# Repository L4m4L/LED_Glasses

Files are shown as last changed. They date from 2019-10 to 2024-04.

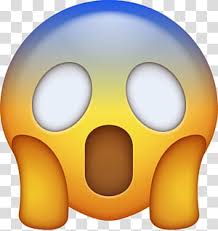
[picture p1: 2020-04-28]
scripts/wow.jpg

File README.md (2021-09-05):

# LED_Glasses
A hobby project aimed at making sound reactive LED glasses that you should take clubbing.

## Hardware

The hardware consists entirely of three PCBs without an enclosure with low profile hinges and a battery system that has yet to be worked out. The PCBs are designed in KiCAD and are as follows:

- The controller arm (`hardware/arm_mcu`) which houses the microcontroller (`STM32G071KBU6`), a microphone (`SPH0641LM4H-1`) and a 3v3 linear regulator.
- The power arm (`hardware/arm_power`) which houses input power protection, an on switch, 5v5 switching regulator and a power good indicator.
- The front display (`hardware/front_display`) which houses the LED matrix (`SK6812MINI`).

## Firmware

`firmware/arduino` contains an early revision of the firmware, with heavy modifications likely in future versions.

Hardware abstraction will be provided by either the STM HAL (pretty bloated and not very intuitive), STM LL (not very intuitive and a bit difficult to parse the many thousand line header files for insight), libopencm3 (haven't tried it but I've heard it's pretty good) or CMSIS (gives us the most control but literally no help haha) (i.e. we haven't decided yet but probably not Arduino).

## TODO

- Read https://github.com/EdwardHartmann/SK6812RGBW for inspiration
- Decide on copyright license
- Investigate smaller LED packages
-

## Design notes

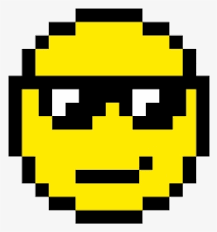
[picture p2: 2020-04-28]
scripts/glasses.png

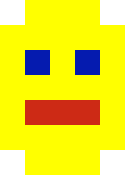
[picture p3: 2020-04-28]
scripts/custom.png

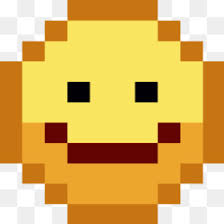
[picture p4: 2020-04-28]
scripts/smile.jpg

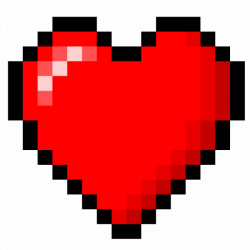
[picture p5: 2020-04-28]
scripts/heart.png

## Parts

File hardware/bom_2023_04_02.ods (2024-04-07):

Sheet: Summary
QTY | 5
 |  |  |  |  |  |  |  |  |  |  |  |  |  | 119.6005 | 71.202208
Type | Value | Package | Description | Board | Item QTY | Total QTY | Have | Remaining | Link | Retailer | Retailer Part Number | Manufacturer Part Number | Item Cost | Total Cost | Per One
buffer | 74LVCH2T45DC,125 | 8-VSSOP | Voltage Level Shifter, Bidirectional, Tri-State, 2 Channel | Controller B Rev 1 | 1 | 5 | 0 | 5 | https://www.digikey.com.au/en/products/detail/nexperia-usa-inc/74LVCH2T45DC-125/2530613 | digikey | 1727-4596-1-ND | 74LVCH2T45DC,125 | 0.9 | 4.5 | 0.9
capacitor | 100n | 0402 (1005) |  | Controller B Rev 1 | 13 | 65 | 100 | 0 | https://www.digikey.com.au/en/products/detail/murata-electronics/GRM155R62A104KE14D/5027543 | digikey | 490-10458-1-ND | GRM155R62A104KE14D | 0.0178 | 0 | 0.2314
capacitor | 100n | 0402 (1005) | 100V | Power Rev 2 | 5 | 25
capacitor | 10n | 0603 (1608) | 5%, 50V, C0G/NP0 | Power Rev 2 | 1 | 5 | 5 | 0 | https://www.digikey.com.au/en/products/detail/murata-electronics/GRM1885C1H103JA01D/4421555 | digikey | 490-9666-1-ND | GRM1885C1H103JA01D | 0.3 | 0 | 0.3
capacitor | 10p | 0402 (1005) | 1%, C0G/NP0 | Controller B Rev 1 | 2 | 10 | 10 | 0 | https://www.digikey.com.au/en/products/detail/yageo/CC0402FRNPO9BN100/5195049 | digikey | 311-1640-1-ND | CC0402FRNPO9BN100 | 0.104 | 0 | 0.208
capacitor | 1u | 0402 (1005) |  | Controller B Rev 1 | 4 | 20 | 50 | 0 | https://www.digikey.com.au/en/products/detail/murata-electronics/GRM155R61E105KA12J/4905140 | digikey | 490-GRM155R61E105KA12JCT-ND | GRM155R61E105KA12J | 0.0294 | 0 | 0.1176
capacitor | 1u | 0402 (1005) |  | Power Rev 2 | 1 | 5
capacitor | 1u | 0603 (1608) |  | Display B Rev 1 | 132 | 660 | 660 | 0 | https://www.digikey.com.au/en/products/detail/samsung-electro-mechanics/CL10B105KP8NFNC/3887603 | digikey | 1276-1945-1-ND | CL10B105KP8NFNC | 0.01334 | 0 | 1.76088
capacitor | 22u | 0805 (2012) |  | Power Rev 2 | 6 | 30 | 28 | 2 | https://www.digikey.com.au/en/products/detail/samsung-electro-mechanics/CL21A226MAYNNNE/10479857 | digikey | 1276-CL21A226MAYNNNECT-ND | CL21A226MAYNNNE | 0.274 | 0.548 | 1.644
capacitor | 2u2 | 1210 (3225) | 100V | Power Rev 2 | 3 | 15 | 15 | 0 | https://www.digikey.com.au/en/products/detail/samsung-electro-mechanics/CL32B225KCJSNNE/3889020 | digikey | 1276-3362-1-ND | CL32B225KCJSNNE | 0.469 | 0 | 1.407
capacitor | 3n9 | 0603 (1608) | 50V, 5%, C0G/NP0 | Power Rev 2 | 1 | 5 | 10 | 0 | https://www.digikey.com.au/en/products/detail/murata-electronics/GCM1885C1H392JA16D/4903747 | digikey | 490-11958-1-ND | GCM1885C1H392JA16D | 0.154 | 0 | 0.154
capacitor | 4u7 | 0402 (1005) |  | Power Rev 2 | 1 | 5 | 10 | 0 | https://www.digikey.com.au/en/products/detail/murata-electronics/GRM155C61E475ME15D/16821133 | digikey | 490-GRM155C61E475ME15DCT-ND | GRM155C61E475ME15D | 0.267 | 0 | 0.267
capacitor | 680p | 0603 (1608) | 50V, %5, C0G/NP0 | Power Rev 2 | 1 | 5 | 10 | 0 | https://www.digikey.com.au/en/products/detail/yageo/CC0603JRNPO9BN681/2833590 | digikey | 311-1425-1-ND | CC0603JRNPO9BN681 | 0.115 | 0 | 0.115
connector | CF35082D0RE-NH |  | 1x8, Female, 0.5 mm, FFC/FPC, SMD, Right Angle, ZIF | Controller B Rev 1 | 1 | 5 | 25 | 0 | https://www.digikey.com.au/en/products/detail/cvilux-usa/CF35082D0RE-NH/15793084 | digikey | 2987-CF35082D0RE-NHCT-ND | CF35082D0RE-NH | 0.3308 | 0 | 0.3308
connector | CF35082D0RE-NH |  | 1x8, Female, 0.5 mm, FFC/FPC, SMD, Right Angle, ZIF | Display B Rev 1 | 2 | 10 | 25 | 0 | https://www.digikey.com.au/en/products/detail/cvilux-usa/CF35082D0RE-NH/15793084 | digikey | 2987-CF35082D0RE-NHCT-ND | CF35082D0RE-NH | 0.3308 | 0 | 0.6616
connector | CF35082D0RE-NH |  | 1x8, Female, 0.5 mm, FFC/FPC, SMD, Right Angle, ZIF | Power Rev 2 | 1 | 5 | 25 | 0 | https://www.digikey.com.au/en/products/detail/cvilux-usa/CF35082D0RE-NH/15793084 | digikey | 2987-CF35082D0RE-NHCT-ND | CF35082D0RE-NH | 0.3308 | 0 | 0.3308
connector | S2B-PH-SM4-TB(LF)(SN) |  | 1x2, Male, 2mm, Header, SMD, Right Angle, Keyed, Shrouded | Power Rev 2 | 1 | 5 | 20 | 0 | https://au.element14.com/jst-japan-solderless-terminals/s2b-ph-sm4-tb-lf-sn/connector-header-smt-r-a-2mm-2way/dp/9492615 | element14 | 9492615 | S2B-PH-SM4-TB(LF)(SN) | 0.745 | 0 | 0.745
connector | 620102131822 |  | 1x2, Male, 2mm, Header, SMD, Right Angle, Keyed, Shrouded | Power Rev 2 | 0 | 0 | 2 | 0 | https://www.digikey.com.au/en/products/detail/würth-elektronik/620102131822/2508480 | digikey | 732-2711-1-ND | 620102131822 | 1.83 | 0
connector | 4048 |  | 2x5, Male, 1.27mm, Header, SMD, Vertical, Keyed, Shrouded | Controller B Rev 1 | 1 | 5 | 4 | 1 | https://www.digikey.com.au/en/products/detail/adafruit-industries-llc/4048/9843412 | digikey | 1528-2827-ND | 4048 | 3.16 | 3.16 | 3.16
connector | 10118192-0002LF |  | USB Micro B, SMD, Right Angle | Controller B Rev 1 | 1 | 5 | 5 | 0 | https://www.digikey.com.au/en/products/detail/amphenol-cs-fci/10118192-0002LF/6817756 | digikey | 609-5379-1-ND | 10118192-0002LF | 0.67 | 0 | 0.67
crystal | ECS-120-10-36B2-CWY-TR |  | 12MHz, 10 pF, 130 ohm, 15 ppm | Controller B Rev 1 | 1 | 5 | 5 | 0 | https://www.digikey.com.au/en/products/detail/ecs-inc/ECS-120-10-36B2-CWY-TR/14548848 | digikey | 50-ECS-120-10-36B2-CWY-TRCT-ND | ECS-120-10-36B2-CWY-TR | 0.65 | 0 | 0.65
diode | D5V0L1B2WS-7 | SOD-323 | TVS Diode, 14V | Power Rev 2 | 1 | 5 | 0 | 5 | https://www.digikey.com.au/en/products/detail/diodes-incorporated/D5V0L1B2WS-7/2918767 | digikey | D5V0L1B2WS-7DICT-ND | D5V0L1B2WS-7 | 0.47 | 2.35 | 0.47
diode | SBRT05U20LPS-7B | 0402 (1005) | Diode, 390 mV @ 500 mA | Controller B Rev 1 | 3 | 15 | 15 | 0 | https://www.digikey.com.au/en/products/detail/diodes-incorporated/SBRT05U20LPS-7B/7666996 | digikey | SBRT05U20LPS-7BDICT-ND | SBRT05U20LPS-7B | 0.483 | 0 | 1.449
fuse | SBF32302ASTP | 1206 (3216) | 3A, 32V, 24mOhms | Power Rev 2 | 1 | 5 | 10 | 0 | https://www.digikey.com.au/en/products/detail/kamaya-inc/SBF32302ASTP/15181289 | digikey | 2315-SBF32302ASTPCT-ND | SBF32302ASTP | 0.332 | 0 | 0.332
inductor | 15u |  |  | Power Rev 2 | 1 | 5 | 5 | 0 | https://www.digikey.com.au/en/products/detail/kemet/MPXV1D1054L150/11314646 | digikey | 399-MPXV1D1054L150CT-ND | MPXV1D1054L150 | 2.62 | 0 | 2.62
led | APA102-2020 |  |  | Display B Rev 1 | 150 | 750 | 200 | 550 | https://www.aliexpress.com/item/10000013471219.html | aliexpress |  |  | 0.18935 | 104.1425 | 28.4025
memory | W25Q16JVZPIQ | 8-WSON (6x5 mm) | Flash, NOR, 16Mbit, Quad SPI, 133 MHz | Controller B Rev 1 | 1 | 5 | 0 | 5 | https://www.digikey.com.au/en/products/detail/winbond-electronics/W25Q16JVZPIQ/6193770 | digikey | W25Q16JVZPIQ-ND | W25Q16JVZPIQ | 0.98 | 4.9 | 0.98
microcontroller | RP2040 | QFN-56 (7x7mm) | ARM Cortex-M0+, 133 MHz | Controller B Rev 1 | 1 | 5 | 20 | 0 | https://www.digikey.com.au/en/products/detail/raspberry-pi/SC0914-7/14306009 | digikey | 2648-SC0914(7)CT-ND | SC0914(7) | 1.25 | 0 | 1.25
microphone | SPK0641HT4H-1 |  | MEMS Microphone, PDM, 20 – 20000 Hz | Controller B Rev 1 | 1 | 5 | 6 | 0 | https://www.digikey.com.au/en/products/detail/knowles/SPK0641HT4H-1/8573345 | digikey | 423-1425-1-ND | SPK0641HT4H-1 | 2.43 | 0 | 2.43
mosfet | AONR21357 | 8-PowerVDFN |  | Power Rev 2 | 1 | 5 | 5 | 0 | https://www.digikey.com.au/en/products/detail/alpha-omega-semiconductor-inc/AONR21357/9664230 | digikey | 785-AONR21357CT-ND | AONR21357 | 1.09 | 0 | 1.09
mosfet | SSM6N7002KFU,LF | 6-TSSOP | N MOSFET, 2 Channel, Vgs = 2.1V, SOT-363 | Controller B Rev 1 | 1 | 5 | 5 | 0 | https://www.digikey.com.au/en/products/detail/toshiba-semiconductor-and-storage/SSM6N7002KFU-LF/5810234 | digikey | SSM6N7002KFULFCT-ND | SSM6N7002KFU,LF | 0.39 | 0 | 0.39
mov | MLVA06V26C100-R | 0603 (1608) |  | Power Rev 2 | 1 | 5 | 10 | 0 | https://www.digikey.com.au/en/products/detail/eaton-electronics-division/MLVA06V26C100-R/5964319 | digikey | 283-4667-1-ND | MLVA06V26C100-R | 0.454 | 0 | 0.454
resistor | 10k | 0402 (1005) | 1%, | Controller B Rev 1 | 3 | 15 | 100 | 0 | https://www.digikey.com.au/en/products/detail/bourns-inc/CR0402-FX-1002GLF/3593192 | digikey | CR0402-FX-1002GLFCT-ND | CR0402-FX-1002GLF | 0.0087 | 0 | 0.0261
resistor | 10k | 0402 (1005) | 1%, | Power Rev 2 | 4 | 20
resistor | 15k | 0402 (1005) | 1%, | Controller B Rev 1 | 1 | 5 | 10 | 0 | https://www.digikey.com.au/en/products/detail/yageo/RC0402FR-0715KL/726541 | digikey | 311-15.0KLRCT-ND | RC0402FR-0715KL | 0.023 | 0 | 0.023
resistor | 160k | 0402 (1005) | 1%, | Power Rev 2 | 1 | 5 | 10 | 0 | https://www.digikey.com.au/en/products/detail/stackpole-electronics-inc/RMCF0402FT160K/1714462 | digikey | RMCF0402FT160KCT-ND | RMCF0402FT160K | 0.022 | 0 | 0.022
resistor | 18k | 0402 (1005) | 1%, | Power Rev 2 | 1 | 5 | 10 | 0 | https://www.digikey.com.au/en/products/detail/yageo/RC0402FR-0718KL/726548 | digikey | 311-18.0KLRCT-ND | RC0402FR-0718KL | 0.023 | 0 | 0.023
resistor | 1k | 0402 (1005) | 1%, | Controller B Rev 1 | 2 | 10 | 10 | 0 | https://www.digikey.com.au/en/products/detail/yageo/AC0402FR-131KL/14008372 | digikey | 13-AC0402FR-131KLCT-ND | AC0402FR-131KL | 0.03 | 0 | 0.06
resistor | 27R | 0402 (1005) | 1%, | Controller B Rev 1 | 2 | 10 | 10 | 0 | https://www.digikey.com.au/en/products/detail/yageo/RC0402FR-0727RL/5280946 | digikey | YAG3086CT-ND | RC0402FR-0727RL | 0.023 | 0 | 0.046
resistor | 300k | 0402 (1005) | 0.5%, | Power Rev 2 | 1 | 5 | 10 | 0 | https://www.digikey.com.au/en/products/detail/koa-speer-electronics-inc/RK73H1ETTP3003D/9853472 | digikey | 2019-RK73H1ETTP3003DCT-ND | RK73H1ETTP3003D | 0.371 | 0 | 0.371
resistor | 390k | 0402 (1005) | 1%, | Power Rev 2 | 1 | 5 | 10 | 0 | https://www.digikey.com.au/en/products/detail/yageo/RC0402FR-07390KL/5281003 | digikey | YAG3143CT-ND | RC0402FR-07390KL | 0.023 | 0 | 0.023
resistor | 3R3 | 0402 (1005) | 1%, | Power Rev 2 | 1 | 5 | 10 | 0 | https://www.digikey.com.au/en/products/detail/yageo/RC0402FR-073R3L/1037049 | digikey | 311-3.30LRCT-ND | RC0402FR-073R3L | 0.033 | 0 | 0.033
resistor | 47k5 | 0402 (1005) | 1%, | Power Rev 2 | 1 | 5 | 10 | 0 | https://www.digikey.com.au/en/products/detail/yageo/RC0402FR-0747K5L/726617 | digikey | 311-47.5KLRCT-ND | RC0402FR-0747K5L | 0.023 | 0 | 0.023
resistor | 52k3 | 0402 (1005) | 1%, | Power Rev 2 | 1 | 5 | 10 | 0 | https://www.digikey.com.au/en/products/detail/yageo/RC0402FR-0752K3L/5281039 | digikey | YAG3179CT-ND | RC0402FR-0752K3L | 0.023 | 0 | 0.023
resistor | 62k | 0402 (1005) | 1%, | Power Rev 2 | 1 | 5 | 10 | 0 | https://www.digikey.com.au/en/products/detail/yageo/RC0402FR-0762KL/726645 | digikey | 311-62.0KLRCT-ND | RC0402FR-0762KL | 0.023 | 0 | 0.023
resistor | 75k | 0402 (1005) | 1%, | Controller B Rev 1 | 1 | 5 | 10 | 0 | https://www.digikey.com.au/en/products/detail/bourns-inc/CR0402-FX-7502GLF/3783488 | digikey | CR0402-FX-7502GLFCT-ND | CR0402-FX-7502GLF | 0.019 | 0 | 0.019
resistor | 88k7 | 0402 (1005) | 1%, | Power Rev 2 | 1 | 5 | 10 | 0 | https://www.digikey.com.au/en/products/detail/yageo/RC0402FR-0788K7L/726667 | digikey | 311-88.7KLRCT-ND | RC0402FR-0788K7L | 0.023 | 0 | 0.023
resistor | 8k66 | 0402 (1005) | 1%, | Power Rev 2 | 1 | 5 | 10 | 0 | https://www.digikey.com.au/en/products/detail/yageo/RC0402FR-078K66L/5281115 | digikey | YAG3255CT-ND | RC0402FR-078K66L | 0.023 | 0 | 0.023
resistor array | 10k | 0804 Convex | 4x Resistor Array, Isolated | Controller B Rev 1 | 1 | 5 | 5 | 0 | https://www.digikey.com.au/en/products/detail/panasonic-electronic-components/EXB-28V103JX/256299 | digikey | Y7103CT-ND | EXB-28V103JX | 0.16 | 0 | 0.16
switch | User Buttons |  | Tactile, SMD, Right Angle, SPSP-NO | Controller B Rev 1 | 2 | 10 | 10 | 0 | https://www.digikey.com.au/en/products/detail/panasonic-electronic-components/EVQ-P7A01P/4429447 | digikey | P16763CT-ND | EVQ-P7A01P | 0.464 | 0 | 0.928
voltage regulator | 3V3 Linear Regulator | TSOT-23-5 | 300 mA | Controller B Rev 1 | 1 | 5 | 5 | 0 | https://www.digikey.com.au/en/products/detail/onsemi/NCP115ASN330T2G/9764776 | digikey | NCP115ASN330T2GOSCT-ND | NCP115ASN330T2G | 0.53 | 0 | 0.53
voltage regulator | SIC473 | Vishay PowerPAK MLP55-27 |  | Power Rev 2 | 1 | 5 | 5 | 0 | https://www.digikey.com.au/en/products/detail/vishay-siliconix/SIC473ED-T1-GE3/9556547 | digikey | SIC473ED-T1-GE3CT-ND | SIC473ED-T1-GE3 | 5.44 | 0 | 5.44
cable | MP-FFCA05080502A |  | 1x8, Male, 0.5 mm, FFC/FPC, 50mm, Same Sided Contacts |  | 2 | 10 | 50 | 0 | https://au.element14.com/multicomp-pro/mp-ffca05080502a/ffc-cord-8p-same-side-50mm-wht/dp/3385165 | element14 | 3385165 | MP-FFCA05080502A | 1.39 | 0 | 2.78
cable | 151660075 |  | 1x8, Male, 0.5 mm, FFC/FPC, 50mm, Same Sided Contacts |  | 0 | 0 | 2 | 0 | https://www.digikey.com.au/en/products/detail/molex/0151660075/3280957 | digikey | WM11299-ND | 151660075 | 3.76 | 0 | 0
cable | 151660073 |  | 1x8, Male, 0.5 mm, FFC/FPC, 30mm, Same Sided Contacts |  | 0 | 0 | 2 | 0 | https://www.digikey.com.au/en/products/detail/molex/0151660075/3280957 | digikey | 0151660073-ND | 151660073 | 3.76 | 0 | 0
screws |  |  | M1.4x3.5mm |  | 8 | 40 | 100 | 0 | https://www.aliexpress.com/item/10000181324125.html | aliexpress |  |  | 0.0207 | 0 | 0.1656
hinges |  |  |  |  | 2 | 10 | 60 | 0 | https://www.aliexpress.com/item/1005003373487703.html | aliexpress |  |  | 0.222 | 0 | 0.444

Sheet: Controller B Rev 1
Type | Value | Package | Description | Link | Retailer Part Number | Manufacturer Part Number | Item QTY | Reference Designator
capacitor | 1u | 0402 (1005) |  | https://www.digikey.com.au/en/products/detail/murata-electronics/GRM155R61E105KA12J/4905140 | 490-GRM155R61E105KA12JCT-ND | GRM155R61E105KA12J | 4 | C101, C102, C105, C106
capacitor | 100n | 0402 (1005) |  | https://www.digikey.com.au/en/products/detail/murata-electronics/GRM155R62A104KE14D/5027543 | 490-10458-1-ND | GRM155R62A104KE14D | 13 | C103, C104, C107, C108, C109, C110, C111, C112, C113, C114, C115, C116, C117
capacitor | 10p | 0402 (1005) | 1%, C0G/NP0 | https://www.digikey.com.au/en/products/detail/yageo/CC0402FRNPO9BN100/5195049 | 311-1640-1-ND | CC0402FRNPO9BN100 | 2 | C118, C119
diode | SBRT05U20LPS-7B | 0402 (1005) | Diode, 390 mV @ 500 mA | https://www.digikey.com.au/en/products/detail/diodes-incorporated/SBRT05U20LPS-7B/7666996 | SBRT05U20LPS-7BDICT-ND | SBRT05U20LPS-7B | 3 | D101, D102, D103
connector | CF35082D0RE-NH |  | 1x8, Female, 0.5 mm, FFC/FPC, SMD, Right Angle, ZIF | https://www.digikey.com.au/en/products/detail/cvilux-usa/CF35082D0RE-NH/15793084 | 2987-CF35082D0RE-NHCT-ND | CF35082D0RE-NH | 1 | J101
connector | 4048 |  | 2x5, Male, 1.27mm, Header, SMD, Vertical, Keyed, Shrouded | https://www.digikey.com.au/en/products/detail/adafruit-industries-llc/4048/9843412 | 1528-2827-ND | 4048 | 1 | J102
connector | 10118192-0002LF |  | USB Micro B, SMD, Right Angle | https://www.digikey.com.au/en/products/detail/amphenol-cs-fci/10118192-0002LF/6817756 | 609-5379-1-ND | 10118192-0002LF | 1 | J103
microphone | SPK0641HT4H-1 | SMD | MEMS Microphone, PDM, 20 – 20000 Hz | https://www.digikey.com.au/en/products/detail/knowles/SPK0641HT4H-1/8573345 | 423-1425-1-ND | SPK0641HT4H-1 | 1 | MK101
mosfet | SSM6N7002KFU,LF | 6-TSSOP | N MOSFET, 2 Channel, Vgs = 2.1V, SOT-363 | https://www.digikey.com.au/en/products/detail/toshiba-semiconductor-and-storage/SSM6N7002KFU-LF/5810234 | SSM6N7002KFULFCT-ND | SSM6N7002KFU,LF | 1 | Q101
resistor | 75k | 0402 (1005) | 1%, | https://www.digikey.com.au/en/products/detail/bourns-inc/CR0402-FX-7502GLF/3783488 | CR0402-FX-7502GLFCT-ND | CR0402-FX-7502GLF | 1 | R101
resistor | 10k | 0402 (1005) | 1%, | https://www.digikey.com.au/en/products/detail/bourns-inc/CR0402-FX-1002GLF/3593192 | CR0402-FX-1002GLFCT-ND | CR0402-FX-1002GLF | 3 | R102, R106, R107
resistor | 27R | 0402 (1005) | 1%, | https://www.digikey.com.au/en/products/detail/yageo/RC0402FR-0727RL/5280946 | YAG3086CT-ND | RC0402FR-0727RL | 2 | R104, R105
resistor | 1k | 0402 (1005) | 1%, | https://www.digikey.com.au/en/products/detail/yageo/AC0402FR-131KL/14008372 | 13-AC0402FR-131KLCT-ND | AC0402FR-131KL | 2 | R108, R109
resistor | 15k | 0402 (1005) | 1%, | https://www.digikey.com.au/en/products/detail/yageo/RC0402FR-0715KL/726541 | 311-15.0KLRCT-ND | RC0402FR-0715KL | 1 | R110
resistor array | 10k | 0804 Convex | 4x Resistor Array, Isolated | https://www.digikey.com.au/en/products/detail/panasonic-electronic-components/EXB-28V103JX/256299 | Y7103CT-ND | EXB-28V103JX | 1 | RN101
switch | EVQ-P7A01P | SMD, Right Angle | Tactile, SPSP-NO | https://www.digikey.com.au/en/products/detail/panasonic-electronic-components/EVQ-P7A01P/4429447 | P16763CT-ND | EVQ-P7A01P | 2 | SW101, SW102
voltage regulator | NCP115ASN330T2G | TSOT-23-5 | Linear Regulator, 3.3 V, 300 mA | https://www.digikey.com.au/en/products/detail/onsemi/NCP115ASN330T2G/9764776 | NCP115ASN330T2GOSCT-ND | NCP115ASN330T2G | 1 | U101
buffer | 74LVCH2T45DC,125 | 8-VSSOP | Voltage Level Shifter, Bidirectional, Tri-State, 2 Channel | https://www.digikey.com.au/en/products/detail/nexperia-usa-inc/74LVCH2T45DC-125/2530613 | 1727-4596-1-ND | 74LVCH2T45DC,125 | 1 | U102
buffer | 74LVC2T45HK3-7 | 8-XFDFN | Voltage Level Shifter, Bidirectional, Tri-State, 2 Channel | https://www.digikey.com.au/en/products/detail/diodes-incorporated/74LVC2T45HK3-7/13684787 | 31-74LVC2T45HK3-7CT-ND | 74LVC2T45HK3-7 | 0 | ~
microcontroller | RP2040 | QFN-56 (7x7mm) | ARM Cortex-M0+, 133 MHz | https://www.digikey.com.au/en/products/detail/raspberry-pi/SC0914-7/14306009 | 2648-SC0914(7)CT-ND | SC0914(7) | 1 | U103
memory | W25Q16JVZPIQ | 8-WSON (6x5 mm) | Flash, NOR, 16Mbit, Quad SPI, 133 MHz | https://www.digikey.com.au/en/products/detail/winbond-electronics/W25Q16JVZPIQ/6193770 | W25Q16JVZPIQ-ND | W25Q16JVZPIQ | 1 | U104
memory | W25Q16JVUXIQ | 8-USON | Flash, NOR, 16Mbit, Quad SPI, 133 MHz | https://www.digikey.com.au/en/products/detail/winbond-electronics/W25Q16JVUXIQ-TR/15182017 | 256-W25Q16JVUXIQTRCT-ND | W25Q16JVUXIQ TR | 0 | ~
crystal | ECS-120-10-36B2-CWY-TR |  | 12MHz, 10 pF, 130 ohm, 15 ppm | https://www.digikey.com.au/en/products/detail/ecs-inc/ECS-120-10-36B2-CWY-TR/14548848 | 50-ECS-120-10-36B2-CWY-TRCT-ND | ECS-120-10-36B2-CWY-TR | 1 | Y101

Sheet: Display B Rev 1
Type | Value | Package | Description | Link | Retailer Part Number | Manufacturer Part Number | Item QTY | Reference Designator
capacitor | 1u | 0603 (1608) |  | https://www.digikey.com.au/en/products/detail/samsung-electro-mechanics/CL10B105KP8NFNC/3887603 | 1276-1945-1-ND | CL10B105KP8NFNC | 132 | C101, C102, C103, C104, C105, C106, C107, C108, C109, C110, C111, C112, C113, C114, C115, C116, C117, C118, C119, C120, C121, C122, C123, C124, C125, C126, C127, C128, C129, C130, C131, C132, C133, C134, C135, C136, C137, C138, C139, C140, C141, C142, C143, C144, C145, C146, C147, C148, C149, C150, C151, C152, C153, C154, C155, C156, C157, C158, C159, C160, C161, C162, C163, C164, C165, C166, C167, C168, C169, C170, C171, C172, C173, C174, C175, C176, C177, C178, C179, C180, C181, C182, C183, C184, C185, C186, C187, C188, C189, C190, C191, C192, C193, C194, C195, C196, C197, C198, C199, C200, C201, C202, C203, C204, C205, C206, C207, C208, C209, C210, C211, C212, C213, C214, C215, C216, C217, C218, C219, C220, C221, C222, C223, C224, C225, C226, C227, C228, C229, C230, C231, C232
connector | CF35082D0RE-NH |  | 1x8, Female, 0.5 mm, FFC/FPC, SMD, Right Angle, ZIF | https://www.digikey.com.au/en/products/detail/cvilux-usa/CF35082D0RE-NH/15793084 | 2987-CF35082D0RE-NHCT-ND | CF35082D0RE-NH | 150 | D101, D102, D103, D104, D107, D108, D109, D110, D111, D112, D113, D114, D115, D116, D117, D118, D119, D120, D121, D122, D123, D124, D125, D126, D127, D128, D129, D130, D131, D132, D133, D134, D135, D136, D137, D138, D139, D140, D142, D143, D144, D145, D146, D147, D148, D149, D151, D152, D153, D154, D155, D156, D157, D158, D160, D161, D162, D163, D164, D165, D166, D167, D169, D170, D172, D173, D174, D175, D176, D178, D179, D180, D182, D183, D185, D187, D188, D189, D191, D192, D193, D194, D195, D196, D197, D199, D200, D202, D203, D204, D205, D206, D207, D208, D209, D210, D211, D212, D213, D214, D215, D216, D217, D218, D219, D220, D221, D222, D223, D224, D225, D226, D228, D229, D230, D231, D232, D233, D234, D235, D237, D238, D239, D240, D241, D242, D243, D244, D246, D247, D248, D249, D250, D251, D252, D253, D255, D256, D257, D258, D259, D260, D261, D262, D264, D265, D266, D267, D270, D271
led | APA102-2020 |  |  | https://www.aliexpress.com/item/10000013471219.html |  |  | 2 | J101, J102

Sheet: Power Rev 2
Type | Value | Package | Description | Link | Retailer Part Number | Manufacturer Part Number | Item QTY | Reference Designator
capacitor | 2u2 | 1210 (3225) | 100V | https://www.digikey.com.au/en/products/detail/samsung-electro-mechanics/CL32B225KCJSNNE/3889020 | 1276-3362-1-ND | CL32B225KCJSNNE | 3 | C101, C102, C103
capacitor | 100n | 0402 (1005) | 100V | https://www.digikey.com.au/en/products/detail/murata-electronics/GRM155R62A104KE14D/5027543 | 490-10458-1-ND | GRM155R62A104KE14D | 5 | C104, C105, C106, C118, C119
capacitor | 22u | 0805 (2012) |  | https://www.digikey.com.au/en/products/detail/samsung-electro-mechanics/CL21A226MAYNNNE/10479857 | 1276-CL21A226MAYNNNECT-ND | CL21A226MAYNNNE | 6 | C107, C108, C109, C110, C111, C112
capacitor | 10n | 0603 (1608) | 5%, 50V, C0G/NP0 | https://www.digikey.com.au/en/products/detail/murata-electronics/GRM1885C1H103JA01D/4421555 | 490-9666-1-ND | GRM1885C1H103JA01D | 1 | C113
capacitor | 4u7 | 0402 (1005) |  | https://www.digikey.com.au/en/products/detail/murata-electronics/GRM155C61E475ME15D/16821133 | 490-GRM155C61E475ME15DCT-ND | GRM155C61E475ME15D | 1 | C114
capacitor | 1u | 0402 (1005) |  | https://www.digikey.com.au/en/products/detail/murata-electronics/GRM155R61E105KA12J/4905140 | 490-GRM155R61E105KA12JCT-ND | GRM155R61E105KA12J | 1 | C115
capacitor | 3n9 | 0603 (1608) | 50V, 5%, C0G/NP0 | https://www.digikey.com.au/en/products/detail/murata-electronics/GCM1885C1H392JA16D/4903747 | 490-11958-1-ND | GCM1885C1H392JA16D | 1 | C116
capacitor | 680p | 0603 (1608) | 50V, %5, C0G/NP0 | https://www.digikey.com.au/en/products/detail/yageo/CC0603JRNPO9BN681/2833590 | 311-1425-1-ND | CC0603JRNPO9BN681 | 1 | C117
diode | D5V0L1B2WS-7 | SOD-323 | TVS Diode, 14V | https://www.digikey.com.au/en/products/detail/diodes-incorporated/D5V0L1B2WS-7/2918767 | D5V0L1B2WS-7DICT-ND | D5V0L1B2WS-7 | 1 | D101
diode | ESDA17P20-1F2 | SOD-882 | TVS Diode, 15V | https://www.digikey.com.au/en/products/detail/stmicroelectronics/ESDA17P20-1F2/13592620 | 497-ESDA17P20-1F2CT-ND | ESDA17P20-1F2 | 0 | ~
fuse | SBF32302ASTP | 1206 (3216) | 3A, 32V, 24mOhms | https://www.digikey.com.au/en/products/detail/kamaya-inc/SBF32302ASTP/15181289 | 2315-SBF32302ASTPCT-ND | SBF32302ASTP | 1 | F101
connector | CF35082D0RE-NH |  | 1x8, Female, 0.5 mm, FFC/FPC, SMD, Right Angle, ZIF | https://www.digikey.com.au/en/products/detail/cvilux-usa/CF35082D0RE-NH/15793084 | 2987-CF35082D0RE-NHCT-ND | CF35082D0RE-NH | 1 | J101
connector | S2B-PH-SM4-TB(LF)(SN) |  | 1x2, Male, 2mm, Header, SMD, Right Angle, Keyed, Shrouded | https://au.element14.com/jst-japan-solderless-terminals/s2b-ph-sm4-tb-lf-sn/connector-header-smt-r-a-2mm-2way/dp/9492615 | 9492615 | S2B-PH-SM4-TB(LF)(SN) | 1 | J102
inductor | 15u |  |  | https://www.digikey.com.au/en/products/detail/kemet/MPXV1D1054L150/11314646 | 399-MPXV1D1054L150CT-ND | MPXV1D1054L150 | 1 | L101
mosfet | AONR21357 | 8-PowerVDFN |  | https://www.digikey.com.au/en/products/detail/alpha-omega-semiconductor-inc/AONR21357/9664230 | 785-AONR21357CT-ND | AONR21357 | 1 | Q101
resistor | 10k | 0402 (1005) | 1%, | https://www.digikey.com.au/en/products/detail/bourns-inc/CR0402-FX-1002GLF/3593192 | CR0402-FX-1002GLFCT-ND | CR0402-FX-1002GLF | 4 | R101, R107, R109, R114
resistor | 8k66 | 0402 (1005) | 1%, | https://www.digikey.com.au/en/products/detail/yageo/RC0402FR-078K66L/5281115 | YAG3255CT-ND | RC0402FR-078K66L | 1 | R102
resistor | 47k5 | 0402 (1005) | 1%, | https://www.digikey.com.au/en/products/detail/yageo/RC0402FR-0747K5L/726617 | 311-47.5KLRCT-ND | RC0402FR-0747K5L | 1 | R103
resistor | 52k3 | 0402 (1005) | 1%, | https://www.digikey.com.au/en/products/detail/yageo/RC0402FR-0752K3L/5281039 | YAG3179CT-ND | RC0402FR-0752K3L | 1 | R104
resistor | 62k | 0402 (1005) | 1%, | https://www.digikey.com.au/en/products/detail/yageo/RC0402FR-0762KL/726645 | 311-62.0KLRCT-ND | RC0402FR-0762KL | 1 | R105
resistor | 3R3 | 0402 (1005) | 1%, | https://www.digikey.com.au/en/products/detail/yageo/RC0402FR-073R3L/1037049 | 311-3.30LRCT-ND | RC0402FR-073R3L | 1 | R106
resistor | 18k | 0402 (1005) | 1%, | https://www.digikey.com.au/en/products/detail/yageo/RC0402FR-0718KL/726548 | 311-18.0KLRCT-ND | RC0402FR-0718KL | 1 | R108
resistor | 160k | 0402 (1005) | 1%, | https://www.digikey.com.au/en/products/detail/stackpole-electronics-inc/RMCF0402FT160K/1714462 | RMCF0402FT160KCT-ND | RMCF0402FT160K | 1 | R110
resistor | 390k | 0402 (1005) | 1%, | https://www.digikey.com.au/en/products/detail/yageo/RC0402FR-07390KL/5281003 | YAG3143CT-ND | RC0402FR-07390KL | 1 | R111
resistor | 88k7 | 0402 (1005) | 1%, | https://www.digikey.com.au/en/products/detail/yageo/RC0402FR-0788K7L/726667 | 311-88.7KLRCT-ND | RC0402FR-0788K7L | 1 | R112
resistor | 300k | 0402 (1005) | 0.5%, | https://www.digikey.com.au/en/products/detail/koa-speer-electronics-inc/RK73H1ETTP3003D/9853472 | 2019-RK73H1ETTP3003DCT-ND | RK73H1ETTP3003D | 1 | R113
mov | MLVA06V26C100-R | 0603 (1608) |  | https://www.digikey.com.au/en/products/detail/eaton-electronics-division/MLVA06V26C100-R/5964319 | 283-4667-1-ND | MLVA06V26C100-R | 1 | RV101
voltage regulator | SIC473 | Vishay PowerPAK MLP55-27 |  | https://www.digikey.com.au/en/products/detail/vishay-siliconix/SIC473ED-T1-GE3/9556547 | SIC473ED-T1-GE3CT-ND | SIC473ED-T1-GE3 | 1 | U101
connector | 620102131822 |  | 1x2, Male, 2mm, Header, SMD, Right Angle, Keyed, Shrouded | https://www.digikey.com.au/en/products/detail/würth-elektronik/620102131822/2508480 | 732-2711-1-ND | 620102131822 | 0

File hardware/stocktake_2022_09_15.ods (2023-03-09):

type | desc pri | desc sec | qty | retailer | part number | package | package imp | package metric | link
bjt | npn |  | 5 | digikey | mmbt3904tpmsct-nd | sot23
button | tactile spst | spst-no vertical | 4 | digikey | ckn10779ct-nd | 3x2mm
button | tactile spst | spst-no vertical | 1 | digikey | pts647sm50smtr2lfsct-nd | 4.5x4.5x5mm
capacitor | 100n | 50v x7r 20% | 128 | digikey | 1276-2450-1-nd |  | 805 | 2012
capacitor | 100n | 25v x7r 20% | 7 | mouser | 80-c0805c104m3r |  | 805 | 2012
capacitor | 10n | 50v x7r | 9 | digikey | 1276-1015-1-nd |  | 805 | 2012
capacitor | 10p | 50v c0g/np0 | 8 | digikey | 1276-1109-1-nd |  | 805 | 2012
capacitor | 10u | 50v x5r 20% | 6 | digikey | 1276-6736-1-nd |  | 1206 | 3216
capacitor | 2n2 | 50v x7r | 9 | digikey | 399-1151-1-nd |  | 805 | 2012
capacitor | 22u | 25v x5r 20% | 28 | mouser | 81-grm21br61e226me4k |  | 805 | 2012
capacitor | 4u7 | 25v x5r 10% | 12 | digikey | 1276-1244-1-nd |  | 805 | 2012
connector | micro sd | hinged smt | 1 | digikey | 2073-mem2067-02-180-00-act-nd
connector | usb micro b | smt | 1 | digikey | 609-4618-1-nd
crystal | 12mhz | 25ppm 10pf 150r | 1 | digikey | xc2722ct-nd | 4-smd |  | 2.5x2
diode schottky | 0a5 | vf 0.385v | 7 | digikey | mbr0520lt1gosct-nd | sod-123
diode schottky | 4a | vf 0.660v | 1 | digikey | nrvtsa4100t3gosct-nd | do-214ac
diode tvs | 24v |  | 1 | digikey | nup2105lt1gosct-nd | sot-23-3
diode tvs | 5v25 | usb protection | 1 | digikey | 497-5235-1-nd | sot23-6
diode tvs | 5v | 3a vclamp 7.2v | 7 | mouser | 621-desd5v0u1ba-7 | sod-323-2
fuse | 2a | 0.068r fast blow | 7 | mouser | 530-c1f2 |  | 1206
header | 2-pin | terminal block screw 3.5mm pitch | 1 | digikey | 277-1721-nd
header | 2-pin male | jst-ph 2-pin smt shrouded keyed | 2 | mouser | 485-1769
header | 4-pin | terminal block screw 3.5mm pitch | 1 | digikey | 277-1860-nd
header | double row 0.1” pitch male | 2x10 vertical through hole | 1 | digikey
header | single row 0.1” pitch female | 8pos vertical through hole | 2 | digikey | s7006-nd
header | single row 0.1” pitch male | 1x20 vertical through hole | 1 | digikey
ic | thermocouple to digital converter |  | 1 | digikey | max31855kasa+tct-nd | 8-soic
ic | thermocouple to digital converter | max31855 | 1 | digikey | max31855kasa+tct-nd | 8-soic
ic | uart to usb converter | ft232rl | 1
inductor | 15u | 3.6a 0.05r 20% | 1 | digikey | srn8040ta-150mct-nd | 8x8mm
inductor | 1u | 3.6a 0.0252r 30% | 7 | mouser | 963-nrs5020t1r0nmgj |  |  | 4.9x4.9
led | apa102 | spi 2020 | 200 | aliexpress |  | 2x2mm |  |  | https://www.aliexpress.com/i/10000013471219.html
led | blue |  | 3 | digikey | 732-4982-1-nd |  | 805 | 2012
led | green | 40mcd | 7 | mouser | 710-150080vs75000 |  | 805 | 2012
led | green |  | 3 | digikey | 732-4986-1-nd |  | 805 | 2012
led | red |  | 4 | digikey | 732-4984-1-nd |  | 805 | 2012
led | sk6812mini | 200mw pwm | ~260 | aliexpress |  | 3.5x3.7x0.95mm
microcontroller | stm32g071kbu6 |  | 2 | digikey | 479-18357-nd
microphone | bottom port, digital, pdm |  | 2 | digikey | 423-1395-1-nd
mosfet | 1 p-channel | vds 12v id 3a vth 0.9v | 6 | mouser | 781-si2315bds-ge3 | to-236-3
mosfet | 2 n-channel | vds 60v id 0.3a vth 2.1v | 2 | digikey | ssm6n7002kfulfct-nd | 6-tssop
piezo buzzer |  |  | 1 | digikey | 490-4698-1-nd | through hole
resistor | 270 | 100mw 0.5% | 7 | mouser | 754-rr1220p-271d |  | 805 | 2012
resistor | 1000k | 125mw 0.5% | 7 | mouser | 667-era-6aed105v |  | 805 | 2012
resistor | 100k | 1/8w 1% | 29 | digikey | rmcf0805ft100kct-nd |  | 805 | 2012
resistor | 15k | 1/8w 1% | 6 | digikey | a129763ct-nd |  | 805 | 2012
resistor | 1k5 | 1/8w 1% | 7 | digikey | a106057ct-nd |  | 805 | 2012
resistor | 270r | 1/8w 1% | 16 | digikey | 311-270crct-nd |  | 805 | 2012
resistor | 5k6 | 1/8w 1% | 7 | digikey | a126380ct-nd |  | 805 | 2012
switch | slide dpdt | 300ma 6v | 7 | digikey | 401-2002-1-nd
voltage regulator | 3v3 | linear 0.3a vin 3v5-5v5 | 3 | digikey | 576-4764-1-nd | sot-23-5
voltage regulator | 5v switching | boost-buck 2.25a vin 2.5-12v 2.4mhz | 2 | mouser | 595-tps63061dscr | wson-10

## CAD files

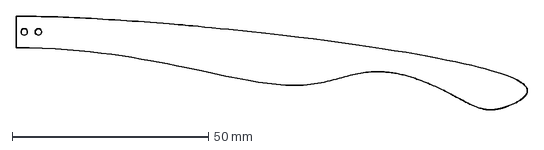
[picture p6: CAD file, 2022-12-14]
hardware/template_arm_b_r1/template_arm_b_r1_2.dxf
130.2 x 23.8 mm

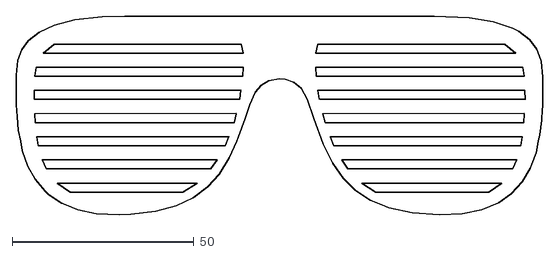
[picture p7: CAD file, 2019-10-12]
hardware/template_display_a_r1/display_template_a_r1.dxf
144.7 x 54.6

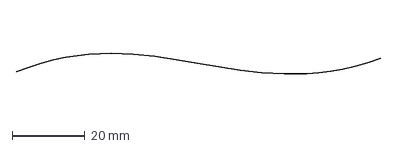
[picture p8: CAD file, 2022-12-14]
hardware/template_display_b_r1/test2.dxf
100.3 x 25.3 mm

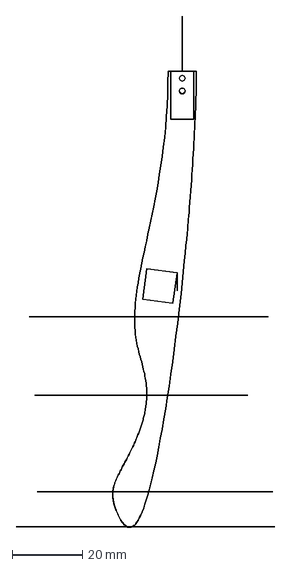
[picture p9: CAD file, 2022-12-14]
hardware/template_arm_b_r1/template_arm_b_r1.dxf
73.7 x 145.8 mm

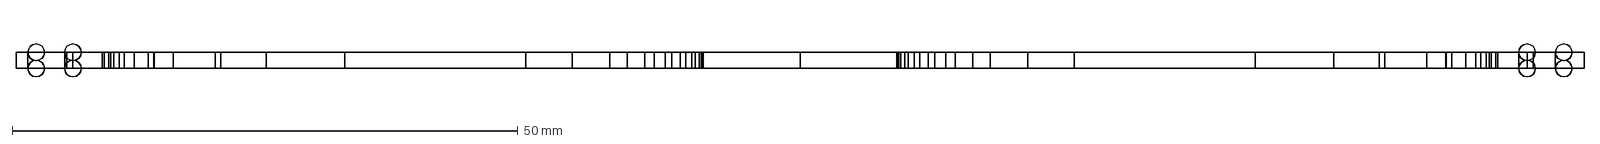
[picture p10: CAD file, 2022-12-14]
hardware/template_display_b_r1/template_display_b_r1_test_2.dxf
155.0 x 3.33 mm

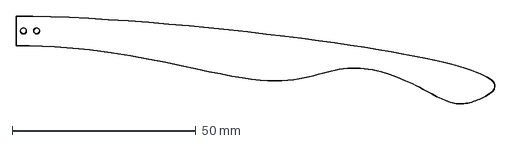
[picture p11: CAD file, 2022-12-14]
hardware/template_arm_b_r1/template_arm_b_r1_3.dxf
130.2 x 23.9 mm

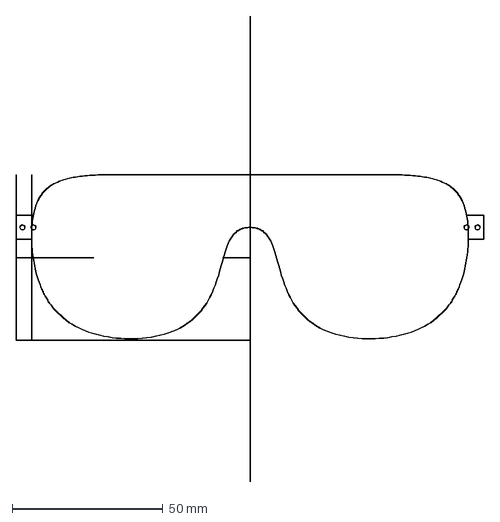
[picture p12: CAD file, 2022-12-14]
hardware/template_display_b_r1/template_display_b_r1_test_4.dxf
155.0 x 154.3 mm

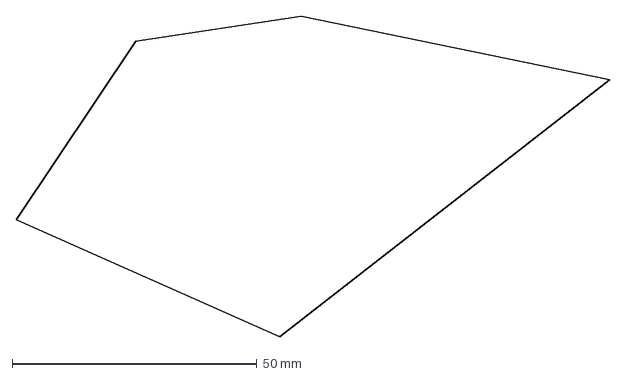
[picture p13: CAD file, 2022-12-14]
hardware/template_display_b_r1/test5.dxf
121.2 x 65.4 mm

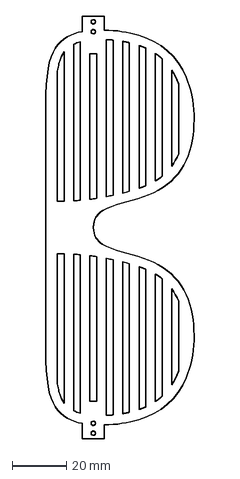
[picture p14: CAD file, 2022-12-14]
hardware/template_display_b_r1/template_display_b_r1_test_3.dxf
54.5 x 155.0 mm

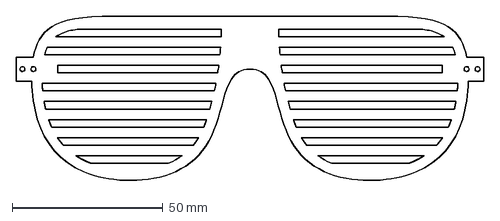
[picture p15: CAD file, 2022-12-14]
hardware/template_display_b_r1/template_display_b_r1_test_1.dxf
155.0 x 54.5 mm

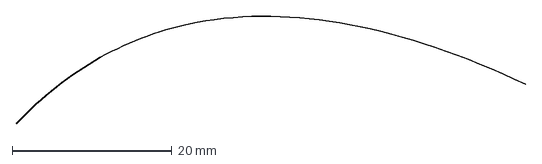
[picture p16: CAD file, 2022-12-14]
hardware/template_display_b_r1/test1.dxf
63.9 x 13.5 mm

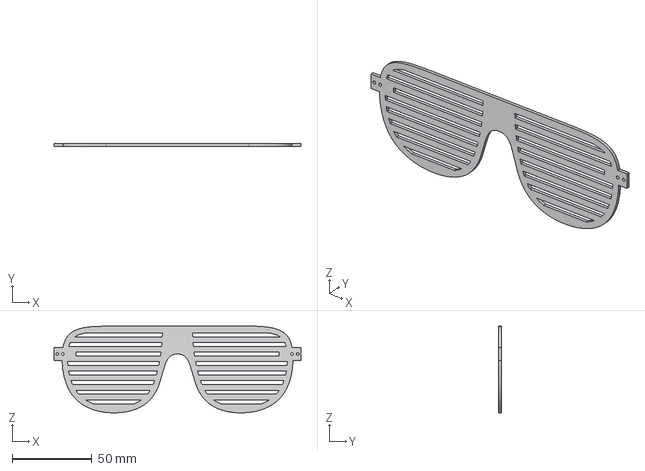
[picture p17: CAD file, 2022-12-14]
hardware/template_display_b_r1/template_display_b_r1.step
155.0 x 1.60 x 54.5 mm

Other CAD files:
hardware/template_display_b_r1/test3.dxf
hardware/template_display_b_r1/test4.dxf
hardware/template_display_b_r1/template_display_b_r1.dxf

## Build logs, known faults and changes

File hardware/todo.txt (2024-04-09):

Reading around it seems like the RP2040 could power up and start querying the external quad-spi
flash before it's had a chance to power up as well. This seems to be a problem when there is
lots of capacitance on the 3v3 net, there is roughly 4uF at the current revision (controller_b_r1).
If I notice any problems I'll look into making a circuit that'll hold the RP2040 in reset while
supply voltage is below a threshold.

put power supply switch back on power board
swap crystal for crystal oscilator !!!!
get push buttons with more travel
look into more robust cabling options
light level sensor
use thermal reliefs!!
always use a dot for pin 1!!
the usb port doesnt need the overhang
usb port could be through hole, then file down pins on far side
usb usb c!!!
relax current and thermal efficiency requirements for power board, leds are much worse!! (smaller inductor would be nice)
make front board narrower
more test points !!!
less caps on led board, maybe 1 for every 5
90 deg magnet plug for power cable?
Move all class 2 dielectric capacitors physically away from the microphone and use class 1 for
bypass on it's power/gnd line.

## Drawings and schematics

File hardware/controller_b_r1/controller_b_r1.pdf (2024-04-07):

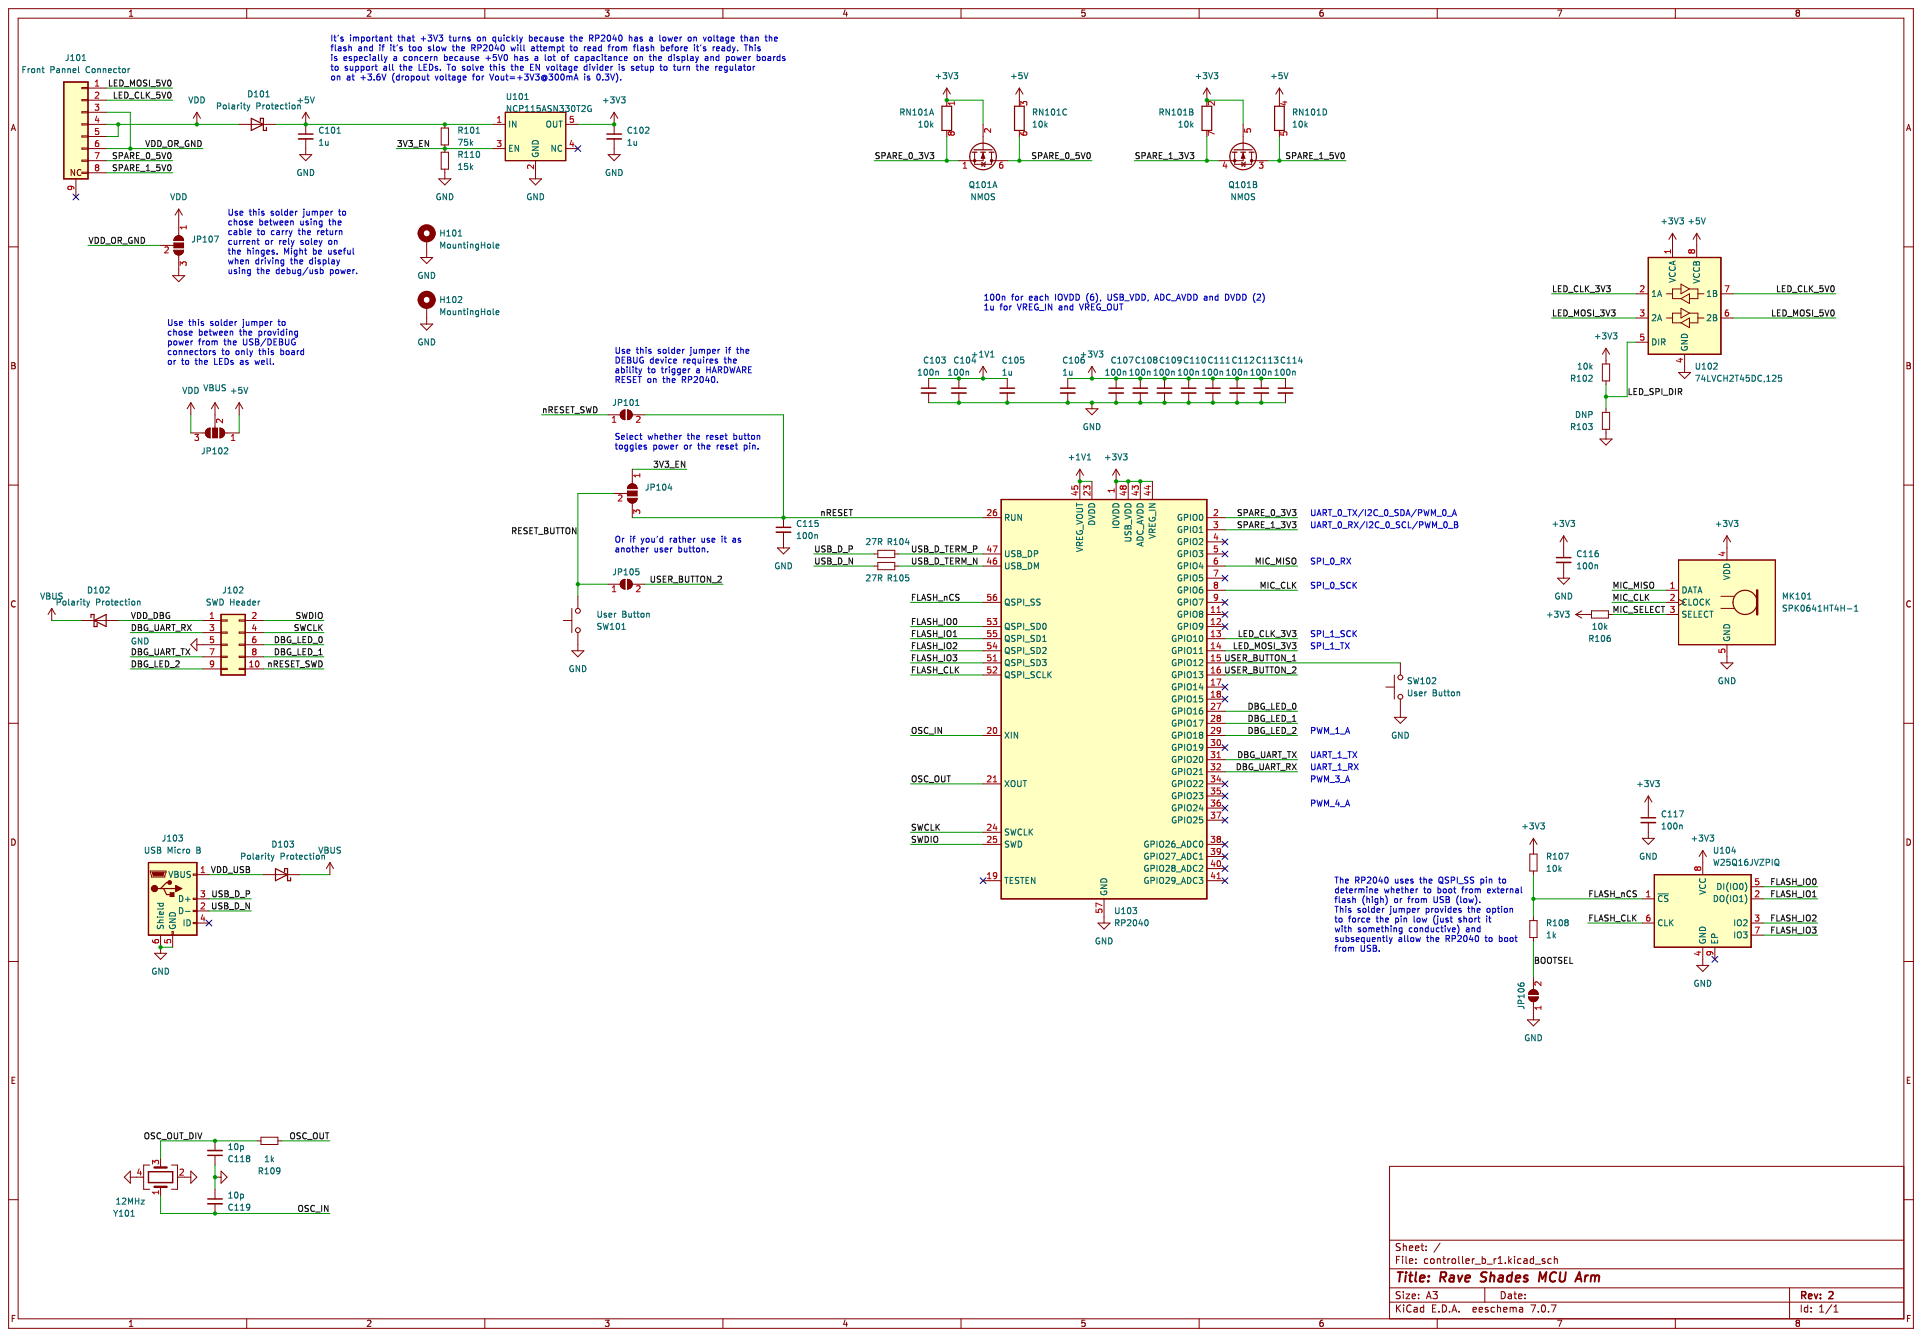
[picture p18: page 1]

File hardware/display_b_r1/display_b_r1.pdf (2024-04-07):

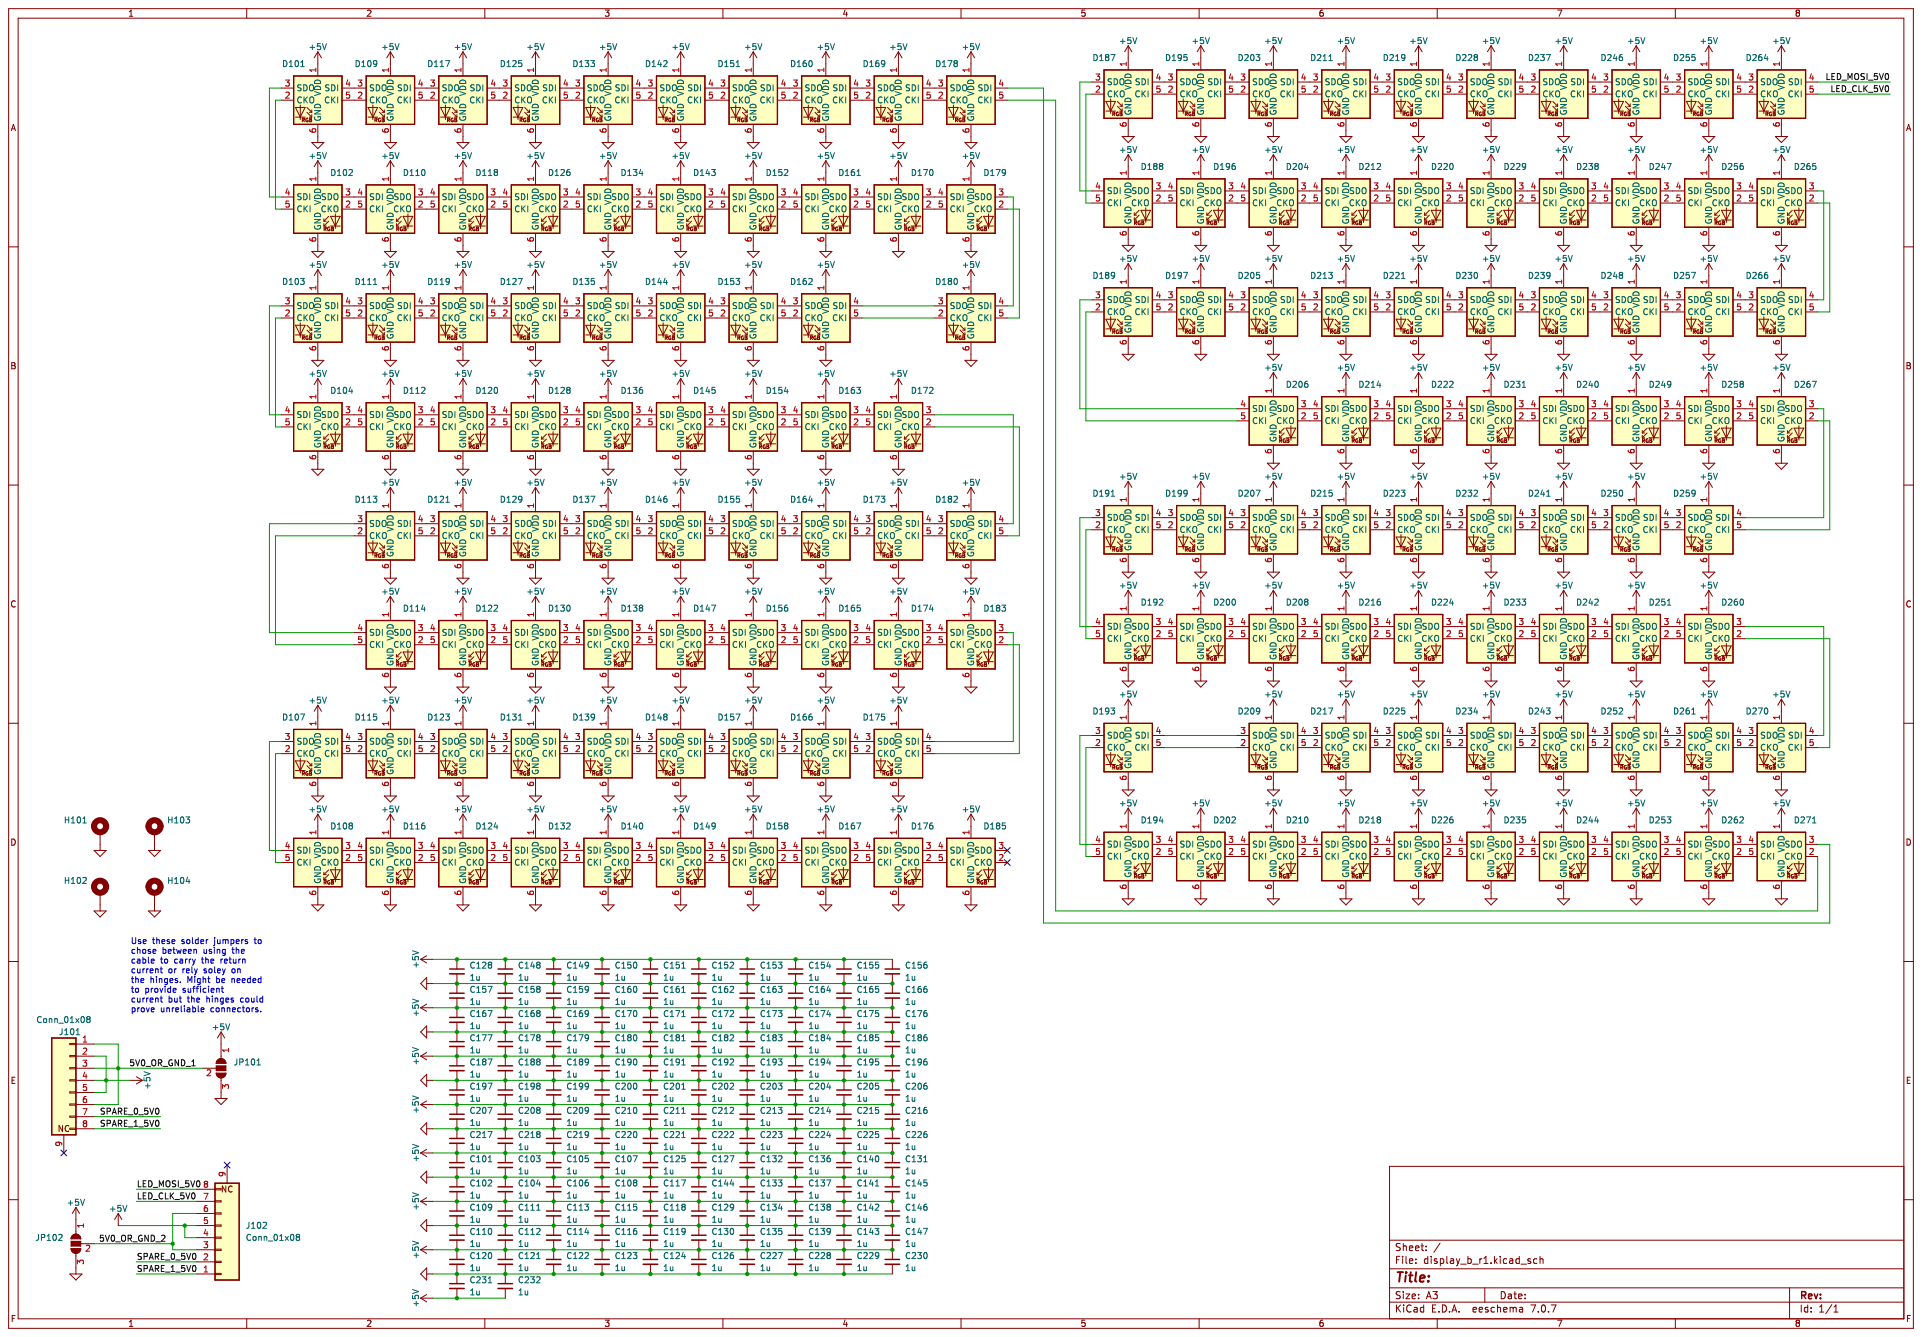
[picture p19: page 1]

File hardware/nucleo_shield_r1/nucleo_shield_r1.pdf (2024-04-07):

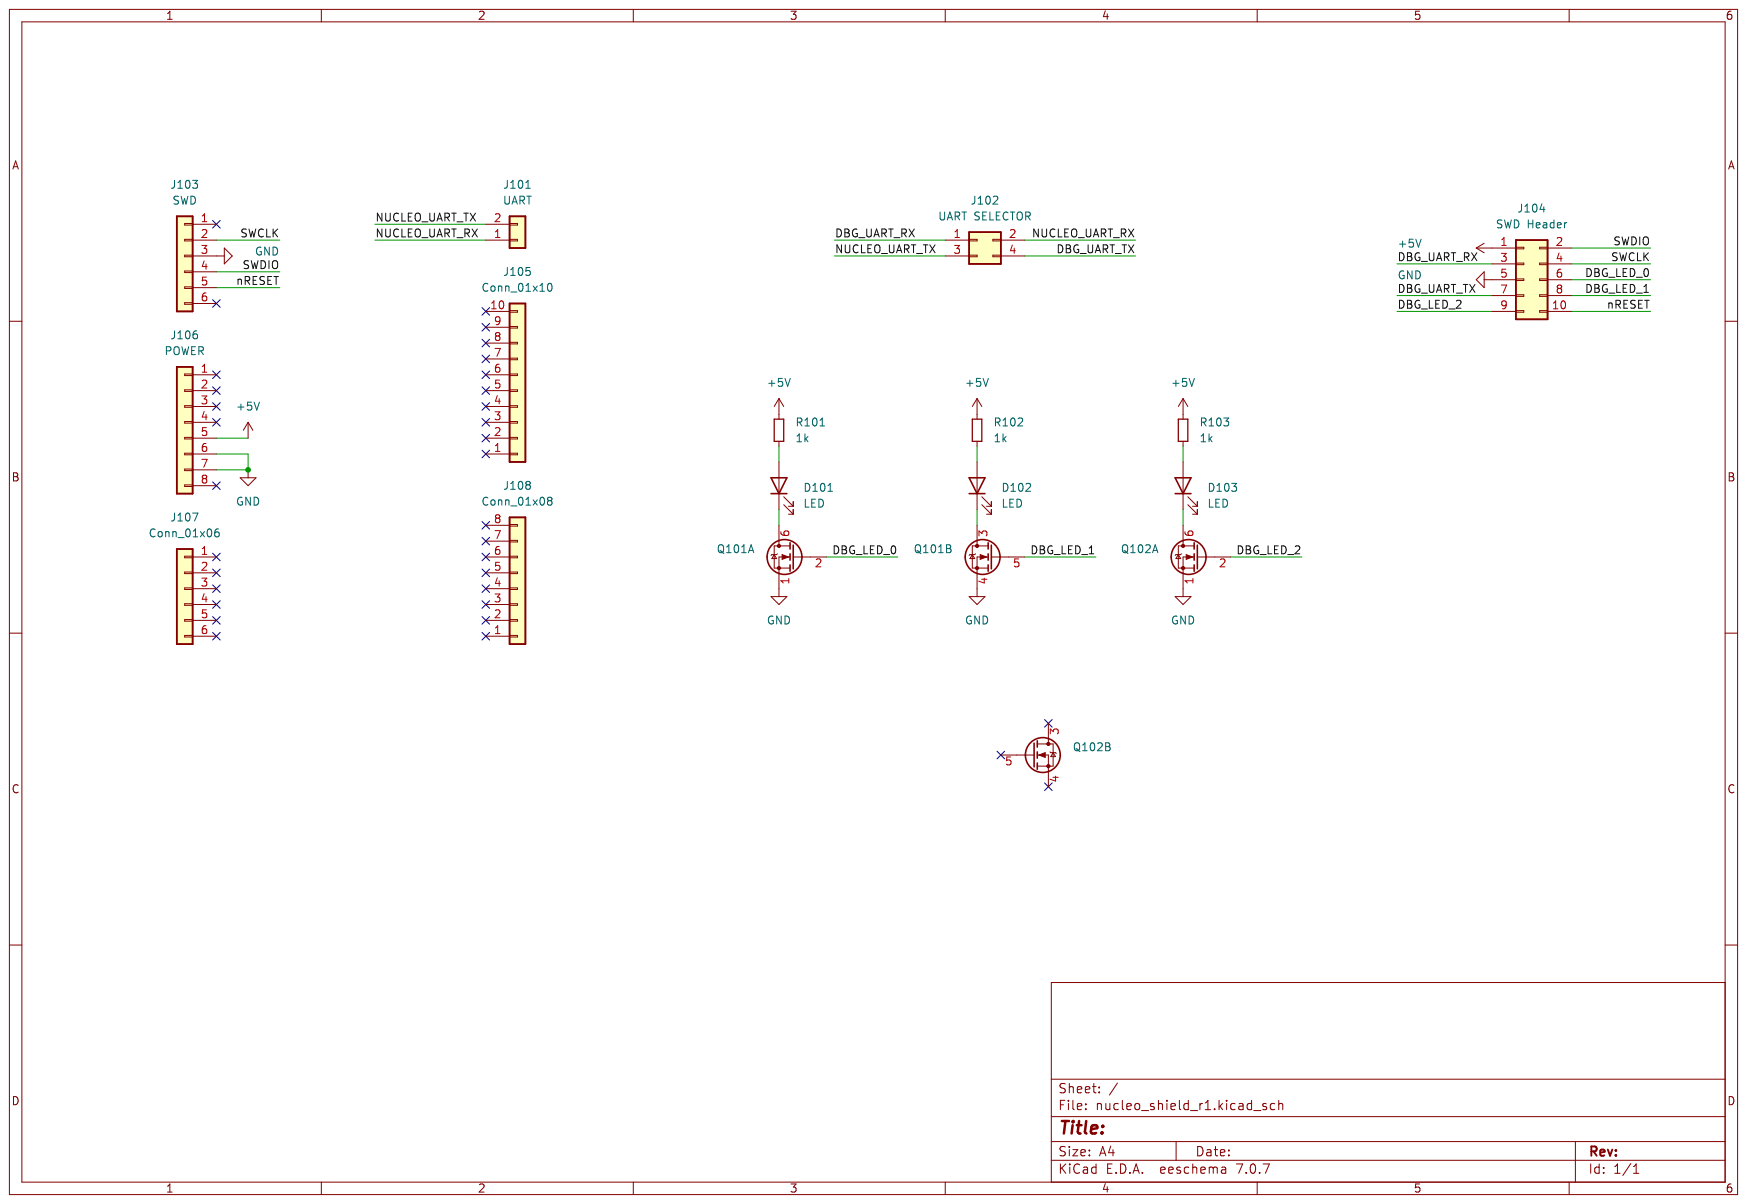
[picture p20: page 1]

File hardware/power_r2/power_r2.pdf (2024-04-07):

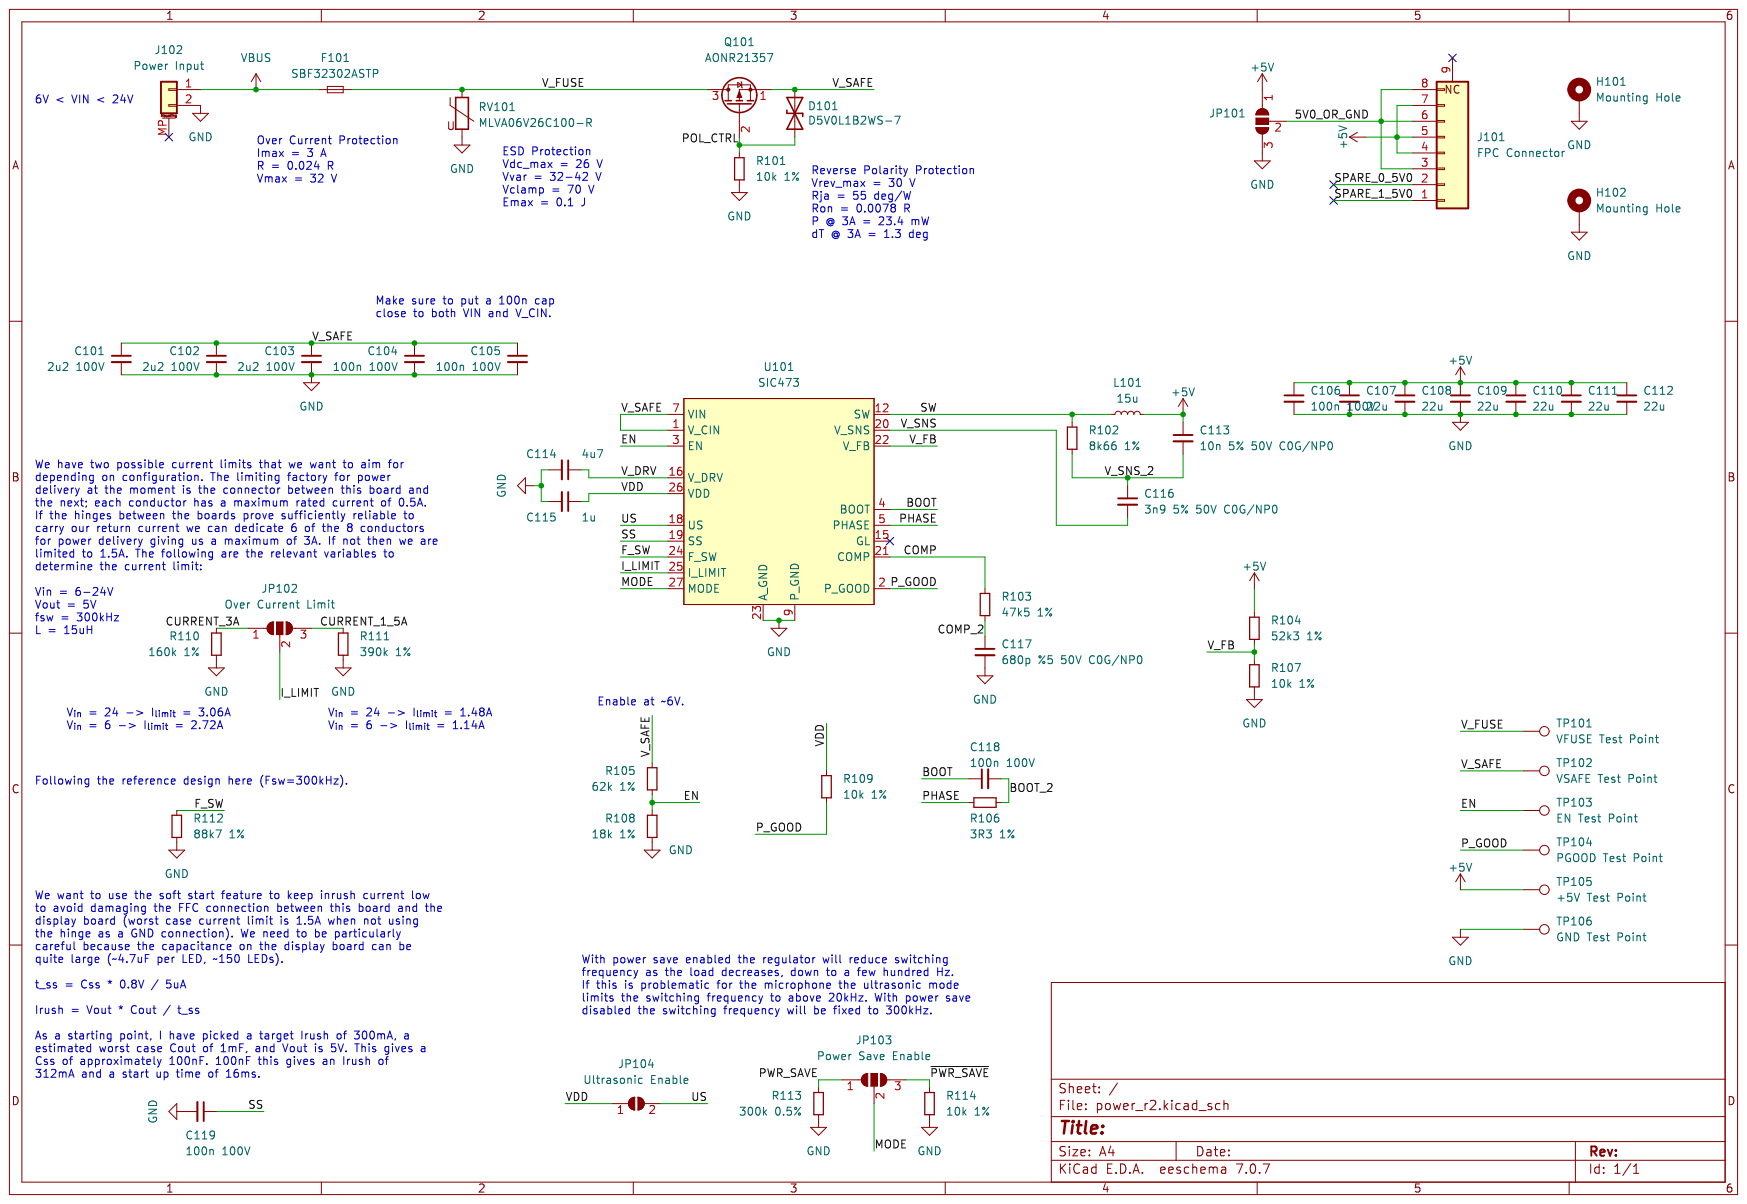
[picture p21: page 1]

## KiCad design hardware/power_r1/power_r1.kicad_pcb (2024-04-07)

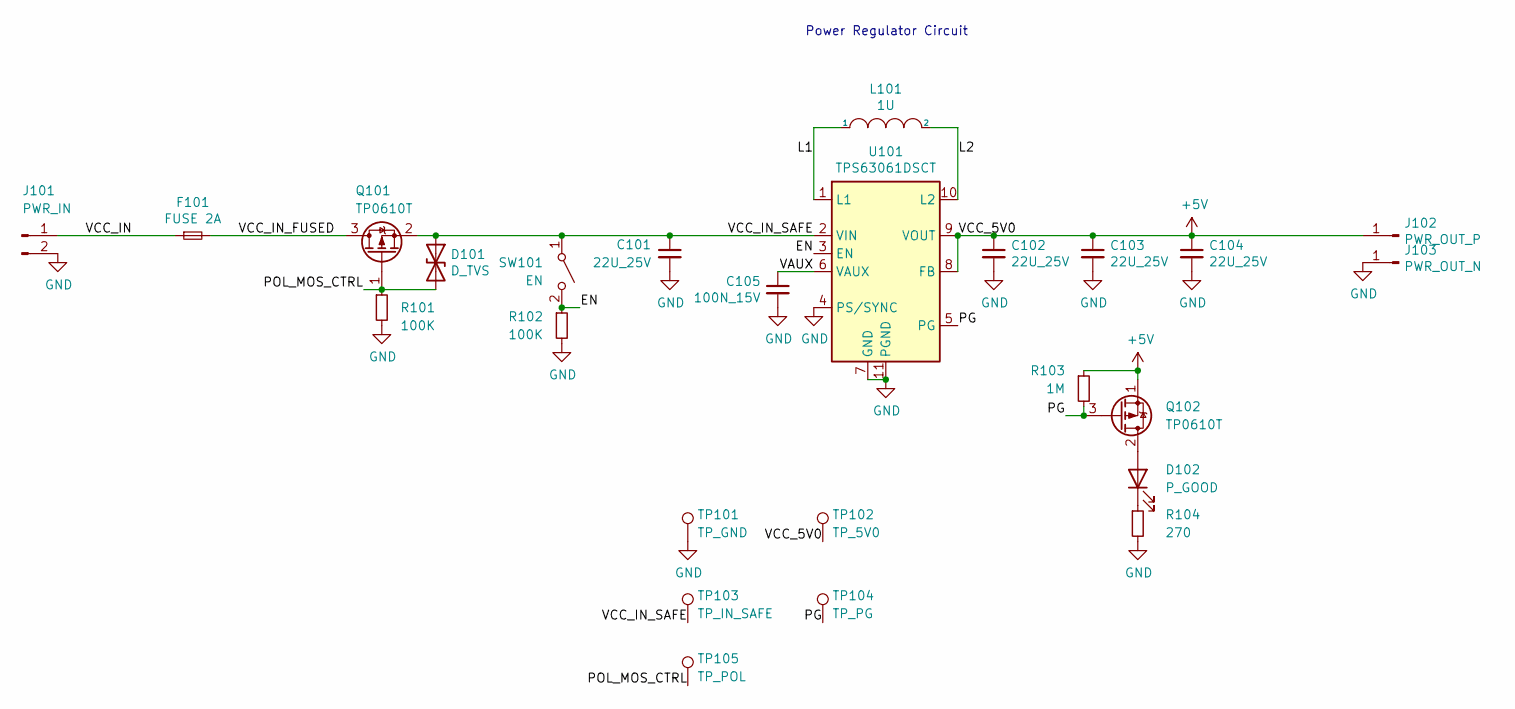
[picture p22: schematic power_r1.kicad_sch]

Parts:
C101, C102, C103, C104: 22U_25V; C_0805_2012Metric; Digi-Key Part Number 1276-CL21A226MAYNNNECT-ND
C105: 100N_15V; C_0805_2012Metric; Digi-Key Part Number 399-8000-1-ND
D101: D_TVS; D_SOD-323; Digi-Key Part Number DESD5V0U1BA-7DICT-ND
D102: P_GOOD; LED_0805_2012Metric; Digi-Key Part Number 732-4986-1-ND
F101: FUSE 2A; R_1206_3216Metric; Digi-Key Part Number 507-1881-1-ND
J101: PWR_IN; JST_PH_S2B-PH-SM4-TB_1x02-1MP_P2.00mm_Horizontal
J102: PWR_OUT_P; PinHeader_1x01_P1.00mm_Vertical_SMD_CUSTOM
J103: PWR_OUT_N; PinHeader_1x01_P1.00mm_Vertical_SMD_CUSTOM
L101: 1U; L_Taiyo-Yuden_NR-50xx_HandSoldering; Digi-Key Part Number 587-2403-1-ND
Q101, Q102: TP0610T; SOT-23; Digi-Key Part Number SI2315BDS-T1-GE3CT-ND
R101, R102: 100K; R_0805_2012Metric; Digi-Key Part Number RR12P100KDCT-ND
R103: 1M; R_0805_2012Metric; Digi-Key Part Number P123796CT-ND
R104: 270; R_0805_2012Metric; Digi-Key Part Number RR12P270DCT-ND
SW101: EN; Switch_Slide_JS202011SCQN; Digi-Key Part Number 401-2002-1-ND
TP101: TP_GND; TestPoint_Pad_D1.0mm
TP102: TP_5V0; TestPoint_Pad_D1.0mm
TP103: TP_IN_SAFE; TestPoint_Pad_D1.0mm
TP104: TP_PG; TestPoint_Pad_D1.0mm
TP105: TP_POL; TestPoint_Pad_D1.0mm
U101: TPS63061DSCT; Texas_S-PWSON-N10; Digi-Key Part Number 296-30179-1-ND

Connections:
+5V: C102.1, C103.1, C104.1, J102.1, Q102.1 (S), R103.1, TP102.1, U101.8 (FB), U101.9 (VOUT)
/EN: R102.1, SW101.2 (B), U101.3 (EN)
/L1: L101.1, U101.1 (L1)
/L2: L101.2, U101.10 (L2)
/PG: Q102.3 (G), R103.2, TP104.1, U101.5 (PG)
/POL_MOS_CTRL: D101.2 (A2), Q101.1 (G), R101.1, TP105.1
/VAUX: C105.1, U101.6 (VAUX)
/VCC_IN: F101.1, J101.1
/VCC_IN_FUSED: F101.2, Q101.3 (D)
/VCC_IN_SAFE: C101.1, D101.1 (A1), Q101.2 (S), SW101.1 (A), TP103.1, U101.2 (VIN)
GND: C101.2, C102.2, C103.2, C104.2, C105.2, J101.2, J103.1, R101.2, R102.2, R104.2, TP101.1, U101.4 (PS/SYNC), U101.7 (GND), U101.11 (PGND)
unnamed: D102.1 (K), R104.1
unnamed: D102.2 (A), Q102.2 (D)

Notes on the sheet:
Power Regulator Circuit

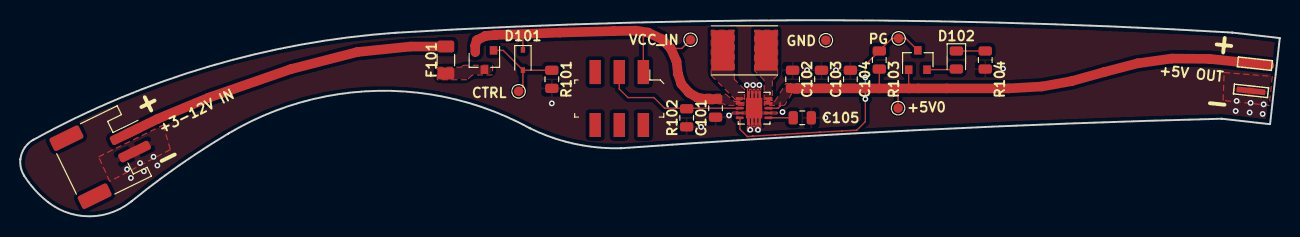
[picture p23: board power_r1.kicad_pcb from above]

Board: 2 copper layers, 130.8 x 20.4 mm, 25 parts (0 on the bottom side), 13 nets.

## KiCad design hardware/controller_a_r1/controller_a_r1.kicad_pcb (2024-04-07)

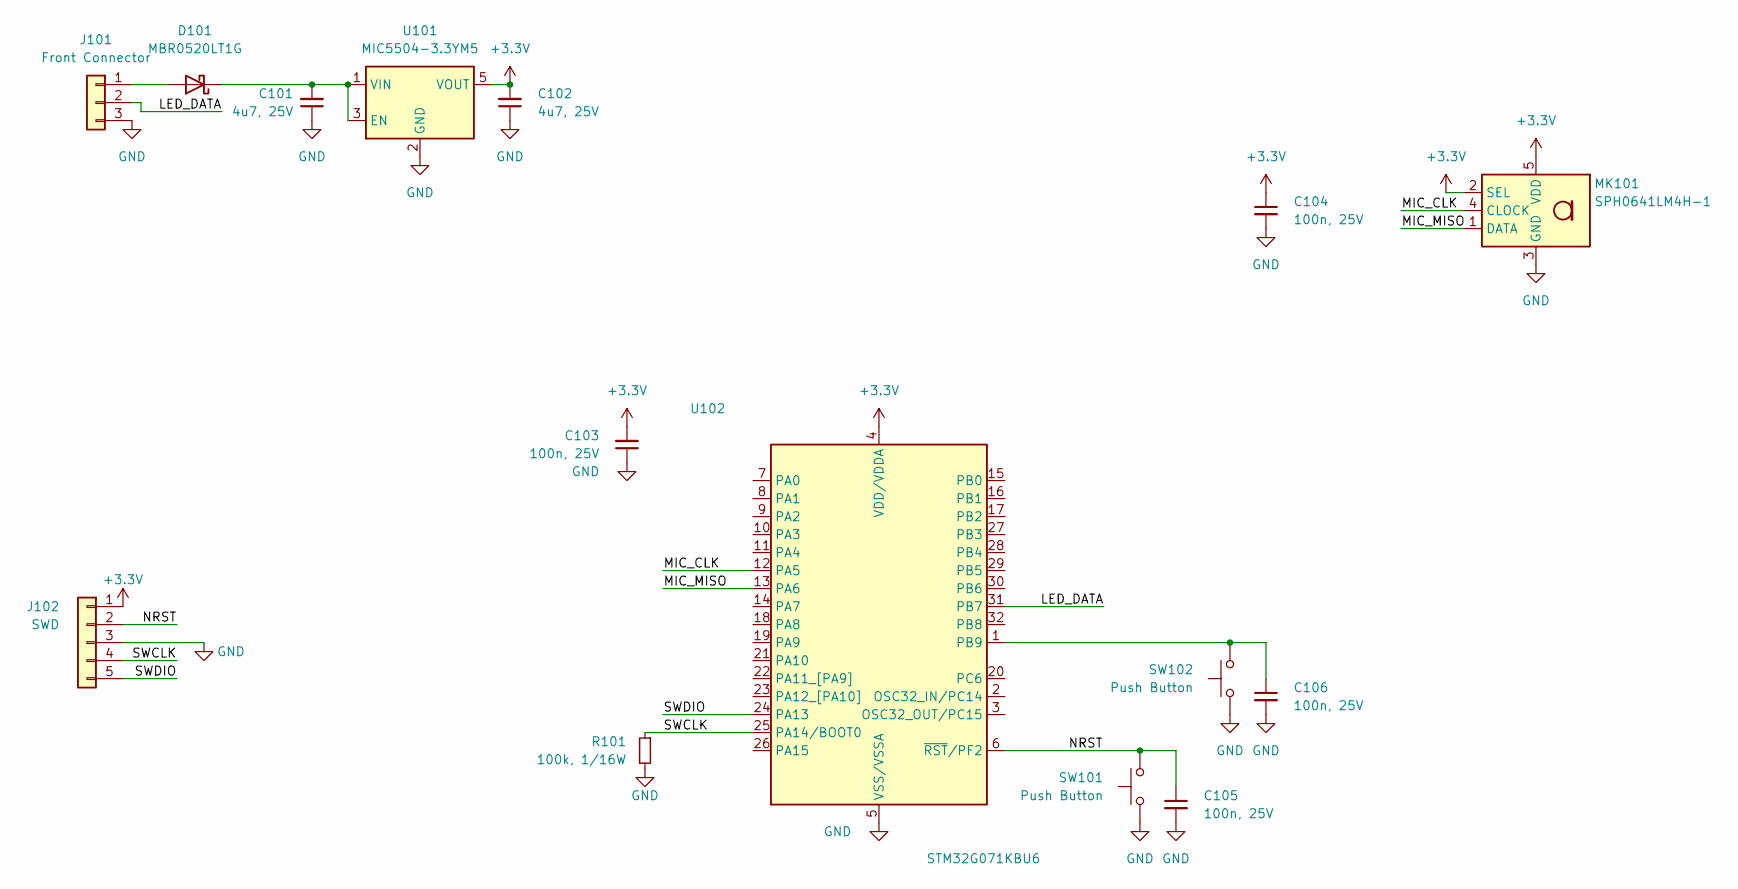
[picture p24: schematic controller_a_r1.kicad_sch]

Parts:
C101, C102: 4u7, 25V; C_0805_2012Metric_Pad1.18x1.45mm_HandSolder; Digi-Key Part Number 732-7628-1-ND
C103, C104, C105, C106: 100n, 25V; C_0805_2012Metric_Pad1.18x1.45mm_HandSolder; Digi-Key Part Number 1276-2450-1-ND
D101: MBR0520LT1G; D_SOD-123; Digi-Key Part Number MBR0520LT1GOSCT-ND
J101: Front Connector; PinHeader_1x03_P1.00mm_Vertical_SMD_Pin1Left_CUSTOM
J102: SWD; PinHeader_1x05_P1.00mm_Vertical_SMD_Pin1Left_CUSTOM; Digi-Key Part Number N/A
MK101: SPH0641LM4H-1; MIC_SPH0641LM4H-1; Digi-Key Part Number 423-1395-1-ND
R101: 100k, 1/16W; R_0805_2012Metric_Pad1.20x1.40mm_HandSolder; Digi-Key Part Number RMCF0805FT100KCT-ND
SW101, SW102: Push Button; SW_SPST_CK_KXT3; Digi-Key Part Number CKN10779CT-ND
U101: MIC5504-3.3YM5; SOT-23-5_HandSoldering; Digi-Key Part Number 576-4764-1-ND
U102: STM32G071KBU6; QFN50P500X500X60-33N-D; Digi-Key Part Number 497-18357-ND

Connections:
+3.3V: C102.2, C103.2, C104.1, J102.1, MK101.2 (SEL), MK101.5 (VDD), U101.5 (VOUT), U102.4 (VDD/VDDA)
/LED_DATA: J101.2, U102.31 (PB7)
/MIC_CLK: MK101.4 (CLOCK), U102.12 (PA5)
/MIC_MISO: MK101.1 (DATA), U102.13 (PA6)
/NRST: C105.1, J102.2, SW101.2, U102.6 (~RST/PF2)
/SWCLK: J102.4, R101.1, U102.25 (PA14/BOOT0)
/SWDIO: J102.5, U102.24 (PA13)
GND: C101.1, C102.1, C103.1, C104.2, C105.2, C106.2, J101.3, J102.3, MK101.3 (GND), R101.2, SW101.1, SW102.1, U101.2 (GND), U102.5 (VSS/VSSA), U102.33 (VSS/VSSA)
unnamed: C101.2, D101.1 (K), U101.1 (VIN), U101.3 (EN)
unnamed: C106.1, SW102.2, U102.1 (PB9)
unnamed: D101.2 (A), J101.1

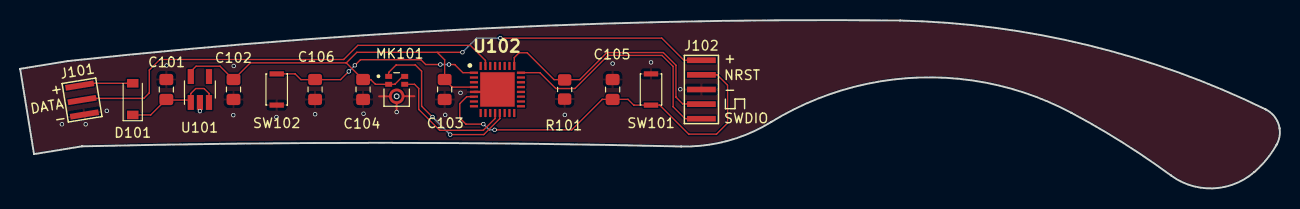
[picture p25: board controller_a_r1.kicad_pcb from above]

Board: 2 copper layers, 131.2 x 17.5 mm, 15 parts (0 on the bottom side), 11 nets.

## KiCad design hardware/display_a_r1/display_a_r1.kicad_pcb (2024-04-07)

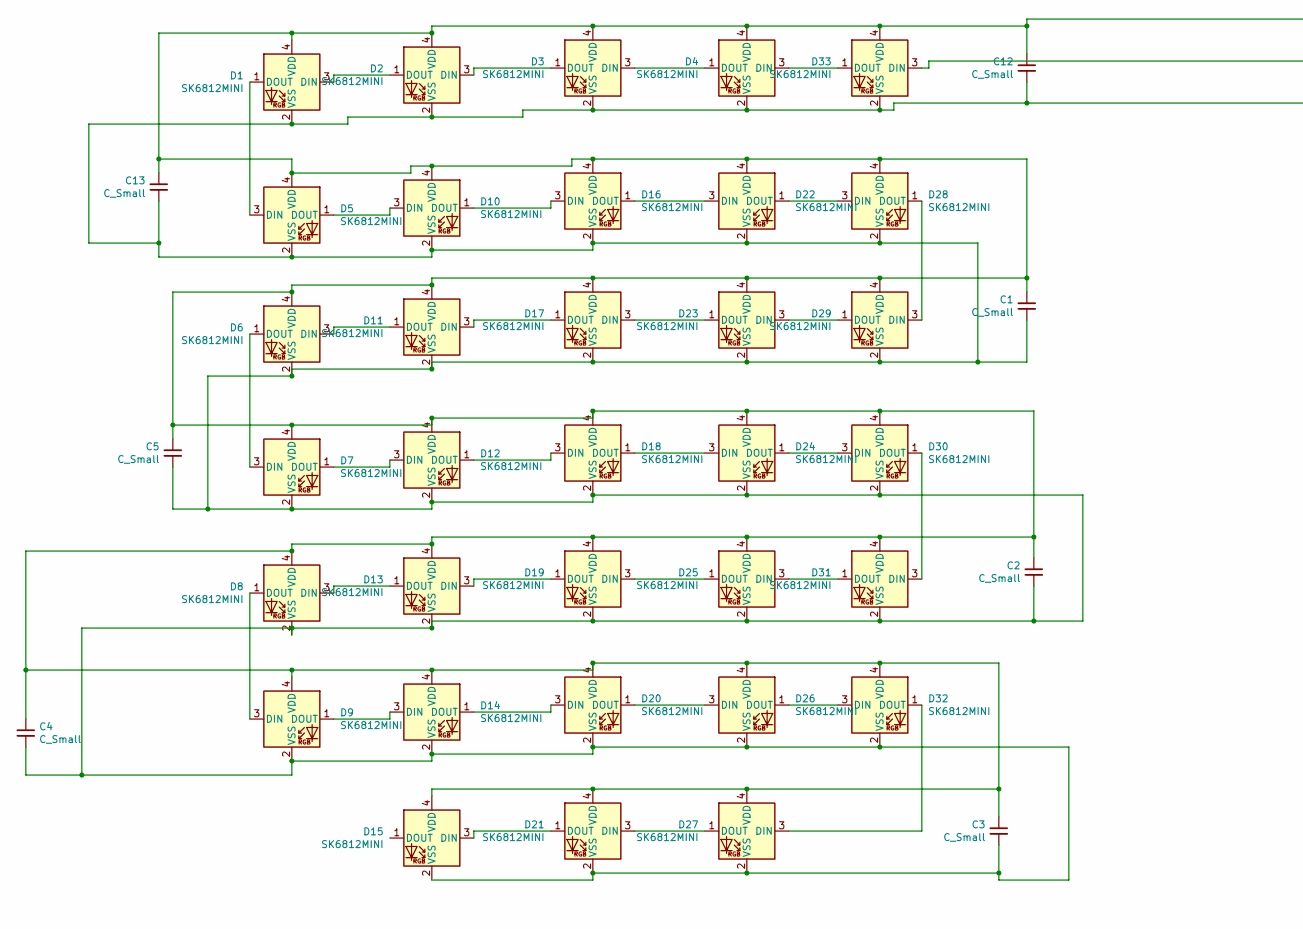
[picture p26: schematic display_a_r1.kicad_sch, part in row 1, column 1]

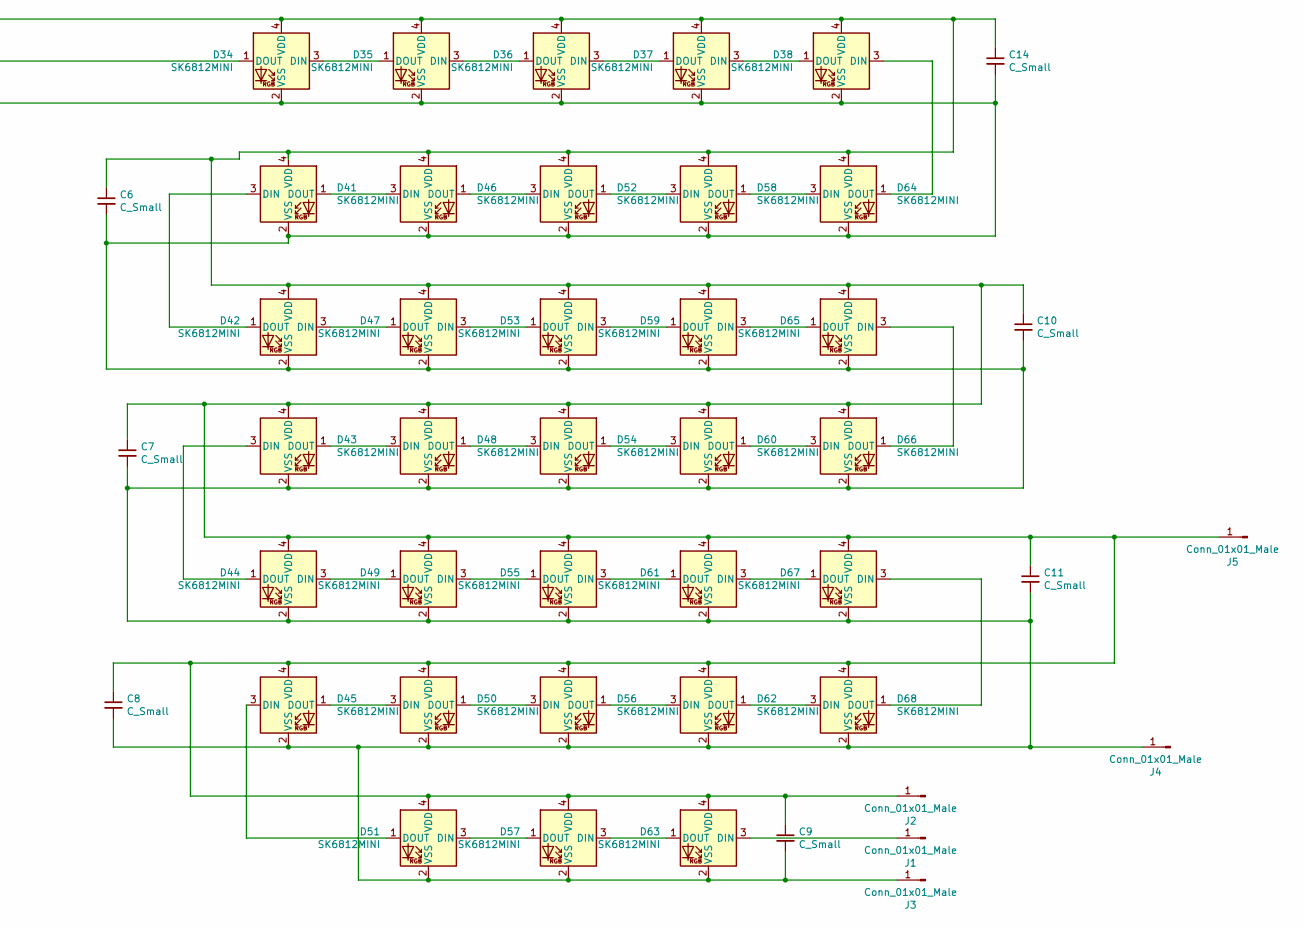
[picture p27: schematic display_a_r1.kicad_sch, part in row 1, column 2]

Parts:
C1, C2, C3, C4, C5, C6, C7, C8, C9, C10, C11, C12, C13, C14: C_Small; C_0603_1608Metric_Pad1.08x0.95mm_HandSolder
D1, D2, D3, D4, D5, D6, D7, D8, D9, D10, D11, D12, D13, D14, D15, D16, D17, D18, D19, D20, D21, D22, D23, D24, D25, D26, D27, D28, D29, D30, D31, D32, D33, D34, D35, D36, D37, D38, D41, D42, D43, D44, D45, D46, D47, D48, D49, D50, D51, D52, D53, D54, D55, D56, D57, D58, D59, D60, D61, D62, D63, D64, D65, D66, D67, D68: SK6812MINI; LED_SK6812MINI_PLCC4_3.5x3.5mm_P1.75mm
J1, J2, J3, J4, J5: Conn_01x01_Male; PinHeader_1x01_SMD

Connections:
unnamed: C1.1, C2.1, C3.1, C4.1, C5.1, C6.1, C7.1, C8.1, C9.1, C10.1, C11.1, C12.1, C13.1, C14.1, D1.4 (VDD), D2.4 (VDD), D3.4 (VDD), D4.4 (VDD), D5.4 (VDD), D6.4 (VDD), D7.4 (VDD), D8.4 (VDD), D9.4 (VDD), D10.4 (VDD), D11.4 (VDD), D12.4 (VDD), D13.4 (VDD), D14.4 (VDD), D15.4 (VDD), D16.4 (VDD), D17.4 (VDD), D18.4 (VDD), D19.4 (VDD), D20.4 (VDD), D21.4 (VDD), D22.4 (VDD), D23.4 (VDD), D24.4 (VDD), D25.4 (VDD), D26.4 (VDD), D27.4 (VDD), D28.4 (VDD), D29.4 (VDD), D30.4 (VDD), D31.4 (VDD), D32.4 (VDD), D33.4 (VDD), D34.4 (VDD), D35.4 (VDD), D36.4 (VDD), D37.4 (VDD), D38.4 (VDD), D41.4 (VDD), D42.4 (VDD), D43.4 (VDD), D44.4 (VDD), D45.4 (VDD), D46.4 (VDD), D47.4 (VDD), D48.4 (VDD), D49.4 (VDD), D50.4 (VDD), D51.4 (VDD), D52.4 (VDD), D53.4 (VDD), D54.4 (VDD), D55.4 (VDD), D56.4 (VDD), D57.4 (VDD), D58.4 (VDD), D59.4 (VDD), D60.4 (VDD), D61.4 (VDD), D62.4 (VDD), D63.4 (VDD), D64.4 (VDD), D65.4 (VDD), D66.4 (VDD), D67.4 (VDD), D68.4 (VDD), J2.1, J5.1
unnamed: C1.2, C2.2, C3.2, C4.2, C5.2, C6.2, C7.2, C8.2, C9.2, C10.2, C11.2, C12.2, C13.2, C14.2, D1.2 (VSS), D2.2 (VSS), D3.2 (VSS), D4.2 (VSS), D5.2 (VSS), D6.2 (VSS), D7.2 (VSS), D8.2 (VSS), D9.2 (VSS), D10.2 (VSS), D11.2 (VSS), D12.2 (VSS), D13.2 (VSS), D14.2 (VSS), D15.2 (VSS), D16.2 (VSS), D17.2 (VSS), D18.2 (VSS), D19.2 (VSS), D20.2 (VSS), D21.2 (VSS), D22.2 (VSS), D23.2 (VSS), D24.2 (VSS), D25.2 (VSS), D26.2 (VSS), D27.2 (VSS), D28.2 (VSS), D29.2 (VSS), D30.2 (VSS), D31.2 (VSS), D32.2 (VSS), D33.2 (VSS), D34.2 (VSS), D35.2 (VSS), D36.2 (VSS), D37.2 (VSS), D38.2 (VSS), D41.2 (VSS), D42.2 (VSS), D43.2 (VSS), D44.2 (VSS), D45.2 (VSS), D46.2 (VSS), D47.2 (VSS), D48.2 (VSS), D49.2 (VSS), D50.2 (VSS), D51.2 (VSS), D52.2 (VSS), D53.2 (VSS), D54.2 (VSS), D55.2 (VSS), D56.2 (VSS), D57.2 (VSS), D58.2 (VSS), D59.2 (VSS), D60.2 (VSS), D61.2 (VSS), D62.2 (VSS), D63.2 (VSS), D64.2 (VSS), D65.2 (VSS), D66.2 (VSS), D67.2 (VSS), D68.2 (VSS), J3.1, J4.1
unnamed: D1.1 (DOUT), D5.3 (DIN)
unnamed: D1.3 (DIN), D2.1 (DOUT)
unnamed: D2.3 (DIN), D3.1 (DOUT)
unnamed: D3.3 (DIN), D4.1 (DOUT)
unnamed: D6.1 (DOUT), D7.3 (DIN)
unnamed: D8.1 (DOUT), D9.3 (DIN)
unnamed: D10.1 (DOUT), D16.3 (DIN)
unnamed: D5.1 (DOUT), D10.3 (DIN)
unnamed: D6.3 (DIN), D11.1 (DOUT)
unnamed: D11.3 (DIN), D17.1 (DOUT)
unnamed: D12.1 (DOUT), D18.3 (DIN)
unnamed: D7.1 (DOUT), D12.3 (DIN)
unnamed: D8.3 (DIN), D13.1 (DOUT)
unnamed: D13.3 (DIN), D19.1 (DOUT)
unnamed: D14.1 (DOUT), D20.3 (DIN)
unnamed: D9.1 (DOUT), D14.3 (DIN)
unnamed: D15.3 (DIN), D21.1 (DOUT)
unnamed: D16.1 (DOUT), D22.3 (DIN)
unnamed: D17.3 (DIN), D23.1 (DOUT)
unnamed: D18.1 (DOUT), D24.3 (DIN)
unnamed: D19.3 (DIN), D25.1 (DOUT)
unnamed: D20.1 (DOUT), D26.3 (DIN)
unnamed: D21.3 (DIN), D27.1 (DOUT)
unnamed: D22.1 (DOUT), D28.3 (DIN)
unnamed: D23.3 (DIN), D29.1 (DOUT)
unnamed: D24.1 (DOUT), D30.3 (DIN)
unnamed: D25.3 (DIN), D31.1 (DOUT)
unnamed: D26.1 (DOUT), D32.3 (DIN)
unnamed: D27.3 (DIN), D32.1 (DOUT)
unnamed: D28.1 (DOUT), D29.3 (DIN)
unnamed: D30.1 (DOUT), D31.3 (DIN)
unnamed: D4.3 (DIN), D33.1 (DOUT)
unnamed: D33.3 (DIN), D34.1 (DOUT)
unnamed: D34.3 (DIN), D35.1 (DOUT)
unnamed: D35.3 (DIN), D36.1 (DOUT)
unnamed: D36.3 (DIN), D37.1 (DOUT)
unnamed: D37.3 (DIN), D38.1 (DOUT)
unnamed: D38.3 (DIN), D64.1 (DOUT)
unnamed: D41.1 (DOUT), D46.3 (DIN)
unnamed: D41.3 (DIN), D42.1 (DOUT)
unnamed: D42.3 (DIN), D47.1 (DOUT)
unnamed: D43.1 (DOUT), D48.3 (DIN)
unnamed: D43.3 (DIN), D44.1 (DOUT)
unnamed: D44.3 (DIN), D49.1 (DOUT)
unnamed: D45.1 (DOUT), D50.3 (DIN)
unnamed: D45.3 (DIN), D51.1 (DOUT)
unnamed: D46.1 (DOUT), D52.3 (DIN)
unnamed: D47.3 (DIN), D53.1 (DOUT)
unnamed: D48.1 (DOUT), D54.3 (DIN)
unnamed: D49.3 (DIN), D55.1 (DOUT)
unnamed: D50.1 (DOUT), D56.3 (DIN)
unnamed: D51.3 (DIN), D57.1 (DOUT)
unnamed: D52.1 (DOUT), D58.3 (DIN)
unnamed: D53.3 (DIN), D59.1 (DOUT)
unnamed: D54.1 (DOUT), D60.3 (DIN)
unnamed: D55.3 (DIN), D61.1 (DOUT)
unnamed: D56.1 (DOUT), D62.3 (DIN)
unnamed: D57.3 (DIN), D63.1 (DOUT)
unnamed: D58.1 (DOUT), D64.3 (DIN)
unnamed: D59.3 (DIN), D65.1 (DOUT)
unnamed: D60.1 (DOUT), D66.3 (DIN)
unnamed: D61.3 (DIN), D67.1 (DOUT)
unnamed: D62.1 (DOUT), D68.3 (DIN)
unnamed: D63.3 (DIN), J1.1
unnamed: D65.3 (DIN), D66.1 (DOUT)
unnamed: D67.3 (DIN), D68.1 (DOUT)

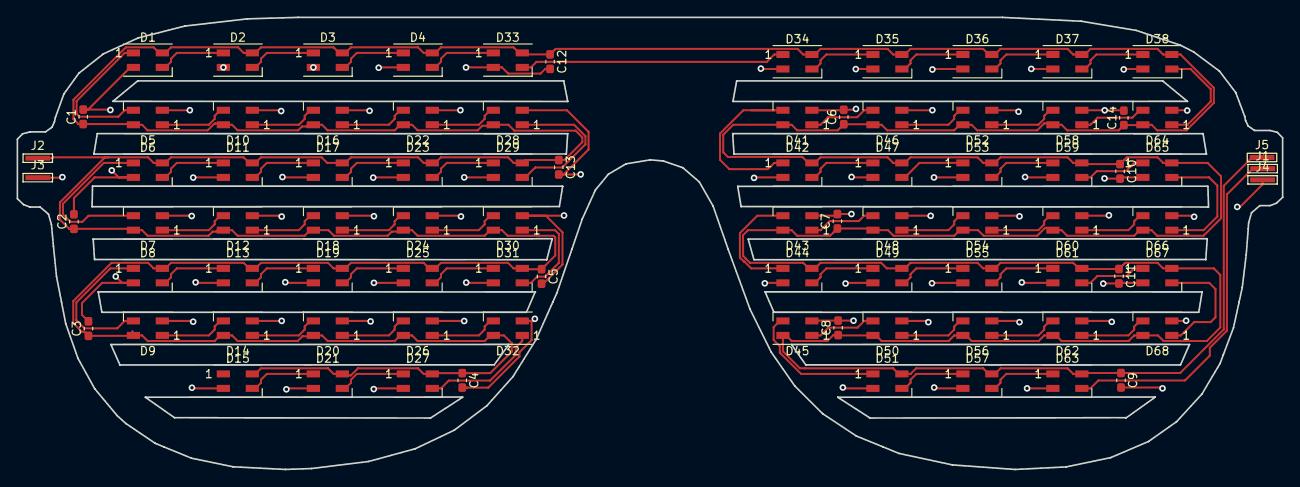
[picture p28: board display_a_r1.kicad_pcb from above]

Board: 2 copper layers, 152.9 x 54.6 mm, 85 parts (0 on the bottom side), 68 nets.

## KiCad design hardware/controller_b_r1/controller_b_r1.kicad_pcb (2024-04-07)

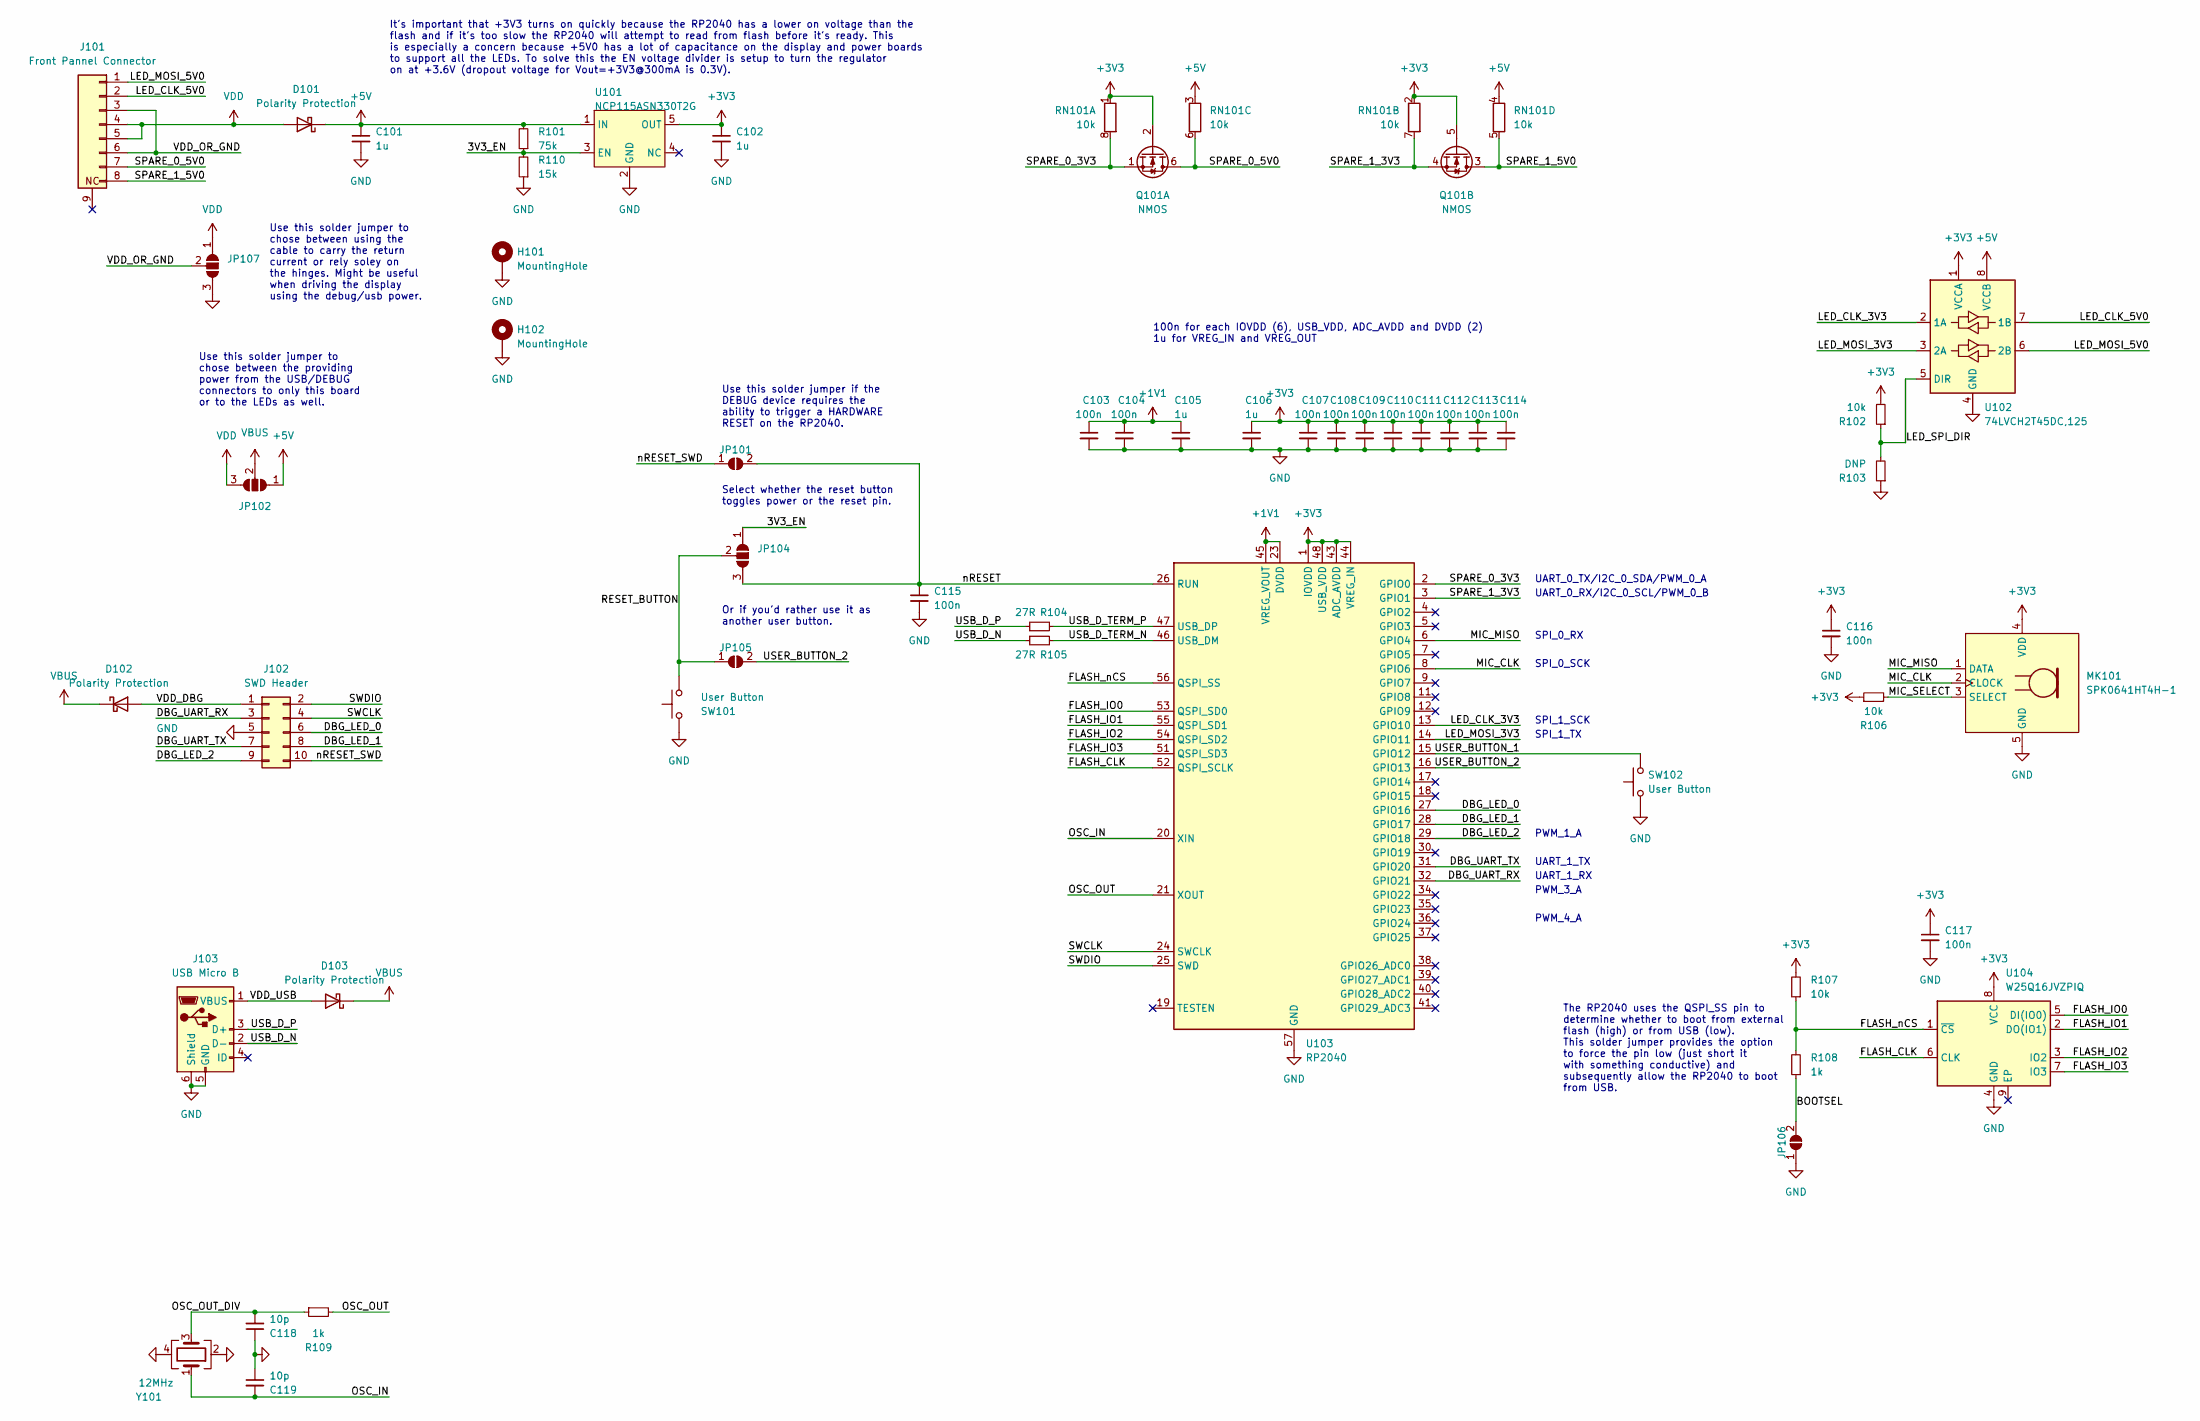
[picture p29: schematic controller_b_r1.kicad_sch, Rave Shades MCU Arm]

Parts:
C101, C102, C105, C106: 1u; C_0402_1005Metric
C103, C104, C107, C108, C109, C110, C111, C112, C113, C114, C115, C116, C117: 100n; C_0402_1005Metric
C118, C119: 10p; C_0402_1005Metric
D101, D102, D103: Polarity Protection; D_0402_1005Metric
H101, H102: MountingHole; M1.4 Mounting Hole
J101: Front Pannel Connector; CF35082D0RE-NH
J102: SWD Header; PinHeader_2x05_P1.27mm_Vertical_SMD
J103: USB Micro B; USB_Micro-B_Amphenol_10118192_Horizontal
JP101, JP105, JP106: SolderJumper_2_Open; SolderJumper-2_P1.3mm_Open_TrianglePad1.0x1.5mm
JP102, JP104, JP107: SolderJumper_3_Open; SolderJumper-3_P1.3mm_Open_Pad1.0x1.5mm
MK101: SPK0641HT4H-1
Q101: NMOS; SOT-363_SC-70-6
R101: 75k; R_0402_1005Metric
R102, R106, R107: 10k; R_0402_1005Metric
R103: DNP; R_0402_1005Metric
R104, R105: 27R; R_0402_1005Metric
R108, R109: 1k; R_0402_1005Metric
R110: 15k; R_0402_1005Metric
RN101: 10k; R_Array_Convex_4x0402
SW101, SW102: User Button; SW_SPST_EVQP7A
U101: NCP115ASN330T2G; TSOT-23-5
U102: 74LVCH2T45DC,125; VSSOP-8_2.3x2mm_P0.5mm
U103: RP2040; QFN-56-1EP_7x7mm_P0.4mm_EP3.2x3.2mm
U104: W25Q16JVZPIQ; WSON-8-1EP_6x5mm_P1.27mm_EP3.4x4.3mm
Y101: 12MHz; ECS-120-10-36B2-CWY-TR

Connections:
+1V1: C103.1, C104.1, C105.1, U103.23 (DVDD), U103.45 (VREG_VOUT), U103.50 (DVDD)
+3V3: C102.1, C106.1, C107.1, C108.1, C109.1, C110.1, C111.1, C112.1, C113.1, C114.1, C116.1, C117.1, MK101.4 (VDD), Q101.2 (G), Q101.5 (G), R102.2, R106.1, R107.2, RN101.1 (R1.1), RN101.2 (R2.1), U101.5 (OUT), U102.1 (VCCA), U103.1 (IOVDD), U103.10 (IOVDD), U103.22 (IOVDD), U103.33 (IOVDD), U103.42 (IOVDD), U103.43 (ADC_AVDD), U103.44 (VREG_IN), U103.48 (USB_VDD), U103.49 (IOVDD), U104.8 (VCC)
+5V: C101.1, D101.1 (K), JP102.1 (A), R101.2, RN101.3 (R3.1), RN101.4 (R4.1), U101.1 (IN), U102.8 (VCCB)
/3V3_EN: JP104.1 (A), R101.1, R110.2, U101.3 (EN)
/BOOTSEL: JP106.2 (B), R108.1
/DBG_LED_0: J102.6, U103.27 (GPIO16)
/DBG_LED_1: J102.8, U103.28 (GPIO17)
/DBG_LED_2: J102.9, U103.29 (GPIO18)
/DBG_UART_RX: J102.3, U103.32 (GPIO21)
/DBG_UART_TX: J102.7, U103.31 (GPIO20)
/FLASH_CLK: U103.52 (QSPI_SCLK), U104.6 (CLK)
/FLASH_IO0: U103.53 (QSPI_SD0), U104.5 (DI(IO0))
/FLASH_IO1: U103.55 (QSPI_SD1), U104.2 (DO(IO1))
/FLASH_IO2: U103.54 (QSPI_SD2), U104.3 (IO2)
/FLASH_IO3: U103.51 (QSPI_SD3), U104.7 (IO3)
/FLASH_nCS: R107.1, R108.2, U103.56 (QSPI_SS), U104.1 (~CS)
/LED_CLK_3V3: U102.2 (1A), U103.13 (GPIO10)
/LED_CLK_5V0: J101.2, U102.7 (1B)
/LED_MOSI_3V3: U102.3 (2A), U103.14 (GPIO11)
/LED_MOSI_5V0: J101.1, U102.6 (2B)
/LED_SPI_DIR: R102.1, R103.2, U102.5 (DIR)
/MIC_CLK: MK101.2 (CLOCK), U103.8 (GPIO6)
/MIC_MISO: MK101.1 (DATA), U103.6 (GPIO4)
/MIC_SELECT: MK101.3 (SELECT), R106.2
/OSC_IN: C119.2, U103.20 (XIN), Y101.1
/OSC_OUT: R109.2, U103.21 (XOUT)
/OSC_OUT_DIV: C118.2, R109.1, Y101.3
/RESET_BUTTON: JP104.2 (C), JP105.1 (A), SW101.2
/SPARE_0_3V3: Q101.1 (S), RN101.8 (R1.2), U103.2 (GPIO0)
/SPARE_0_5V0: J101.7, Q101.6 (D), RN101.6 (R3.2)
/SPARE_1_3V3: Q101.4 (S), RN101.7 (R2.2), U103.3 (GPIO1)
/SPARE_1_5V0: J101.8, Q101.3 (D), RN101.5 (R4.2)
/SWCLK: J102.4, U103.24 (SWCLK)
/SWDIO: J102.2, U103.25 (SWD)
/USB_D_N: J103.2 (D-), R105.1
/USB_D_P: J103.3 (D+), R104.1
/USB_D_TERM_N: R105.2, U103.46 (USB_DM)
/USB_D_TERM_P: R104.2, U103.47 (USB_DP)
/USER_BUTTON_1: SW102.2, U103.15 (GPIO12)
/USER_BUTTON_2: JP105.2 (B), U103.16 (GPIO13)
/VDD_DBG: D102.2 (A), J102.1
/VDD_OR_GND: J101.3, J101.6, JP107.2 (C)
/VDD_USB: D103.2 (A), J103.1 (VBUS)
/nRESET: C115.1, JP101.2 (B), JP104.3 (B), U103.26 (RUN)
/nRESET_SWD: J102.10, JP101.1 (A)
GND: C101.2, C102.2, C103.2, C104.2, C105.2, C106.2, C107.2, C108.2, C109.2, C110.2, C111.2, C112.2, C113.2, C114.2, C115.2, C116.2, C117.2, C118.1, C119.1, H101.1, H102.1, J102.5, J103.5 (GND), J103.6 (Shield), JP106.1 (A), JP107.3 (B), MK101.5 (GND), R103.1, R110.1, SW101.1, SW102.1, U101.2 (GND), U102.4 (GND), U103.57 (GND), U104.4 (GND), Y101.2, Y101.4
VBUS: D102.1 (K), D103.1 (K), JP102.2 (C)
VDD: D101.2 (A), J101.4, J101.5, JP102.3 (B), JP107.1 (A)

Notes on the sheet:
It's important that +3V3 turns on quickly because the RP2040 has a lower on voltage than the flash and if it's too slow the RP2040 will attempt to read from flash before it's ready. This is especially a concern because +5V0 has a lot of capacitance on the display and power boards to support all the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
PWM_3_A
Or if you'd rather use it as another user button.
PWM_1_A
UART_1_TX
Use this solder jumper if the DEBUG device requires the ability to trigger a HARDWARE RESET on the RP2040.
PWM_4_A
UART_0_RX/I2C_0_SCL/PWM_0_B
SPI_1_SCK
UART_1_RX
Use this solder jumper to chose between the providing power from the USB/DEBUG connectors to only this board or to the LEDs as well.
100n for each IOVDD (6), USB_VDD, ADC_AVDD and DVDD (2) 1u for VREG_IN and VREG_OUT
Select whether the reset button toggles power or the reset pin.
SPI_1_TX
SPI_0_RX
SPI_0_SCK
UART_0_TX/I2C_0_SDA/PWM_0_A
Use this solder jumper to chose between using the cable to carry the return current or rely soley on the hinges. Might be useful when driving the display using the debug/usb power.
The RP2040 uses the QSPI_SS pin to determine whether to boot from external flash (high) or from USB (low). This solder jumper provides the option to force the pin low (just short it with something conductive) and subsequently allow the RP2040 to boot from USB.

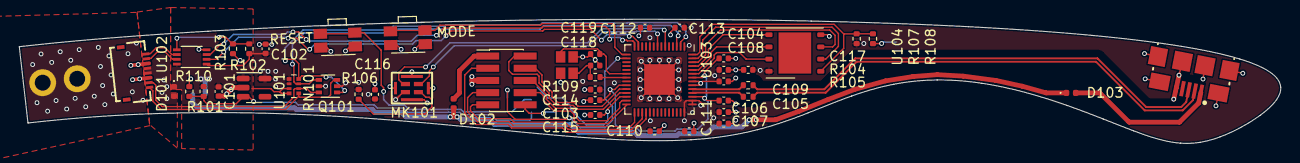
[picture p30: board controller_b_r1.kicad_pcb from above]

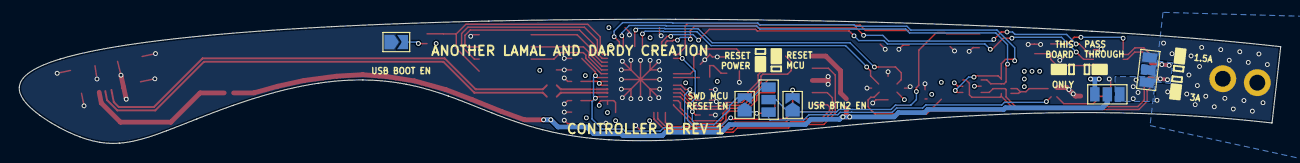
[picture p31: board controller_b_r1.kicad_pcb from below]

Board: 4 copper layers, 131.5 x 12.9 mm, 53 parts (6 on the bottom side), 48 nets.

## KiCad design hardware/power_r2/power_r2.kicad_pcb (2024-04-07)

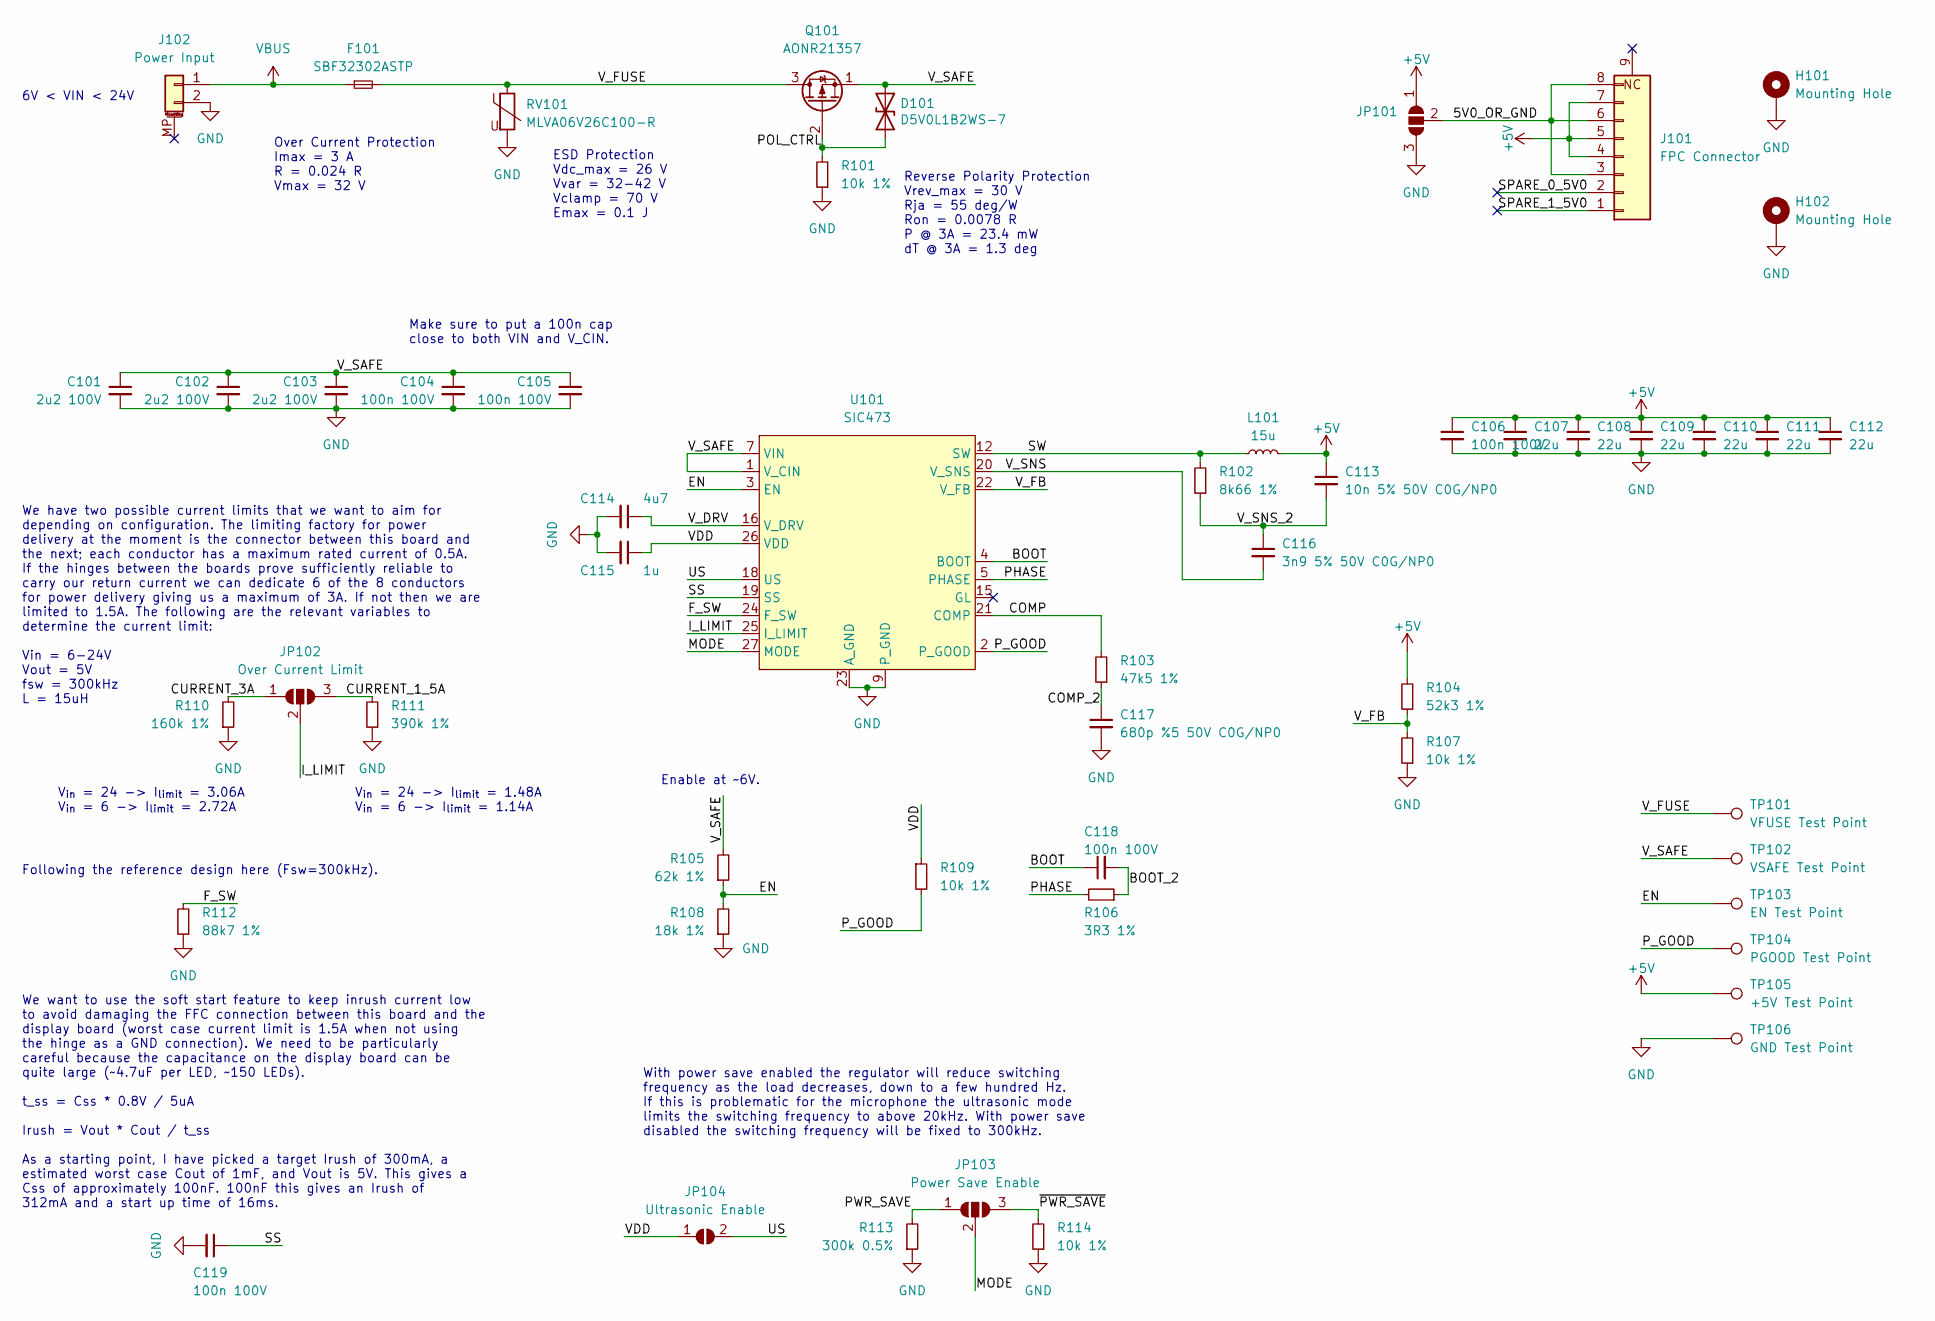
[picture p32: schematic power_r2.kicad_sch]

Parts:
C101, C102, C103: 2u2 100V; C_1210_3225Metric
C104, C105, C106, C118, C119: 100n 100V; C_0402_1005Metric
C107, C108, C109, C110, C111, C112: 22u; C_0805_2012Metric
C113: 10n 5% 50V C0G/NP0; C_0603_1608Metric
C114: 4u7; C_0402_1005Metric
C115: 1u; C_0402_1005Metric
C116: 3n9 5% 50V C0G/NP0; C_0603_1608Metric
C117: 680p %5 50V C0G/NP0; C_0603_1608Metric
D101: D5V0L1B2WS-7; D_SOD-323
F101: SBF32302ASTP; Fuse_1206_3216Metric
H101, H102: Mounting Hole; M1.4 Mounting Hole
J101: FPC Connector; CF35082D0RE-NH
J102: Power Input; JST_PH_S2B-PH-SM4-TB_1x02-1MP_P2.00mm_Horizontal
JP101: Hinge GND Enable; SolderJumper-3_P1.3mm_Open_Pad1.0x1.5mm
JP102: Over Current Limit; SolderJumper-3_P1.3mm_Open_Pad1.0x1.5mm
JP103: Power Save Enable; SolderJumper-3_P1.3mm_Open_Pad1.0x1.5mm
JP104: Ultrasonic Enable; SolderJumper-2_P1.3mm_Open_Pad1.0x1.5mm
L101: 15u; MPXV1D1054
Q101: AONR21357; 8-PowerVDFN (8-DFN-EP) (3x3mm)
R101, R107, R109, R114: 10k 1%; R_0402_1005Metric
R102: 8k66 1%; R_0402_1005Metric
R103: 47k5 1%; R_0402_1005Metric
R104: 52k3 1%; R_0402_1005Metric
R105: 62k 1%; R_0402_1005Metric
R106: 3R3 1%; R_0402_1005Metric
R108: 18k 1%; R_0402_1005Metric
R110: 160k 1%; R_0402_1005Metric
R111: 390k 1%; R_0402_1005Metric
R112: 88k7 1%; R_0402_1005Metric
R113: 300k 0.5%; R_0402_1005Metric
RV101: MLVA06V26C100-R; R_0603_1608Metric
TP101: VFUSE Test Point; TestPoint_Pad_D1.5mm
TP102: VSAFE Test Point; TestPoint_Pad_D1.5mm
TP103: EN Test Point; TestPoint_Pad_D1.5mm
TP104: PGOOD Test Point; TestPoint_Pad_D1.5mm
TP105: +5V Test Point; TestPoint_Pad_D1.5mm
TP106: GND Test Point; TestPoint_Pad_D1.5mm
U101: SIC473; Vishay PowerPAK MLP55-27

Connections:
+5V: C106.1, C107.1, C108.1, C109.1, C110.1, C111.1, C112.1, C113.1, J101.4, J101.5, J101.7, JP101.1 (A), L101.2, R104.2, TP105.1
/5V0_OR_GND: J101.3, J101.6, J101.8, JP101.2 (C)
/BOOT: C118.1, U101.4 (BOOT)
/BOOT_2: C118.2, R106.1
/COMP: R103.2, U101.21 (COMP)
/COMP_2: C117.1, R103.1
/CURRENT_1_5A: JP102.3 (B), R111.2
/CURRENT_3A: JP102.1 (A), R110.2
/EN: R105.1, R108.2, TP103.1, U101.3 (EN)
/F_SW: R112.2, U101.24 (F_SW)
/I_LIMIT: JP102.2 (C), U101.25 (I_LIMIT)
/MODE: JP103.2 (C), U101.27 (MODE)
/PHASE: R106.2, U101.5 (PHASE)
/POL_CTRL: D101.2 (A2), Q101.2 (G), R101.2
/PWR_SAVE: JP103.1 (A), R113.2
/P_GOOD: R109.2, TP104.1, U101.2 (P_GOOD)
/SPARE_0_5V0: J101.2
/SPARE_1_5V0: J101.1
/SS: C119.1, U101.19 (SS)
/SW: L101.1, R102.2, U101.12 (SW)
/US: JP104.2 (B), U101.18 (US)
/VDD: C115.1, JP104.1 (A), R109.1, U101.26 (VDD)
/V_DRV: C114.1, U101.16 (V_DRV)
/V_FB: R104.1, R107.2, U101.22 (V_FB)
/V_FUSE: F101.2, Q101.3 (D), RV101.1, TP101.1
/V_SAFE: C101.1, C102.1, C103.1, C104.1, C105.1, D101.1 (A1), Q101.1 (S), R105.2, TP102.1, U101.1 (V_CIN), U101.7 (VIN)
/V_SNS: C116.2, U101.20 (V_SNS)
/V_SNS_2: C113.2, C116.1, R102.1
/~PWR_SAVE: JP103.3 (B), R114.2
GND: C101.2, C102.2, C103.2, C104.2, C105.2, C106.2, C107.2, C108.2, C109.2, C110.2, C111.2, C112.2, C114.2, C115.2, C117.2, C119.2, H101.1, H102.1, J102.2, JP101.3 (B), R101.1, R107.1, R108.1, R110.1, R111.1, R112.1, R113.1, R114.1, RV101.2, TP106.1, U101.9 (P_GND), U101.23 (A_GND)
VBUS: F101.1, J102.1

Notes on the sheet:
V_{in} = 24 -> I_{limit} = 3.06A V_{in} = 6 -> I_{limit} = 2.72A
6V < VIN < 24V
Reverse Polarity Protection Vrev_max = 30 V Rja = 55 deg/W Ron = 0.0078 R P @ 3A = 23.4 mW dT @ 3A = 1.3 deg
Make sure to put a 100n cap close to both VIN and V_CIN.
We want to use the soft start feature to keep inrush current low to avoid damaging the FFC connection between this board and the display board (worst case current limit is 1.5A when not using the hinge as a GND connection). We need to be particularly careful because the capacitance on the display b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
ESD Protection Vdc_max = 26 V Vvar = 32-42 V Vclamp = 70 V Emax = 0.1 J
We have two possible current limits that we want to aim for depending on configuration. The limiting factory for power delivery at the moment is the connector between this board and the next; each conductor has a maximum rated current of 0.5A. If the hinges between the boards prove sufficiently rel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
With power save enabled the regulator will reduce switching frequency as the load decreases, down to a few hundred Hz. If this is problematic for the microphone the ultrasonic mode limits the switching frequency to above 20kHz. With power save disabled the switching frequency will be fixed to 300kH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
Over Current Protection Imax = 3 A R = 0.024 R Vmax = 32 V
Enable at ~6V.
V_{in} = 24 -> I_{limit} = 1.48A V_{in} = 6 -> I_{limit} = 1.14A
Following the reference design here (Fsw=300kHz).

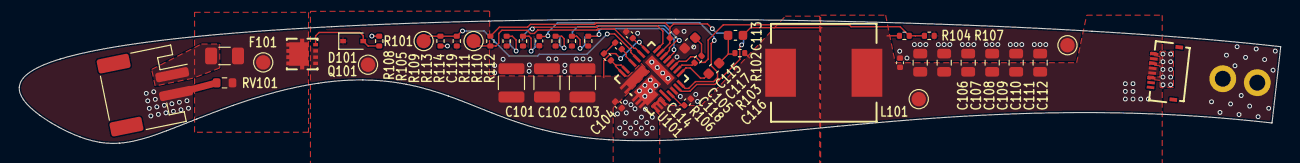
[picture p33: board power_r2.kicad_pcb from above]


Board: 4 copper layers, 131.5 x 12.9 mm, 53 parts (4 on the bottom side), 29 nets.

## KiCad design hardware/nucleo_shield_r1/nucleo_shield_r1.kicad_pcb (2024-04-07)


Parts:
D101, D102, D103: LED; LED_0805_2012Metric_Pad1.15x1.40mm_HandSolder
J101: UART; PinSocket_1x02_P2.54mm_Vertical
J102: UART SELECTOR; PinHeader_2x02_P2.54mm_Vertical
J103: SWD; PinSocket_1x06_P2.54mm_Vertical
J104: SWD Header; PinHeader_2x05_P1.27mm_Vertical_SMD
J105: Conn_01x10; PinHeader_1x10_P2.54mm_Vertical
J106: POWER; PinHeader_1x08_P2.54mm_Vertical
J107: Conn_01x06; PinHeader_1x06_P2.54mm_Vertical
J108: Conn_01x08; PinHeader_1x08_P2.54mm_Vertical
Q101, Q102: Q_Dual_NMOS_S1G1D2S2G2D1; SOT-363_SC-70-6_Handsoldering
R101, R102, R103: 1k; R_0805_2012Metric_Pad1.20x1.40mm_HandSolder

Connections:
+5V: J104.1, J106.5, R101.1, R102.1, R103.1
/DBG_LED_0: J104.6, Q101.2 (G)
/DBG_LED_1: J104.8, Q101.5 (G)
/DBG_LED_2: J104.9, Q102.2 (G)
/DBG_UART_RX: J102.1, J104.3
/DBG_UART_TX: J102.4, J104.7
/NUCLEO_UART_RX: J101.1, J102.2
/NUCLEO_UART_TX: J101.2, J102.3
/SWCLK: J103.2, J104.4
/SWDIO: J103.4, J104.2
/nRESET: J103.5, J104.10
GND: J103.3, J104.5, J106.6, J106.7, Q101.1 (S), Q101.4 (S), Q102.1 (S)
unnamed: D101.1 (K), Q101.6 (D)
unnamed: D101.2 (A), R101.2
unnamed: D102.1 (K), Q101.3 (D)
unnamed: D102.2 (A), R102.2
unnamed: D103.1 (K), Q102.6 (D)
unnamed: D103.2 (A), R103.2



Board: 2 copper layers, 70.0 x 80.0 mm, 16 parts (6 on the bottom side), 18 nets.

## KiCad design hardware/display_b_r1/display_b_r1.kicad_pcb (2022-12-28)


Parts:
C101, C102, C103, C104, C105, C106, C107, C108, C109, C110, C111, C112, C113, C114, C115, C116, C117, C118, C119, C120, C121, C122, C123, C124, C125, C126, C127, C129, C130, C131, C132, C133, C134, C135, C136, C137, C138, C139, C140, C141, C142, C143, C144, C145, C146, C147: 22u 10V; C_0603_1608Metric
D101, D102, D103, D104, D107, D108, D109, D110, D111, D112, D113, D114, D115, D116, D117, D118, D119, D120, D121, D122, D123, D124, D125, D126, D127, D128, D129, D130, D131, D132, D133, D134, D135, D136, D137, D138, D139, D140, D142, D143, D144, D145, D146, D147, D148, D149, D151, D152, D153, D154, D155, D156, D157, D158, D160, D161, D162, D163, D164, D165, D166, D167, D169, D170, D172, D173, D174, D175, D176, D178, D179, D180, D182, D183, D185, D187, D188, D189, D191, D192, D193, D194, D195, D196, D197, D199, D200, D202, D203, D204, D205, D206, D207, D208, D209, D210, D211, D212, D213, D214, D215, D216, D217, D218, D219, D220, D221, D222, D223, D224, D225, D226, D228, D229, D230, D231, D232, D233, D234, D235, D237, D238, D239, D240, D241, D242, D243, D244, D246, D247, D248, D249, D250, D251, D252, D253, D255, D256, D257, D258, D259, D260, D261, D262, D264, D265, D266, D267, D270, D271: APA102-2020; LED-APA102-2020
H101, H102, H103, H104: MountingHole_Pad; M1.4 Mounting Hole
J101, J102: Conn_01x08; CF35082D0RE-NH
JP101, JP102: SolderJumper_3_Open; SolderJumper-3_P1.3mm_Open_Pad1.0x1.5mm

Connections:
+5V: C101.1, C102.1, C103.1, C104.1, C105.1, C106.1, C107.1, C108.1, C109.1, C110.1, C111.1, C112.1, C113.1, C114.1, C115.1, C116.1, C117.1, C118.1, C119.1, C120.1, C121.1, C122.1, C123.1, C124.1, C125.1, C126.1, C127.1, C129.1, C130.1, C131.1, C132.1, C133.1, C134.1, C135.1, C136.1, C137.1, C138.1, C139.1, C140.1, C141.1, C142.1, C143.1, C144.1, C145.1, C146.1, C147.1, D101.1 (VDD), D102.1 (VDD), D103.1 (VDD), D104.1 (VDD), D107.1 (VDD), D108.1 (VDD), D109.1 (VDD), D110.1 (VDD), D111.1 (VDD), D112.1 (VDD), D113.1 (VDD), D114.1 (VDD), D115.1 (VDD), D116.1 (VDD), D117.1 (VDD), D118.1 (VDD), D119.1 (VDD), D120.1 (VDD), D121.1 (VDD), D122.1 (VDD), D123.1 (VDD), D124.1 (VDD), D125.1 (VDD), D126.1 (VDD), D127.1 (VDD), D128.1 (VDD), D129.1 (VDD), D130.1 (VDD), D131.1 (VDD), D132.1 (VDD), D133.1 (VDD), D134.1 (VDD), D135.1 (VDD), D136.1 (VDD), D137.1 (VDD), D138.1 (VDD), D139.1 (VDD), D140.1 (VDD), D142.1 (VDD), D143.1 (VDD), D144.1 (VDD), D145.1 (VDD), D146.1 (VDD), D147.1 (VDD), D148.1 (VDD), D149.1 (VDD), D151.1 (VDD), D152.1 (VDD), D153.1 (VDD), D154.1 (VDD), D155.1 (VDD), D156.1 (VDD), D157.1 (VDD), D158.1 (VDD), D160.1 (VDD), D161.1 (VDD), D162.1 (VDD), D163.1 (VDD), D164.1 (VDD), D165.1 (VDD), D166.1 (VDD), D167.1 (VDD), D169.1 (VDD), D170.1 (VDD), D172.1 (VDD), D173.1 (VDD), D174.1 (VDD), D175.1 (VDD), D176.1 (VDD), D178.1 (VDD), D179.1 (VDD), D180.1 (VDD), D182.1 (VDD), D183.1 (VDD), D185.1 (VDD), D187.1 (VDD), D188.1 (VDD), D189.1 (VDD), D191.1 (VDD), D192.1 (VDD), D193.1 (VDD), D194.1 (VDD), D195.1 (VDD), D196.1 (VDD), D197.1 (VDD), D199.1 (VDD), D200.1 (VDD), D202.1 (VDD), D203.1 (VDD), D204.1 (VDD), D205.1 (VDD), D206.1 (VDD), D207.1 (VDD), D208.1 (VDD), D209.1 (VDD), D210.1 (VDD), D211.1 (VDD), D212.1 (VDD), D213.1 (VDD), D214.1 (VDD), D215.1 (VDD), D216.1 (VDD), D217.1 (VDD), D218.1 (VDD), D219.1 (VDD), D220.1 (VDD), D221.1 (VDD), D222.1 (VDD), D223.1 (VDD), D224.1 (VDD), D225.1 (VDD), D226.1 (VDD), D228.1 (VDD), D229.1 (VDD), D230.1 (VDD), D231.1 (VDD), D232.1 (VDD), D233.1 (VDD), D234.1 (VDD), D235.1 (VDD), D237.1 (VDD), D238.1 (VDD), D239.1 (VDD), D240.1 (VDD), D241.1 (VDD), D242.1 (VDD), D243.1 (VDD), D244.1 (VDD), D246.1 (VDD), D247.1 (VDD), D248.1 (VDD), D249.1 (VDD), D250.1 (VDD), D251.1 (VDD), D252.1 (VDD), D253.1 (VDD), D255.1 (VDD), D256.1 (VDD), D257.1 (VDD), D258.1 (VDD), D259.1 (VDD), D260.1 (VDD), D261.1 (VDD), D262.1 (VDD), D264.1 (VDD), D265.1 (VDD), D266.1 (VDD), D267.1 (VDD), D270.1 (VDD), D271.1 (VDD), J101.2, J101.4, J101.5, J102.4, J102.5, JP101.1 (A), JP102.1 (A)
/5V0_OR_GND_1: J101.1, J101.3, J101.6, JP101.2 (C)
/5V0_OR_GND_2: J102.3, J102.6, JP102.2 (C)
/LED_CLK_5V0: D264.5 (CKI), J102.7
/LED_MOSI_5V0: D264.4 (SDI), J102.8
/SPARE_0_5V0: J101.7, J102.2
/SPARE_1_5V0: J101.8, J102.1
GND: C101.2, C102.2, C103.2, C104.2, C105.2, C106.2, C107.2, C108.2, C109.2, C110.2, C111.2, C112.2, C113.2, C114.2, C115.2, C116.2, C117.2, C118.2, C119.2, C120.2, C121.2, C122.2, C123.2, C124.2, C125.2, C126.2, C127.2, C129.2, C130.2, C131.2, C132.2, C133.2, C134.2, C135.2, C136.2, C137.2, C138.2, C139.2, C140.2, C141.2, C142.2, C143.2, C144.2, C145.2, C146.2, C147.2, D101.6 (GND), D102.6 (GND), D103.6 (GND), D104.6 (GND), D107.6 (GND), D108.6 (GND), D109.6 (GND), D110.6 (GND), D111.6 (GND), D112.6 (GND), D113.6 (GND), D114.6 (GND), D115.6 (GND), D116.6 (GND), D117.6 (GND), D118.6 (GND), D119.6 (GND), D120.6 (GND), D121.6 (GND), D122.6 (GND), D123.6 (GND), D124.6 (GND), D125.6 (GND), D126.6 (GND), D127.6 (GND), D128.6 (GND), D129.6 (GND), D130.6 (GND), D131.6 (GND), D132.6 (GND), D133.6 (GND), D134.6 (GND), D135.6 (GND), D136.6 (GND), D137.6 (GND), D138.6 (GND), D139.6 (GND), D140.6 (GND), D142.6 (GND), D143.6 (GND), D144.6 (GND), D145.6 (GND), D146.6 (GND), D147.6 (GND), D148.6 (GND), D149.6 (GND), D151.6 (GND), D152.6 (GND), D153.6 (GND), D154.6 (GND), D155.6 (GND), D156.6 (GND), D157.6 (GND), D158.6 (GND), D160.6 (GND), D161.6 (GND), D162.6 (GND), D163.6 (GND), D164.6 (GND), D165.6 (GND), D166.6 (GND), D167.6 (GND), D169.6 (GND), D170.6 (GND), D172.6 (GND), D173.6 (GND), D174.6 (GND), D175.6 (GND), D176.6 (GND), D178.6 (GND), D179.6 (GND), D180.6 (GND), D182.6 (GND), D183.6 (GND), D185.6 (GND), D187.6 (GND), D188.6 (GND), D189.6 (GND), D191.6 (GND), D192.6 (GND), D193.6 (GND), D194.6 (GND), D195.6 (GND), D196.6 (GND), D197.6 (GND), D199.6 (GND), D200.6 (GND), D202.6 (GND), D203.6 (GND), D204.6 (GND), D205.6 (GND), D206.6 (GND), D207.6 (GND), D208.6 (GND), D209.6 (GND), D210.6 (GND), D211.6 (GND), D212.6 (GND), D213.6 (GND), D214.6 (GND), D215.6 (GND), D216.6 (GND), D217.6 (GND), D218.6 (GND), D219.6 (GND), D220.6 (GND), D221.6 (GND), D222.6 (GND), D223.6 (GND), D224.6 (GND), D225.6 (GND), D226.6 (GND), D228.6 (GND), D229.6 (GND), D230.6 (GND), D231.6 (GND), D232.6 (GND), D233.6 (GND), D234.6 (GND), D235.6 (GND), D237.6 (GND), D238.6 (GND), D239.6 (GND), D240.6 (GND), D241.6 (GND), D242.6 (GND), D243.6 (GND), D244.6 (GND), D246.6 (GND), D247.6 (GND), D248.6 (GND), D249.6 (GND), D250.6 (GND), D251.6 (GND), D252.6 (GND), D253.6 (GND), D255.6 (GND), D256.6 (GND), D257.6 (GND), D258.6 (GND), D259.6 (GND), D260.6 (GND), D261.6 (GND), D262.6 (GND), D264.6 (GND), D265.6 (GND), D266.6 (GND), D267.6 (GND), D270.6 (GND), D271.6 (GND), H101.1, H102.1, H103.1, H104.1, J101.9 (NC), J102.9 (NC), JP101.3 (B), JP102.3 (B)
unnamed: D101.2 (CKO), D102.5 (CKI)
unnamed: D101.3 (SDO), D102.4 (SDI)
unnamed: D101.4 (SDI), D109.3 (SDO)
unnamed: D101.5 (CKI), D109.2 (CKO)
unnamed: D102.2 (CKO), D110.5 (CKI)
unnamed: D102.3 (SDO), D110.4 (SDI)
unnamed: D103.2 (CKO), D104.5 (CKI)
unnamed: D103.3 (SDO), D104.4 (SDI)
unnamed: D103.4 (SDI), D111.3 (SDO)
unnamed: D103.5 (CKI), D111.2 (CKO)
unnamed: D104.2 (CKO), D112.5 (CKI)
unnamed: D104.3 (SDO), D112.4 (SDI)
unnamed: D107.2 (CKO), D108.5 (CKI)
unnamed: D107.3 (SDO), D108.4 (SDI)
unnamed: D107.4 (SDI), D115.3 (SDO)
unnamed: D107.5 (CKI), D115.2 (CKO)
unnamed: D108.2 (CKO), D116.5 (CKI)
unnamed: D108.3 (SDO), D116.4 (SDI)
unnamed: D109.4 (SDI), D117.3 (SDO)
unnamed: D109.5 (CKI), D117.2 (CKO)
unnamed: D110.2 (CKO), D118.5 (CKI)
unnamed: D110.3 (SDO), D118.4 (SDI)
unnamed: D111.4 (SDI), D119.3 (SDO)
unnamed: D111.5 (CKI), D119.2 (CKO)
unnamed: D112.2 (CKO), D120.5 (CKI)
unnamed: D112.3 (SDO), D120.4 (SDI)
unnamed: D113.2 (CKO), D114.5 (CKI)
unnamed: D113.3 (SDO), D114.4 (SDI)
unnamed: D113.4 (SDI), D121.3 (SDO)
unnamed: D113.5 (CKI), D121.2 (CKO)
unnamed: D114.2 (CKO), D122.5 (CKI)
unnamed: D114.3 (SDO), D122.4 (SDI)
unnamed: D115.4 (SDI), D123.3 (SDO)
unnamed: D115.5 (CKI), D123.2 (CKO)
unnamed: D116.2 (CKO), D124.5 (CKI)
unnamed: D116.3 (SDO), D124.4 (SDI)
unnamed: D117.4 (SDI), D125.3 (SDO)
unnamed: D117.5 (CKI), D125.2 (CKO)
unnamed: D118.2 (CKO), D126.5 (CKI)
unnamed: D118.3 (SDO), D126.4 (SDI)
unnamed: D119.4 (SDI), D127.3 (SDO)
unnamed: D119.5 (CKI), D127.2 (CKO)
unnamed: D120.2 (CKO), D128.5 (CKI)
unnamed: D120.3 (SDO), D128.4 (SDI)
unnamed: D121.4 (SDI), D129.3 (SDO)
unnamed: D121.5 (CKI), D129.2 (CKO)
unnamed: D122.2 (CKO), D130.5 (CKI)
unnamed: D122.3 (SDO), D130.4 (SDI)
unnamed: D123.4 (SDI), D131.3 (SDO)
unnamed: D123.5 (CKI), D131.2 (CKO)
unnamed: D124.2 (CKO), D132.5 (CKI)
unnamed: D124.3 (SDO), D132.4 (SDI)
unnamed: D125.4 (SDI), D133.3 (SDO)
unnamed: D125.5 (CKI), D133.2 (CKO)
unnamed: D126.2 (CKO), D134.5 (CKI)
unnamed: D126.3 (SDO), D134.4 (SDI)
unnamed: D127.4 (SDI), D135.3 (SDO)
unnamed: D127.5 (CKI), D135.2 (CKO)
unnamed: D128.2 (CKO), D136.5 (CKI)
unnamed: D128.3 (SDO), D136.4 (SDI)
unnamed: D129.4 (SDI), D137.3 (SDO)
unnamed: D129.5 (CKI), D137.2 (CKO)
unnamed: D130.2 (CKO), D138.5 (CKI)
unnamed: D130.3 (SDO), D138.4 (SDI)
unnamed: D131.4 (SDI), D139.3 (SDO)
unnamed: D131.5 (CKI), D139.2 (CKO)
unnamed: D132.2 (CKO), D140.5 (CKI)
unnamed: D132.3 (SDO), D140.4 (SDI)
unnamed: D133.4 (SDI), D142.3 (SDO)
unnamed: D133.5 (CKI), D142.2 (CKO)
unnamed: D134.2 (CKO), D143.5 (CKI)
unnamed: D134.3 (SDO), D143.4 (SDI)
unnamed: D135.4 (SDI), D144.3 (SDO)
unnamed: D135.5 (CKI), D144.2 (CKO)
unnamed: D136.2 (CKO), D145.5 (CKI)
unnamed: D136.3 (SDO), D145.4 (SDI)
unnamed: D137.4 (SDI), D146.3 (SDO)
unnamed: D137.5 (CKI), D146.2 (CKO)
unnamed: D138.2 (CKO), D147.5 (CKI)
unnamed: D138.3 (SDO), D147.4 (SDI)
unnamed: D139.4 (SDI), D148.3 (SDO)
unnamed: D139.5 (CKI), D148.2 (CKO)
unnamed: D140.2 (CKO), D149.5 (CKI)
unnamed: D140.3 (SDO), D149.4 (SDI)
unnamed: D142.4 (SDI), D151.3 (SDO)
unnamed: D142.5 (CKI), D151.2 (CKO)
unnamed: D143.2 (CKO), D152.5 (CKI)
unnamed: D143.3 (SDO), D152.4 (SDI)
unnamed: D144.4 (SDI), D153.3 (SDO)
unnamed: D144.5 (CKI), D153.2 (CKO)
unnamed: D145.2 (CKO), D154.5 (CKI)
unnamed: D145.3 (SDO), D154.4 (SDI)
unnamed: D146.4 (SDI), D155.3 (SDO)
unnamed: D146.5 (CKI), D155.2 (CKO)
unnamed: D147.2 (CKO), D156.5 (CKI)
unnamed: D147.3 (SDO), D156.4 (SDI)
unnamed: D148.4 (SDI), D157.3 (SDO)
unnamed: D148.5 (CKI), D157.2 (CKO)
unnamed: D149.2 (CKO), D158.5 (CKI)
unnamed: D149.3 (SDO), D158.4 (SDI)
unnamed: D151.4 (SDI), D160.3 (SDO)
unnamed: D151.5 (CKI), D160.2 (CKO)
unnamed: D152.2 (CKO), D161.5 (CKI)
unnamed: D152.3 (SDO), D161.4 (SDI)
unnamed: D153.4 (SDI), D162.3 (SDO)
unnamed: D153.5 (CKI), D162.2 (CKO)
unnamed: D154.2 (CKO), D163.5 (CKI)
unnamed: D154.3 (SDO), D163.4 (SDI)
unnamed: D155.4 (SDI), D164.3 (SDO)
unnamed: D155.5 (CKI), D164.2 (CKO)
unnamed: D156.2 (CKO), D165.5 (CKI)
unnamed: D156.3 (SDO), D165.4 (SDI)
unnamed: D157.4 (SDI), D166.3 (SDO)
unnamed: D157.5 (CKI), D166.2 (CKO)
unnamed: D158.2 (CKO), D167.5 (CKI)
unnamed: D158.3 (SDO), D167.4 (SDI)
unnamed: D160.4 (SDI), D169.3 (SDO)
unnamed: D160.5 (CKI), D169.2 (CKO)
unnamed: D161.2 (CKO), D170.5 (CKI)
unnamed: D161.3 (SDO), D170.4 (SDI)
unnamed: D162.4 (SDI), D180.3 (SDO)
unnamed: D162.5 (CKI), D180.2 (CKO)
unnamed: D163.2 (CKO), D172.5 (CKI)
unnamed: D163.3 (SDO), D172.4 (SDI)
unnamed: D164.4 (SDI), D173.3 (SDO)
unnamed: D164.5 (CKI), D173.2 (CKO)
unnamed: D165.2 (CKO), D174.5 (CKI)
unnamed: D165.3 (SDO), D174.4 (SDI)
unnamed: D166.4 (SDI), D175.3 (SDO)
unnamed: D166.5 (CKI), D175.2 (CKO)
unnamed: D167.2 (CKO), D176.5 (CKI)
unnamed: D167.3 (SDO), D176.4 (SDI)
unnamed: D169.4 (SDI), D178.3 (SDO)
unnamed: D169.5 (CKI), D178.2 (CKO)
unnamed: D170.2 (CKO), D179.5 (CKI)
unnamed: D170.3 (SDO), D179.4 (SDI)
unnamed: D172.2 (CKO), D182.5 (CKI)
unnamed: D172.3 (SDO), D182.4 (SDI)
unnamed: D173.4 (SDI), D182.3 (SDO)
unnamed: D173.5 (CKI), D182.2 (CKO)
unnamed: D174.2 (CKO), D183.5 (CKI)
unnamed: D174.3 (SDO), D183.4 (SDI)
unnamed: D175.4 (SDI), D183.3 (SDO)
unnamed: D175.5 (CKI), D183.2 (CKO)
unnamed: D176.2 (CKO), D185.5 (CKI)
unnamed: D176.3 (SDO), D185.4 (SDI)
unnamed: D178.4 (SDI), D271.3 (SDO)
unnamed: D178.5 (CKI), D271.2 (CKO)
unnamed: D179.2 (CKO), D180.5 (CKI)
unnamed: D179.3 (SDO), D180.4 (SDI)
unnamed: D187.2 (CKO), D188.5 (CKI)
unnamed: D187.3 (SDO), D188.4 (SDI)
unnamed: D187.4 (SDI), D195.3 (SDO)
unnamed: D187.5 (CKI), D195.2 (CKO)
unnamed: D188.2 (CKO), D196.5 (CKI)
unnamed: D188.3 (SDO), D196.4 (SDI)
unnamed: D189.2 (CKO), D206.5 (CKI)
unnamed: D189.3 (SDO), D206.4 (SDI)
unnamed: D189.4 (SDI), D197.3 (SDO)
unnamed: D189.5 (CKI), D197.2 (CKO)
unnamed: D191.2 (CKO), D192.5 (CKI)
unnamed: D191.3 (SDO), D192.4 (SDI)
unnamed: D191.4 (SDI), D199.3 (SDO)
unnamed: D191.5 (CKI), D199.2 (CKO)
unnamed: D192.2 (CKO), D200.5 (CKI)
unnamed: D192.3 (SDO), D200.4 (SDI)
unnamed: D193.2 (CKO), D194.5 (CKI)
unnamed: D193.3 (SDO), D194.4 (SDI)
unnamed: D193.4 (SDI), D209.3 (SDO)
unnamed: D193.5 (CKI), D209.2 (CKO)
unnamed: D194.2 (CKO), D202.5 (CKI)
unnamed: D194.3 (SDO), D202.4 (SDI)
unnamed: D195.4 (SDI), D203.3 (SDO)
unnamed: D195.5 (CKI), D203.2 (CKO)
unnamed: D196.2 (CKO), D204.5 (CKI)
unnamed: D196.3 (SDO), D204.4 (SDI)
unnamed: D197.4 (SDI), D205.3 (SDO)
unnamed: D197.5 (CKI), D205.2 (CKO)
unnamed: D199.4 (SDI), D207.3 (SDO)
unnamed: D199.5 (CKI), D207.2 (CKO)
unnamed: D200.2 (CKO), D208.5 (CKI)
unnamed: D200.3 (SDO), D208.4 (SDI)
unnamed: D202.2 (CKO), D210.5 (CKI)
unnamed: D202.3 (SDO), D210.4 (SDI)
unnamed: D203.4 (SDI), D211.3 (SDO)
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

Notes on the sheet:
Use these solder jumpers to chose between using the cable to carry the return current or rely soley on the hinges. Might be needed to provide sufficient current but the hinges could prove unreliable connectors.

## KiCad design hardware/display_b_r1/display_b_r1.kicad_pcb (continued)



Board: 2 copper layers, 155.0 x 54.5 mm, 205 parts (2 on the bottom side), 306 nets.

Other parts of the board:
Ref**: Val**; template_display_b_r1

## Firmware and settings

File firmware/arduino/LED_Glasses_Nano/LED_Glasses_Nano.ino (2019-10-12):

// For the 8-bit art
//https://make8bitart.com/

// Libraries
#include <Adafruit_NeoPixel.h>
#include <Adafruit_NeoMatrix.h>
#include <Adafruit_GFX.h>
#include <arduinoFFT.h>
#include <Fonts/Picopixel.h>

byte DATAPIN = 3; // Arduino PWM data pin D6
byte NUMPIXELS = 84;   // Number of neopixels

// Parameter 1 = number of pixels in strip
// Parameter 2 = pin number (most are valid)
// Parameter 3 = pixel type flags, add together as needed:
//   NEO_KHZ800  800 KHz bitstream (most NeoPixel products w/WS2812 LEDs)
//   NEO_KHZ400  400 KHz (classic 'v1' (not v2) FLORA pixels, WS2811 drivers)
//   NEO_GRB     Pixels are wired for GRB bitstream (most NeoPixel products)
//   NEO_RGB     Pixels are wired for RGB bitstream (v1 FLORA pixels, not v2)
Adafruit_NeoPixel pixels = Adafruit_NeoPixel(NUMPIXELS, DATAPIN, NEO_GRB + NEO_KHZ800);

// Declare the NeoMatrix
byte matrixWidth = 7;
byte matrixHeight = 6;
byte tilesX = 2;
byte tilesY = 1;
Adafruit_NeoMatrix matrix = Adafruit_NeoMatrix(
  matrixWidth, matrixHeight, tilesX, tilesY, DATAPIN, NEO_TILE_BOTTOM+NEO_TILE_RIGHT+NEO_TILE_ROWS+NEO_TILE_ZIGZAG, NEO_GRB + NEO_KHZ800);

// LED Array Setup
#define NUMROWS 6
#define NUMCOLS 14
#define NUMCOLOURS 15
byte BRIGHTNESS = 25;

// Millis setup
unsigned long previousMillis = 0;
byte interval = 10;

// push button setup
byte buttonPin = 2;
bool buttonState = false;
bool prevState = false;
byte numSel = 11;
byte sel = 0;
byte prevColour=0;
byte newColour=0;

// potentiometer setup
word potVal = 0;
float brightnessFactor = 1;

// microphone setup
const byte sampleWindow = 15;     // sample window width in ms (50ms = 20Hz)
unsigned int sample;
const byte maxScale = 6;
const byte redZone = 5;
const byte buffer_size = 14;
byte buffer_index = 0;
byte displayPeakVals [buffer_size];   // array to store previous 14 displayPeaks for display

// FFT Setup
#define SAMPLES 32    // must be a power of 2
#define SAMPLING_FREQ 1000  //Hz, must be less than 10000 due to ADC
double vReal[SAMPLES];
double vImag[SAMPLES];
char data_avgs[NUMCOLS];
arduinoFFT FFT = arduinoFFT();
unsigned long microseconds;
unsigned int sampling_period_us;

float red=0;    // values: 0.0, 0.25, 0.5 0.75, 1
float green=0;  
float blue=0;

#define NUMCOLOURS 15
uint16_t colour = matrix.Color(0, 0, 0);

float colourArray [NUMCOLOURS][3] = {
  {0, 0, 0},    // off            #0
  {1, 1, 1},    // white          #1
  {1, 0, 0},    // red            #2
  {0, 1, 0},    // green          #3
  {0, 0, 1},    // blue           #4
  {1, 1, 0},    // yellow         #5
  {1, 0, 1},    // purple         #6
  {0, 1, 1},    // torqouise      #7

  {0.5, 1, 1},  //light blue      #8
  {1, 0.5, 1},  //light pink      #9
  {1, 1, 0.5},  //light yellow    #10

  {0.5, 0, 1},  //grape           #11
  {1, 0, 0.5},  //dark pink       #12
  {0, 0.5, 1},  //pale blue       #13

  {0.75, 0.5, 0},//orange         #14
};

int fftArray[NUMCOLS] = {11, 11, 6, 6, 4, 4, 7, 7, 3, 3, 5, 5, 2, 2};

const byte glassesArray[NUMROWS][NUMCOLS] = {
  {48, 47, 46, 45, 44, 43, 42, 35, 36, 37, 38, 39, 40, 41},
  {49, 50, 51, 52, 53, 54, 55, 34, 33, 32, 31, 30, 29, 28},
  {62, 61, 60, 59, 58, 57, 56, 21, 22, 23, 24, 25, 26, 27},
  {63, 64, 65, 66, 67, 68, 69, 20, 19, 18, 17, 16, 15, 14},
  {76, 75, 74, 73, 72, 71, 70, 7, 8, 9, 10, 11, 12, 13},
  {77, 78, 79, 80, 81, 82, 83, 6, 5, 4, 3, 2, 1, 0}
};

// setup animations
word frame = 0;
byte centreX = 3;
byte centreY = 3;

// setup pong animation
byte x_coord = 0;
byte y_coord = 0;
bool x_dir = 0;
bool y_dir = 0;
byte x_upp_lim = 13;
byte x_low_lim = 0;
byte y_upp_lim = 5;
byte y_low_lim = 0;
byte red_pad_y = 2;
byte blue_pad_y = 2;
byte red_score = 0;
byte blue_score = 0;
bool scoreFlag = false;
byte prevFrame = 0;

// ---------------------------------------------------- SETUP ---------------------------------------------------- \\

void setup() {
  // put your setup code here, to run once:
  pixels.begin();
  pixels.setBrightness(BRIGHTNESS);
  pixels.show(); // Initialize all pixels to 'off'  

  matrix.begin();
  matrix.setRemapFunction(myRemapFn);
  matrix.setTextWrap(false);
  matrix.setBrightness(BRIGHTNESS);
  matrix.setFont(&Picopixel);

  // Push Button setup
  pinMode(buttonPin, INPUT_PULLUP);
  // potentiometer
  pinMode(A7, INPUT);

  // FFT Setup
//  ADCSRA = 0b11100101;      // set ADC to free running mode and set pre-scalar to 32 (0xe5)
//  ADMUX = 0b00000110;       // use pin A6 and external voltage reference
  sampling_period_us = round(1000000*(1.0/SAMPLING_FREQ));

  Serial.begin(9600);

}

// ---------------------------------------------------- LOOP ---------------------------------------------------- \\

void loop() {
  //Serial.println(sel);
  //delay(1000);
  // frame check (reset once it hits 255)
  if(frame == 65535){
    frame = 0;
  }

  // Map pot value to brightness
  brightnessFactor = (float)map(analogRead(A7), 1008, 6, 0, 127);

  checkButton(frame);

  // Switch statement for the displays (Switch doesnt work???)
  if(sel==0){
    unsigned long currentMillis = millis();
    if((unsigned long) (currentMillis - previousMillis) >= 100){
      previousMillis = millis();
      pong(frame, x_coord, y_coord, x_dir, y_dir, red_pad_y, blue_pad_y, red_score, blue_score, scoreFlag, prevFrame);
//      Serial.print("Blue score: ");
//      Serial.println(blue_score);
//      Serial.print("Red score: ");
//      Serial.println(red_score);
    }
  }
  else if(sel==1){
    // red hearts (can change)
    setColour(2);
    unsigned long currentMillis = millis();
    if((unsigned long) (currentMillis - previousMillis) >= 100){
      previousMillis = millis();
      hearts(frame);
      frame++;
    }
  }
  else if(sel==2){
    setColour(1);
    unsigned long currentMillis = millis();
    if((unsigned long) (currentMillis - previousMillis) >= 20){
      previousMillis = millis();
      sideSide(frame);
      frame++;
    }
  }
  else if(sel==3){
    setColour(1);
    unsigned long currentMillis = millis();
    if((unsigned long) (currentMillis - previousMillis) >= 40){
      previousMillis = millis();
      upDown(frame);
      frame++;
    }
  } 
  else if(sel==4){
    unsigned long currentMillis = millis();
    if((unsigned long) (currentMillis - previousMillis) >= 0.1){
      previousMillis = millis();
      rainbow(frame);
      frame++;
    }
  } 
  else if(sel==5){
    unsigned long currentMillis = millis();
    if((unsigned long) (currentMillis - previousMillis) >= 1){  
      previousMillis = millis();
      colourWipeFrame(frame);
      frame++;
    }
  }
  else if(sel==6){
    unsigned long currentMillis = millis();
    if((unsigned long) (currentMillis - previousMillis) >= 50){
      previousMillis = millis();
      circles(frame);
      frame++;
    }
  }
  else if (sel==7){
    unsigned long currentMillis = millis();
    if((unsigned long) (currentMillis - previousMillis) >= 50){
      previousMillis = millis();
      fftFcn();
      matrix.show();
    }
  }
  else if (sel==8){
    // volume measurement scroll across screen
    volumeScroll();
  }
  else if (sel==9){
    // sine wave display
    unsigned long currentMillis = millis();
    if((unsigned long) (currentMillis - previousMillis) >= 30){
      previousMillis = millis();
      //sineDisplay(frame, amplitude, frequency
      sineDisplay(frame, 1.0, 30);
      frame++;
    }
  }
  else if (sel==10){
    // volume measurement scroll across screen
    volumeScroll();
  }
}

// ---------------------------------------------------- FUNCTIONS ---------------------------------------------------- \\
// ---------------------------------------------------- BACK-BONE ---------------------------------------------------- \\

// Button check
void checkButton(word &frame){
  // Push button
  buttonState = digitalRead(buttonPin);
  
  if(buttonState != prevState){
    if(buttonState == true){
        if(sel < numSel-1){
        sel++;
      }
      else {
        sel=0;
      }
    }
    frame=0;
    matrix.clear();
    pixels.clear();
    matrix.show();
    pixels.show();
    prevState=buttonState;
    delay(100);
    red_score = 0;
    blue_score = 0;
    Serial.println("Push");
  }
}

// Set colour
void setColour(byte sel){
  red = colourArray[sel][0];
  green = colourArray[sel][1];
  blue = colourArray[sel][2];
}

uint16_t myRemapFn(uint16_t x, uint16_t y){
  return glassesArray[y][x];
}

// ---------------------------------------------------- DISPLAY ---------------------------------------------------- \\
// sine wave
void sineDisplay(word &frame, float AMPLITUDE, byte FREQ){
  pixels.clear();
  
  float angle = 0.0;
  byte rowIndex=0;
  for(byte i=0; i<NUMCOLS; i++){
    
    // convert angle to radians
    angle= (((FREQ*i)%360)*71.0)/4068.0;
    double sine = sin(angle)*AMPLITUDE;

    // Peaks
    if(1.0>=sine && sine>=0.8){
      rowIndex = 0;
      // move along the fretboard
      pixels.setPixelColor(glassesArray[rowIndex][(i+frame)%NUMCOLS], pixels.Color(0, 255, 0));
      // static display
      //pixels.setPixelColor(glassesArray[rowIndex][i], pixels.Color(255, 255, 255));
    }
    // Troughs
    else if(-0.8>=sine && sine>=-1.0){
      rowIndex = 5;
      // move along the fretboard
      pixels.setPixelColor(glassesArray[rowIndex][(i+frame)%NUMCOLS], pixels.Color(0, 255, 0));
      // static display
      //pixels.setPixelColor(glassesArray[rowIndex][i], pixels.Color(255, 255, 255));
    }  
    // Middle(s)
    else{
      // top middle
      if(0.79>=sine && sine>=0.49){
        rowIndex = 1;
        // move along the fretboard
        pixels.setPixelColor(glassesArray[rowIndex][(i+frame)%NUMCOLS], pixels.Color(0, 255, 0));
        // static display
        //pixels.setPixelColor(glassesArray[rowIndex][i], pixels.Color(255, 255, 255));
      } 
      // middle top middle     
      if(0.60>=sine && sine>=-0.01){
        rowIndex = 2;
        // move along the fretboard
        pixels.setPixelColor(glassesArray[rowIndex][(i+frame)%NUMCOLS], pixels.Color(0, 255, 0));
        // static display
        //pixels.setPixelColor(glassesArray[rowIndex][i], pixels.Color(255, 255, 255));
      }  
      // middle lower middle    
      if(0.01>=sine && sine>=-0.60){
        rowIndex = 3;
        // move along the fretboard
        pixels.setPixelColor(glassesArray[rowIndex][(i+frame)%NUMCOLS], pixels.Color(0, 255, 0));
        // static display
        //pixels.setPixelColor(glassesArray[rowIndex][i], pixels.Color(255, 255, 255));
      }  
      // lower middle   
      if(-0.49>=sine && sine>=-0.79){
        rowIndex = 4;
        // move along the fretboard
        pixels.setPixelColor(glassesArray[rowIndex][(i+frame)%NUMCOLS], pixels.Color(0, 255, 0));
        // static display
        //pixels.setPixelColor(glassesArray[rowIndex][i], pixels.Color(255, 255, 255));
      }  
    }   
  } 
  pixels.show();
}

// x_coord, y_coord of ball, dir = direction (0 left or down, 1 right or up)
void pong(word &frame, byte &x_coord, byte &y_coord, bool &x_dir, bool &y_dir, byte &red_pad_y, byte &blue_pad_y, byte &red_score, byte &blue_score, bool &scoreFlag, byte &prevFrame){

  //matrix.clear();
  
  // set colour
  setColour(1);
  uint16_t colourBall = matrix.Color(red*brightnessFactor, green*brightnessFactor, blue*brightnessFactor); 
  setColour(2);
  uint16_t redPad = matrix.Color(red*brightnessFactor, green*brightnessFactor, blue*brightnessFactor);
  setColour(4);
  uint16_t bluePad = matrix.Color(red*brightnessFactor, green*brightnessFactor, blue*brightnessFactor);

  if (scoreFlag){
    matrix.clear();

    if(red_score >= 10 || blue_score >= 10){
//      if(red_score == 10){
//              
//      }
//      if(blue_score == 10){
//        
//      }
      
      red_score = 0;
      blue_score = 0;
    }
    
    else if (frame<prevFrame+20){
      matrix.setTextColor(bluePad);
      matrix.setCursor(9, 5);
      matrix.print(blue_score);

      matrix.setTextColor(redPad);
      matrix.setCursor(2, 5);
      matrix.print(red_score);
    }
    else{
      scoreFlag=false;
      prevFrame=0;
    }
  }

  // first call 
  else if (frame<=1){
     // initialise the ball in middle of glasses
     y_coord = random(1, 5);
     x_coord = random(6, 8);
     // flip direction
     x_dir != x_dir;
     y_dir != y_dir;

     // initialise the paddles
     blue_pad_y = 2;
     red_pad_y = 2;

     scoreFlag=true;
     prevFrame = frame;
  }

  else{

    // every subsequent call, move the ball
      // bounce off blue paddle
      if(x_coord == x_upp_lim){
        if((blue_pad_y-1<=y_coord) && (y_coord<=blue_pad_y+1))
           x_dir = x_dir^1;
        else{
           frame=0;
           red_score++;
           matrix.clear();
        }
      }
    
      // bounce off red paddle
      if(x_coord == x_low_lim){
        if((red_pad_y-1<=y_coord) && (y_coord<=red_pad_y+1)){
            x_dir = x_dir^1; 
          }
        else{
         frame=0;
         blue_score++;
         matrix.clear();  
        }
      }
      
      // bounce off top/bottom
      if(y_coord == y_low_lim || y_coord == y_upp_lim){
        y_dir = y_dir^1;
      }
      
      // left movement
      if(!x_dir){
        x_coord--;
      }
      // right movement
      else{
        x_coord++;
      }
      // down movement
      if(!y_dir){
        y_coord++;
      }
      // up movement
      else{
        y_coord--; 
      }
  
    byte blue_pad_rand = random(-1, 2);
    byte red_pad_rand = random(-1, 2);
  
    // paddle movement
    if(y_coord > 1 && y_coord < 4){
      blue_pad_y=y_coord+blue_pad_rand;
      red_pad_y=y_coord+red_pad_rand;    
    }

    matrix.clear();
  
    // draw paddles
    for (byte i=blue_pad_y-1; i <= blue_pad_y+1; i++){
      matrix.drawPixel(13, i, bluePad);
    }
  
    for (byte i=red_pad_y-1; i <= red_pad_y+1; i++){
      matrix.drawPixel(0, i, redPad);
    }
    
    // draw ball
    matrix.drawPixel(x_coord, y_coord, colourBall);
  }
  matrix.show();
  frame++;
}

void rainbow(word &frame){
  long firstPixelHue = frame*256;
  if(firstPixelHue>5*65536){
    firstPixelHue=0;
  }

  for(int i=0; i<pixels.numPixels(); i++) { // For each pixel in strip...
        // Offset pixel hue by an amount to make one full revolution of the
        // color wheel (range of 65536) along the length of the strip
        // (strip.numPixels() steps):
        int pixelHue = firstPixelHue + (i * 65536L / pixels.numPixels());
        // strip.ColorHSV() can take 1 or 3 arguments: a hue (0 to 65535) or
        // optionally add saturation and value (brightness) (each 0 to 255).
        // Here we're using just the single-argument hue variant. The result
        // is passed through strip.gamma32() to provide 'truer' colors
        // before assigning to each pixel:
        pixels.setPixelColor(i, pixels.gamma32(pixels.ColorHSV(pixelHue)));
      }
   pixels.show();
}

void colourWipeFrame(word &frame){
  uint32_t colour;
  
  if(frame == 1){
    newColour=random(0,5);
    if(prevColour!=newColour){
      setColour(newColour); 
      prevColour=newColour; 
    }
    else{
      newColour=random(0,5);
      setColour(newColour);
      prevColour=newColour;
    }
    colour = pixels.Color(red*brightnessFactor, green*brightnessFactor, blue*brightnessFactor);
  }
  
  if(frame > NUMPIXELS){
    // reset animation
    frame = 0;
  }
  
  pixels.setPixelColor(frame-1, colour);
  pixels.show();

}

void fftFcn(){

//  // Green
//  setColour(3);
//  uint16_t colourLow = matrix.Color(red*brightnessFactor, green*brightnessFactor, blue*brightnessFactor);
//  // Red
//  setColour(2);
//  uint16_t colourHigh = matrix.Color(red*brightnessFactor, green*brightnessFactor, blue*brightnessFactor);
    
  // Sampling
  for(byte i=0; i<SAMPLES; i++){
    microseconds = micros();
    int value = analogRead(0);
    vReal[i]=value/8;
    vImag[i]=0;

    while(micros() < (microseconds + sampling_period_us)){
    }
  }

  // FFT
  FFT.Windowing(vReal, SAMPLES, FFT_WIN_TYP_HAMMING, FFT_FORWARD);
  FFT.Compute(vReal, vImag, SAMPLES, FFT_FORWARD);
  FFT.ComplexToMagnitude(vReal, vImag, SAMPLES);
  FFT.DCRemoval();
  //double peak = FFT.MajorPeak(vReal, SAMPLES, SAMPLING_FREQ);

//  for(int i=0; i<(SAMPLES/2); i++)
//    {
//        /*View all these three lines in serial terminal to see which frequencies has which amplitudes*/
//
//        Serial.print((i * 1.0 * SAMPLING_FREQ) / SAMPLES, 1);
//        Serial.print(" ");
//        Serial.println(vReal[i], 1);    //View only this line in serial plotter to visualize the bins
//    }

  // process the values
  int vRealVals[NUMCOLS];
  int avgvReal = 0;
  for(byte i = 2; i<(SAMPLES/2); i++){
    vRealVals[i-2] = vReal[i];
    avgvReal+=vRealVals[i-2];
  }

  avgvReal = avgvReal/NUMCOLS;

  // Display results on Glasses
  for(byte i = 2; i<(SAMPLES/2); i++){
    int displayPeak = map(vReal[i], 0, 40+avgvReal, 0, maxScale);
    displayPeakVals[i-2] = displayPeak;
  }

  for(byte i=0; i<NUMCOLS; i++){
    
    setColour(fftArray[i]);
    uint16_t colour = matrix.Color(red*brightnessFactor, green*brightnessFactor, blue*brightnessFactor);
    
    for(byte j=0; j<=maxScale; j++){
      // clear pixels
      if(j >= displayPeakVals[i]){
        matrix.drawPixel(i, NUMROWS-j, 0);
      }
      // draw in green
      else if (j < redZone){
        matrix.drawPixel(i, NUMROWS-j, colour);
      }
      // red!
      else{
        matrix.drawPixel(i, NUMROWS-j, colour);
      }
    }
  }
 
  //delay(5000); 
}

void volumeScroll(){
  // colour GREEN
  setColour(3);
  uint16_t colourLow = matrix.Color(red*brightnessFactor, green*brightnessFactor, blue*brightnessFactor);
  // colour RED
  setColour(2);
  uint16_t colourHigh = matrix.Color(red*brightnessFactor, green*brightnessFactor, blue*brightnessFactor);

  // millis setup
  unsigned long currentMillis = millis();

  // mic setup
  unsigned int peakToPeak = 0;
  unsigned int signalMax = 0;
  unsigned int signalMin = 1024;

  //
  while( millis() - currentMillis < sampleWindow){
    sample = analogRead(0);
    // toss out spurious readings
    if (sample < 1024){
      if (sample > signalMax){
        signalMax = sample;  // save the max levels
      }
      else if (sample < signalMin){
        signalMin = sample;  // save just the min levels
      }
    }
  }

  // map 1v p-p level to max scale of display
  peakToPeak = signalMax - signalMin;
  int displayPeak = map(peakToPeak, 0, 255, 0, maxScale);

  // save the previous 14 display peaks
  displayPeakVals[buffer_index] = displayPeak;
  buffer_index++;
  if (buffer_index >= buffer_size){
    buffer_index=0;
  }

  for(byte k=0; k<NUMCOLS; k++){
    byte j = (buffer_index + k) % NUMCOLS;
    for (byte i=0; i<=maxScale; i++){

      // blank these pixels
      if(i >= displayPeakVals[j]){
        matrix.drawPixel(k, NUMROWS-i, 0);
      }
      // draw in green
      else if (i < redZone){
        matrix.drawPixel(k, NUMROWS-i, colourLow);
      }
      // red!
      else{
        matrix.drawPixel(k, NUMROWS-i, colourHigh);
      }
    }
  }
  
  matrix.show();

}

void circles(word &frame){

  uint16_t colour;
  
  if(frame == 1){
    setColour(random(2, NUMCOLOURS+1));  
    colour = matrix.Color(red*brightnessFactor, green*brightnessFactor, blue*brightnessFactor);
  }
  
  if(frame%5 == 0){
    // reset animation (circle has reached corner)
    frame = 0;
  }
  
  matrix.fillCircle(3, 3, frame, colour);
  matrix.fillCircle(3+7, 3, frame, colour);
  matrix.show();

  return frame;
}

void upDown (word &frame){
  pixels.clear();
  if (frame >= NUMROWS*2){
    frame = 0;
  }
  if (frame >= NUMROWS){
    lightRow((NUMROWS*2)-frame);
  }
  else{
    lightRow(frame+1);
  }
}

void sideSide (word &frame){
  pixels.clear();
  if (frame >= NUMCOLS*2){
    frame = 0;
  }
  if (frame >= NUMCOLS){
    lightCol((NUMCOLS*2)-frame);
  }
  else{
    lightCol(frame+1);
  }
}

void scanColsRows (word &frame){
  if (frame >=NUMROWS+NUMCOLS){
    frame = 0;
  }
  else if (frame < NUMCOLS){
    scanCols(frame);
  }
  else{
    word rowFrame = frame-NUMCOLS;
    scanRows(rowFrame);
  }
}

void scanRows(word &frame){
  if (frame >= NUMROWS){
    frame=0;
  }
  pixels.clear();
  lightRow(frame+1);
}

void scanCols(word &frame){
  if (frame >= NUMCOLS){
    frame=0;
  }
  pixels.clear();
  lightCol(frame+1);
}
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

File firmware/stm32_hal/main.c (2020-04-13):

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

/* Includes ------------------------------------------------------------------*/
#include "main.h"

SPI_HandleTypeDef hspi1;
DMA_HandleTypeDef hdma_spi1_tx;

UART_HandleTypeDef huart2;

/* USER CODE BEGIN PV */
// 0xCC = "1", 0x88 = "0"
// 0x88 = 1000, 0xCC = 1100
static uint8_t ledArray[12] = {
		0x88, 0x88, 0x88, 0x88, // 1000 1000 1000 1000 | 1000 1000 1000 1000 |
		0x88, 0x88, 0x88, 0x88,	// 1000 1000 1000 1000 | 1000 1000 1000 1000 |
		0x88, 0x88, 0x88, 0x88	// 1000 1000 1000 1000 | 1000 1000 1000 1000 |
};
/* USER CODE END PV */

void SystemClock_Config(void);
static void MX_GPIO_Init(void);
static void MX_DMA_Init(void);
static void MX_USART2_UART_Init(void);
static void MX_SPI1_Init(void);
/**
  * @brief  The application entry point.
  * @retval int
  */
int main(void)
{
  /* MCU Configuration--------------------------------------------------------*/

  /* Reset of all peripherals, Initializes the Flash interface and the Systick. */
  HAL_Init();

  /* Configure the system clock */
  SystemClock_Config();

  /* Initialize all configured peripherals */
  MX_GPIO_Init();
  MX_DMA_Init();
  MX_USART2_UART_Init();
  MX_SPI1_Init();
  /* USER CODE BEGIN 2 */
  // User Generated SETUP code here
  // ALL user generated code to go between these comment guards

  HAL_SPI_Transmit(&hspi1,ledArray, sizeof(ledArray), HAL_MAX_DELAY);

  /* USER CODE END 2 */

  /* Infinite loop */
  /* USER CODE BEGIN WHILE */
  while (1)
  {
	  //HAL_GPIO_WritePin(GPIOA, GPIO_PIN_7, GPIO_PIN_RESET);
	  //HAL_SPI_Transmit(&hspi1, (uint8_t *)ledArray, sizeof(ledArray), HAL_MAX_DELAY);
	  //HAL_GPIO_WritePin(GPIOA, GPIO_PIN_7, GPIO_PIN_SET);

    /* USER CODE END WHILE */

    /* USER CODE BEGIN 3 */
  }
  /* USER CODE END 3 */
}

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


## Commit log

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2019-10-12 PCB
    Moved cutout to the appropriate layer
    [LED Glasses v2.kicad_pcb]
2019-10-13 Update LED Glasses v2.kicad_pcb
    Updated PCB design files to use power and ground planes rather than traced connections
    [LED Glasses v2.kicad_pcb]
2019-10-19 Moved left breakout pads
    [LED Glasses v2.kicad_pcb]
2019-10-19 Moved left breakout pads x2
    [LED Glasses v2.kicad_pcb]
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2019-10-20 moved logo to back silkscreen
    [LED Glasses v2-B.Cu.gbr, LED Glasses v2-B.Mask.gbr, LED Glasses v2-B.SilkS.gbr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]
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2019-12-18 18-12-2019
    Added sine display
    [sine wave calcs.xlsx]
2020-02-17 Glasses Arm Initial upload
    [LED Glasses Arm Board.kicad_pcb, LED Glasses Arm Board.sch, LED Left Glasses Arm (mcu).kicad_pcb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]
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2020-03-22 messing around with the MCU
    [LED Left Glasses Arm (mcu).kicad_pcb, LED Left Glasses Arm (mcu).sch]
2020-03-30 Added misc-symbols library + symbols for uC and mic. Started on mcu arm schematic.
    [LED Left Glasses Arm (mcu).sch]
2020-04-04 Finished MCU arm schematic, digi-key product numbers chosen for all components. Next up is to create/assign footprint and begin layout.
    [LED Left Glasses Arm (mcu).sch]
2020-04-13 added libraries + STM32 code
    [LED Left Glasses Arm (mcu).sch]
2020-04-29 Assigning footprints to mcu arm schematic.
    [LED Left Glasses Arm (mcu).sch]
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2020-05-03 added footprints to the PCB
    [LED Left Glasses Arm (mcu).kicad_pcb, LED Left Glasses Arm (mcu).sch]
2020-05-09 footprints in misc-footprints library
    [LED Left Glasses Arm (mcu).kicad_pcb]
2020-05-09 moved outline to edge cuts layer and removed extra lines
    [LED Left Glasses Arm (mcu).kicad_pcb, _saved_LED Left Glasses Arm (mcu).sch]
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2020-05-11 Create _saved_LED Left Glasses Arm (mcu).sch
    [_saved_LED Left Glasses Arm (mcu).sch]
2020-05-11 moved components around on mcu arm
    [LED Left Glasses Arm (mcu).kicad_pcb, _saved_LED Left Glasses Arm (mcu).sch]
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2020-05-12 need to reroute but got the basic layout
    [LED Left Glasses Arm (mcu).kicad_pcb, LED Left Glasses Arm (mcu).sch, _saved_LED Left Glasses Arm (mcu).sch]
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2020-05-14 various changes made to mcu pcb
    [LED Left Glasses Arm (mcu).kicad_pcb, LED Left Glasses Arm (mcu).sch]
2020-05-14 finished off the mcu arm pcb
    [LED Left Glasses Arm (mcu).kicad_pcb, LED Left Glasses Arm (mcu).sch]
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2020-10-08 updated
    added polarity protection
    [LED Right Glasses Arm (power).sch]
2020-10-20 Started on the PCB
    [LED Right Glasses Arm (power).kicad_pcb, LED Right Glasses Arm (power).sch]
2021-03-14 Finalising sch and board layout
    Added in JST connector for battery pack and pin connectors for the glasses side. Prelim board layout
    [LED Right Glasses Arm (power).kicad_pcb, LED Right Glasses Arm (power).sch]
2021-03-15 sch revs
    added 1000uF cap, slide switch and changed caps to parallel. need to change mosfet and do footprint for cap
    [LED Right Glasses Arm (power).kicad_pcb, LED Right Glasses Arm (power).sch]
2021-03-20 PCB update
    Changed mosfet, started to route signals
    [LED Right Glasses Arm (power).kicad_pcb, LED Right Glasses Arm (power).sch]
2021-03-29 added a few more links to products
    [LED Right Glasses Arm (power).sch]
2021-04-04 added parts for caps
    [LED Right Glasses Arm (power).kicad_pcb, LED Right Glasses Arm (power).sch]
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2021-04-20 Changes
    Test points, routing, need to get the ground plane on the back copper
    [LED Right Glasses Arm (power).kicad_pcb, LED Right Glasses Arm (power).sch]
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2021-04-25 Made a few small cosmetic changes to labels and values (i.e. R_small_US1 to R1).
    [LED Right Glasses Arm (power).kicad_pcb, LED Right Glasses Arm (power).sch]
2021-04-28 All changes apply to schematic only and not to the layout. Removed external feedback loop, replaced bulk output capacitance with 3x22uF caps for cost savings and removed led indicator on input power.
    [LED Right Glasses Arm (power).sch]
2021-05-03 Changed LED indicator from 5V out to PG from power reg IC, moved annotation from 0-x to 100-1xx to keep it consistent with mcu arm design, adjusted layout to accomodate schematic changes from this co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
    [LED Right Glasses Arm (power).kicad_pcb, LED Right Glasses Arm (power).sch]
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2021-06-06 Made major structural changes to folder layout. Went through kicad projects and updated references so they should all be correct. Updated readme.
    [BOM.csv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]
2021-06-13 Started on reworked firmware in firmware/rave_shades using vscode and the libopencm3 framework. Firmware is correctly reading from microphone and displaying to LEDs.
    [led.c, main.c, mic.c]
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2021-08-24 Refined heart animation, add fixed precision Fourier transform (Goertzel algorithm), centred decimation filter output on 0, LED buffer now flushed with DMA, simplified main loop, cleaned up compiler 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
    [button.c, led.c]
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2021-09-14 Button now runs on timer interrupt (much more performant). A few other minor changes to comments and compiler warning fixes.
    [button.c, mic.c]
2022-05-31 Completely revamped how audio data is processed, raw mic readings are DMA'ed into a buffer for being filtered+downsampled. This is now significantly more performant, allowing enough time to processin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
    [button.c]
2022-09-23 Migrated hardware files to KiCAD v6, restructured and started work on new designs.
    Migrated KiCAD files to v6, restructured to better accommodate new hardware designs (multiple parallel types and revisions of the controller arm etc,) and started work on new designs (e.g. controller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
    [arm_mcu.kicad_pcb, arm_mcu.sch, arm_power.kicad_pcb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]
2022-10-01 Made some more progress on the schematic of the second revision of the power board.
    [power_r2.kicad_sch]
2022-12-14 Added templates for new board outlines (type B rev 1), completed most of controller_b_r1 schematic and moved onto the layout.
    [arm_template.kicad_pcb, controller_b_r1.kicad_pcb, controller_b_r1.kicad_sch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]
2022-12-15 Refined schematic and layout:
    - Removed some caps from the user buttons, mcu reset and power reg enable because datasheets/example designs didn't have them (hopefully I don't regret it).
    - Removed pullups from the user buttons because I can use the RP2040 GPIO internal pullups.
    - Changed a few res values to simplify the BOM.
    [controller_b_r1.kicad_pcb, controller_b_r1.kicad_sch, stocktake_2022_09_15.ods]
2022-12-20 Controller board is pretty much done. USB impedance will need to be tweaked and DRC checks done once a PCB fab is decided on. Having all the serial interfaces routed from the same side (the top) of t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
    [controller_b_r1.kicad_pcb, controller_b_r1.kicad_sch]
2022-12-28 Display board layout is now 95% complete, the number of caps on the board might need some further tweaking and there are also some gaps where a few more LEDs could fit. Additionally I've decided to p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
    [controller_b_r1.kicad_pcb, controller_b_r1.kicad_sch, display_b_r1.kicad_pcb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]
2023-03-09 First pass at the rev 2 power board.
    Only did copper layers on the power board so far. Waiting to decide on a PCB fab house then I'll go back and make sure it's compliant (looking mostly at how close I can pack vias). Starting on the nucleo programmer shield next. Added a voltage divider to the enable pin on the 3V3 vreg on the controller board so it only switches on when there is enough input voltage for correct 3V3 output. I did this because I read somewhere that the RP2040 can power on at a lower voltage than a lot of flash chips and if that happens it gets into a weird state so I'm trying to make sure 3V3 comes on as quickly and sharply as possible.
    [controller_b_r1.kicad_pcb, controller_b_r1.kicad_sch, power_r2.kicad_pcb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]
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2023-03-15 Added some extra comments to the input power protection stuff.
    [power_r2.kicad_sch]
2023-04-04 Next revision of the boards are finished and ready for fabrication, and a BOM has been added.
    The BOM is still missing components for the nucleo shield.
    [bom_2023_04_02.ods, controller_b_r1.kicad_pcb, controller_b_r1.kicad_sch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]
2024-04-07 Updated kicad files to work with latest kicad. Added some todos for next hw design.
    [bom_2023_04_02.ods, controller_a_r1.kicad_pcb, controller_a_r1.kicad_sch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]

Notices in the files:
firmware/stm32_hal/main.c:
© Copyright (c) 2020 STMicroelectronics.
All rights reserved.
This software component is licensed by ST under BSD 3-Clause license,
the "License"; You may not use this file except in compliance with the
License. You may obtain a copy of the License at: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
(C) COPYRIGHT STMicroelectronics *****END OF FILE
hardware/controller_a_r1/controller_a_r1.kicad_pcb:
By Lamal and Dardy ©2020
